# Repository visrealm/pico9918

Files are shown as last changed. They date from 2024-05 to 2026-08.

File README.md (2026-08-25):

# PICO9918

A drop-in replacement for a classic TMS9918A VDP powered by the Raspberry Pi Pico RP2040 (and RP2350) microcontroller.

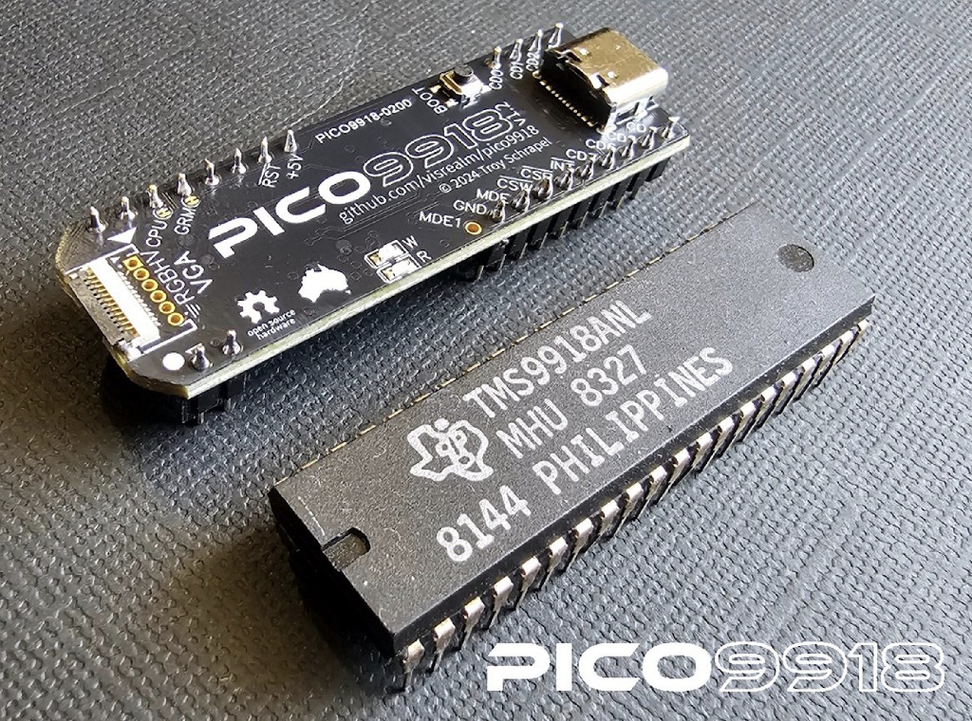
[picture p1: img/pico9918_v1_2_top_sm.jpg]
PICO9918 v1.2 Top
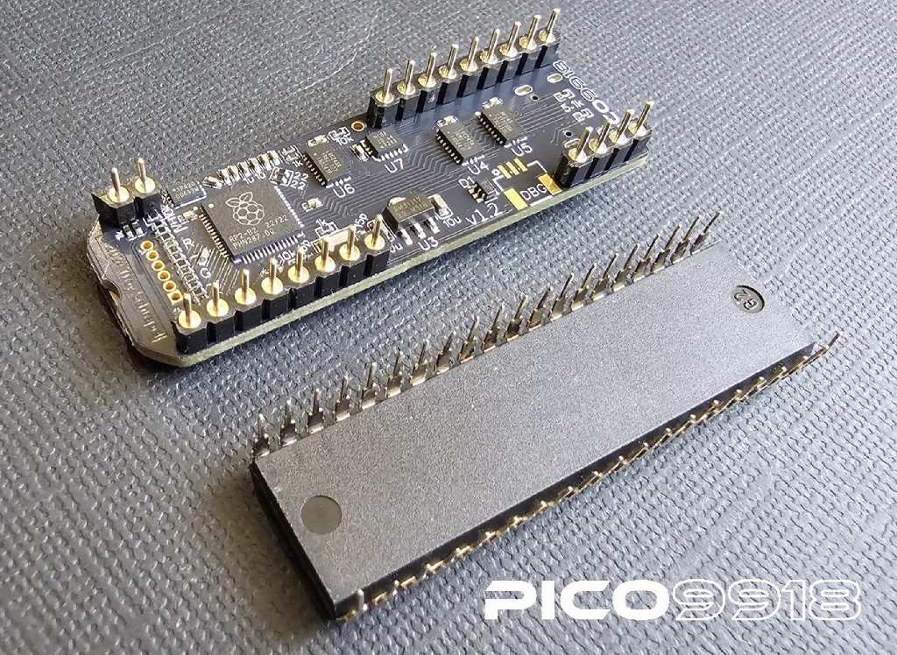
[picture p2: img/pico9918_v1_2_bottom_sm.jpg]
PICO9918 v1.2 Top
<p align="left"> </p>

The PICO9918 PRO can replace all classic VDP models (TMS9918, TMS9918A, TMS9928A, TMS9929A, TMS9118, TMS9128, TMS9129), providing a crisp VGA, HDMI or SCART RGB signal from your retrocomputer.

The PICO9918 has been tested on over 30 classic models of TI-99, Coleco, MSX, NABU, Memotech, Sega and many more. See the [full list below](#supported-devices).

The TMS9918A emulation is handled by my [vrEmuTms9918 library](https://github.com/visrealm/vrEmuTms9918) which is included as a submodule here.

## Contents

* [Supported devices](#supported-devices)
* [Video output](#video-output)
* [F18A compatibility](#f18a-compatibility)
* [Purchasing options](#purchasing-options)
* [Hardware](#hardware)
* [Firmware](#firmware)
* [Configurator](#configurator)
* [Roadmap](#roadmap)
* [Documentation](#documentation)
* [Building](#building)
* [Thanks](#thanks)
* [Discussion](#discussion)
* [Videos](#videos)
* [Licensing](#licensing)

## Supported devices

Every machine below has been tested and confirmed working. Each family has a wiki page with per-model notes, installation tips and configurator support.

| Family | Machines tested | Wiki page |
|---|---|---|
| [Texas Instruments TI-99](https://en.wikipedia.org/wiki/TI-99/4A) | TI-99/4, TI-99/4A, TI-99/4QI, TI-99/22 | [All models](https://github.com/visrealm/pico9918/wiki/Texas-Instruments-TI‐99) |
| [MSX](https://en.wikipedia.org/wiki/MSX) | 14 models from Casio, Gradiente, National, Sanyo, Sharp, Sony, Spectravideo, Toshiba and Yamaha | [All models](https://github.com/visrealm/pico9918/wiki/MSX) |
| [ColecoVision](https://en.wikipedia.org/wiki/ColecoVision) | ColecoVision, Coleco ADAM, AtariBits CV-NUC+, Bit Dina 2 in one | [All models](https://github.com/visrealm/pico9918/wiki/ColecoVision) |
| [Sega SG-1000](https://en.wikipedia.org/wiki/SG-1000#SC-3000) | SG-1000, SG-1000 II, SC-3000 | [All models](https://github.com/visrealm/pico9918/wiki/Sega-SG‐1000) |
| [Tomy Tutor](https://en.wikipedia.org/wiki/Tomy_Tutor) | Tomy Tutor, Pyūta, Pyūta Jr | [All models](https://github.com/visrealm/pico9918/wiki/Tomy-Tutor) |
| [VTech CreatiVision](https://en.wikipedia.org/wiki/VTech_CreatiVision) | CreatiVision, Dick Smith Wizzard | [All models](https://github.com/visrealm/pico9918/wiki/CreatiVision) |
| [NABU Personal Computer](https://en.wikipedia.org/wiki/NABU_Network) | NABU PC | [All models](https://github.com/visrealm/pico9918/wiki/NABU-Personal-Computer) |
| [Memotech MTX](https://en.wikipedia.org/wiki/Memotech_MTX) | MTX500 | [All models](https://github.com/visrealm/pico9918/wiki/Memotech-MTX) |
| [Sord M5](https://en.wikipedia.org/wiki/Sord_M5) | Sord M5 | [All models](https://github.com/visrealm/pico9918/wiki/Sord-M5) |
| [Powertran Cortex](http://powertrancortex.com/) | Cortex | [All models](https://github.com/visrealm/pico9918/wiki/Powertran-Cortex) |
| Homebrew | Troy Schrapel's [HBC-56](https://github.com/visrealm/hbc-56), Stuart Connor's [TM990](http://www.stuartconner.me.uk/tm990/tm990.htm), John Winans' [Z80-Retro](https://github.com/Z80-Retro), Martin's [Z80Ardu](https://www.dev-tronic.de/?p=74) | [All projects](https://github.com/visrealm/pico9918/wiki/Homebrew-Projects) |

Any other machine using a TMS9918, TMS9918A, TMS9928A, TMS9929A, TMS9118, TMS9128 or TMS9129 in a standard 40-pin DIP socket should also work. There are no known unsupported devices. If you have tested the PICO9918 on a machine that isn't listed, please let me know and I'll happily add it. :)

See the [Supported Devices](https://github.com/visrealm/pico9918/wiki/Supported-Devices) wiki page for the full breakdown, including which VDP each machine shipped with.

## Video output

One video pipeline, three ways out. Which one you get depends on the dongle you fit, and all three use the same 12-pin FFC cable, so one cable serves whichever dongle you have on.

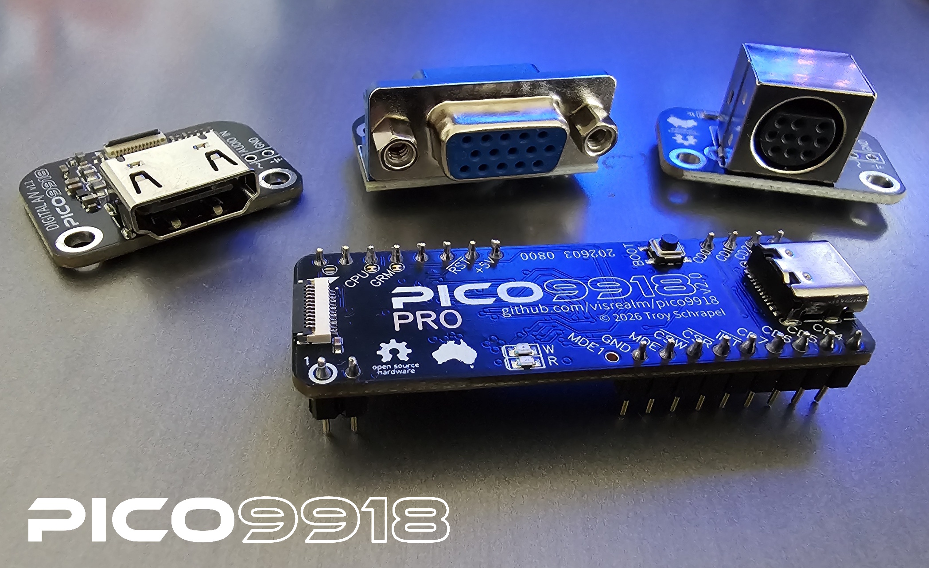
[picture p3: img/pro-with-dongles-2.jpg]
PICO9918 PRO with the Digital A/V, VGA and SCART RGB A/V dongles
<p align="left"></p>

| Output | Dongle | Signal | Audio |
|---|---|---|---|
| **VGA** | [VGA dongle](https://github.com/visrealm/pico9918/wiki/VGA-Dongle) (the default) | 640x480 @ 60 Hz progressive | No |
| **HDMI** | [Digital A/V dongle](https://github.com/visrealm/pico9918/wiki/Digital-AV-(HDMI)-Dongle) | 640x480 @ 60 Hz progressive | Yes, via two wires to the host mainboard |
| **SCART RGB** | [SCART A/V dongle](https://github.com/visrealm/pico9918/wiki/SCART-RGB-AV-Dongle) | PAL 576i @ 50 Hz, or NTSC 480i @ 60 Hz | Yes, via two wires to the host mainboard |

All three dongles fit any FFC-equipped board: **PRO v2.0**, **v1.3** and **v1.2**. On earlier integrated boards (v0.4 to v1.1) VGA comes off a 6-pin JST header on the board itself, and v0.3 has its own VGA breakout.

Nothing needs configuring for VGA or HDMI. A SCART dongle is detected automatically.

> [!NOTE]
> The SCART probe runs once, at boot, before video starts. Swapping dongles on a powered board will not change the output, so power the host off first.

See the [Display Output](https://github.com/visrealm/pico9918/wiki/Display-Output) wiki page for how the driver is chosen, how to change it safely, and the SCART timing details. For fitting the cable, see [Hardware Setup](https://github.com/visrealm/pico9918/wiki/Hardware-Setup#ffc-connector).

### No-cut installation

Every dongle needs a route out of the case. No-cut mods provide one without permanently modifying the machine, using 3D-printed parts and, on the TI-99/4A, a small PCB that replaces the original A/V DIN socket. Kits exist for the [TI-99/4A](https://github.com/visrealm/pico9918/wiki/TI‐99∕4A-No‐Cut-Mod), the CreatiVision and the NABU. STLs, gerbers and fitting photos are in [/nocut](nocut).

## F18A compatibility

The PICO9918 also includes F18A compatibility in firmware v1.0.0+. The video below was captured directly from the PICO9918 VGA output running various F18A demos on a TI-99/4A.

PICO9918 F18A mode preview 1 demo (https://youtu.be/TabTIPL1xQY)

For technical details on the enhanced registers, ECM, GPU, and palette RAM, see the [F18A Programmer's Reference](https://github.com/visrealm/pico9918/wiki/F18A-Programmers-Reference) wiki page.

## Purchasing options

Fully assembled and tested PICO9918 PROs are available here:

| Link | Store | Best For |
|---|---|---|
|  | Lectronz (visrealm) | All regions. Best choice for EU |
|  | Tindie (visrealm) | All regions |
|  | Arcade Shopper | US |

## Hardware

There are three main variants of the hardware.

### PRO v2.x (v2.0)

This is the latest version, powered by the more powerful RP2350. This hardware upgrade will allow for additional VRAM and display modes in the future, including V9938 support.

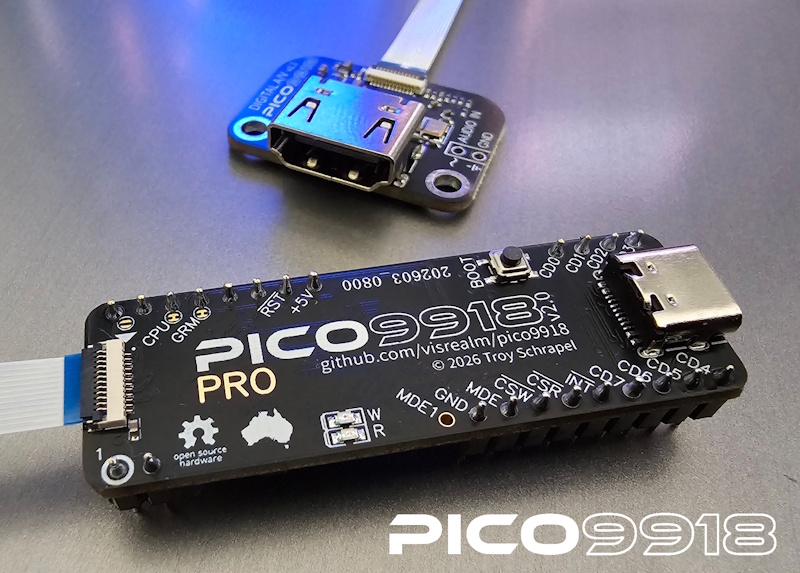
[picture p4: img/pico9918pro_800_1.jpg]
PICO9918 PRO v2.0
<p align="left"></p>

This is the version you can currently buy pre-assembled from Tindie and ArcadeShopper.

### v1.x (v1.3, v1.2, v1.1, v1.0 and v0.4)

PICO9918 v1.3 was the first single board version which doesn't require a piggy-backed Pi Pico.

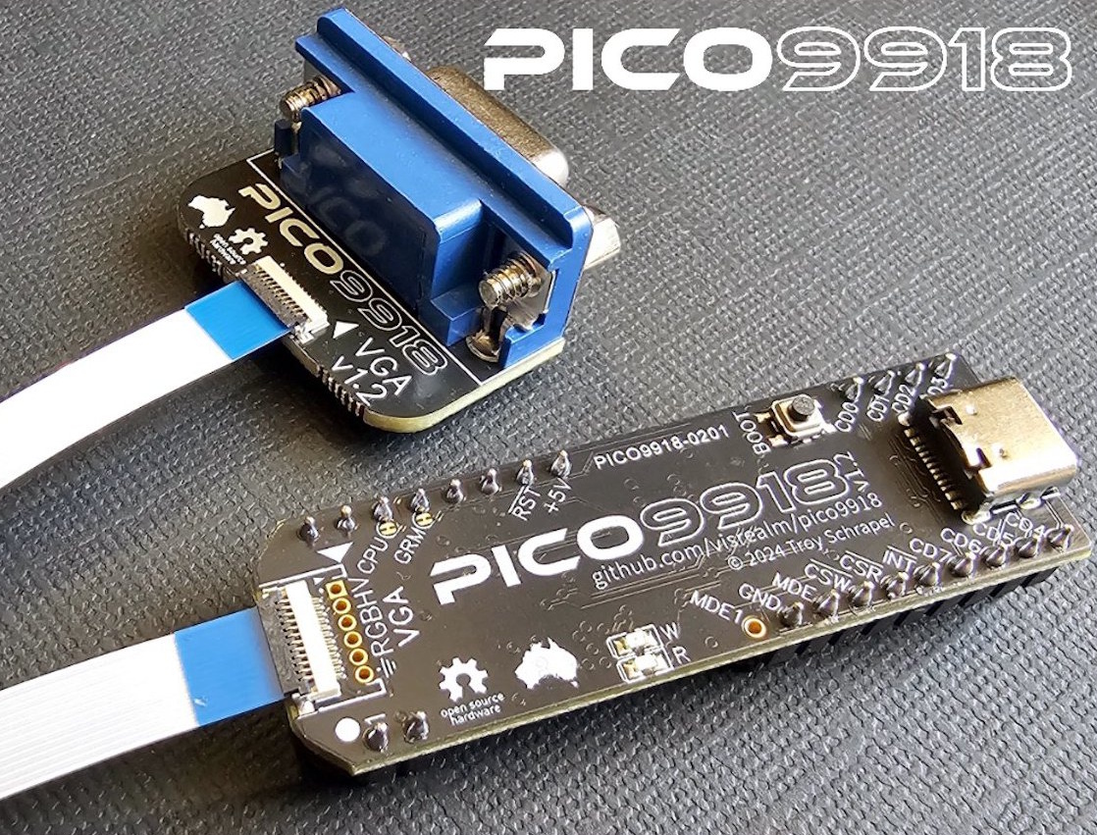
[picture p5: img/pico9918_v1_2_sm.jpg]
PICO9918 v1.2
<p align="left"></p>

### v0.3

v0.3 is relatively cheap and easy to build, schematic and gerbers are available. This version makes use of an external Pi Pico module piggy-backed onto the PICO9918 PCB.

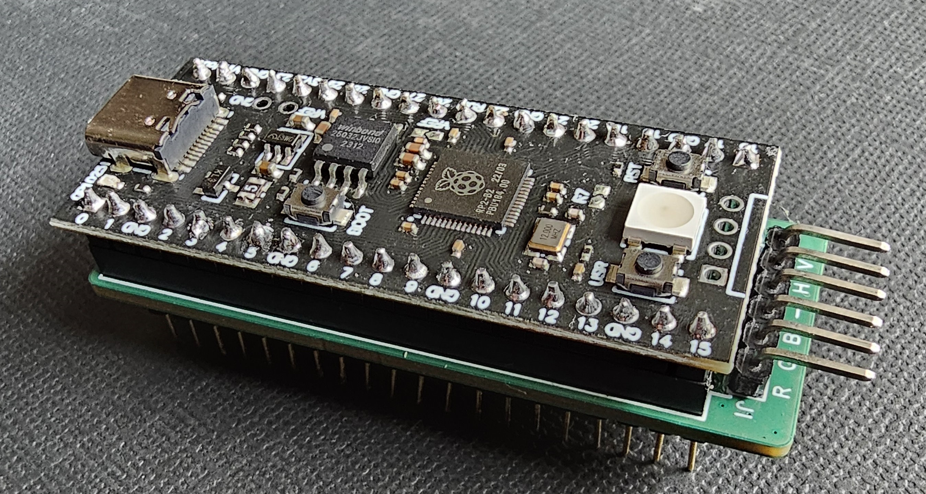
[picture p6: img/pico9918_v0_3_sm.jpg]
PICO9918 v0.3
<p align="left"></p>

I also have the [v0.3 board as a PCBWay Project](https://www.pcbway.com/project/shareproject/PICO9918_Drop_in_replacement_for_the_classic_TMS9918A_family_of_VDPs_fc11359a.html) you can order there.

For detailed specifications and setup instructions, see the [Hardware](https://github.com/visrealm/pico9918/wiki/Hardware) and [Hardware Setup](https://github.com/visrealm/pico9918/wiki/Hardware-Setup) wiki pages.

### Schematics

Schematics and Gerbers are available in [/pcb](pcb)

## Firmware

If you're not interested in building the firmware yourself, you'll find the latest firmware in the [Releases](https://github.com/visrealm/pico9918/releases).

To install, just hold the 'BOOT' button while plugging the Pico into a PC, then drag the pico9918.uf2 file on to the new USB drive which should have the volume label RPI-RP2. The Pico will restart (and disconnect) automatically.

For detailed information on firmware installation, output modes, and updates, see the [Firmware](https://github.com/visrealm/pico9918/wiki/Firmware) wiki page. For what changed in each release, see [CHANGELOG.md](CHANGELOG.md).

## Configurator

The configurator is a software tool used to modify PICO9918 configuration options, including:

* Clock rate
* Scanline CRT effect
* Scanline sprite limit
* Default palette
* [Diagnostic overlays](https://github.com/visrealm/pico9918/wiki/Diagnostic-Overlays)

Additionally, firmware updates can be provided via the Configurator. The full configurator is available for the **TI-99/4A**, **ColecoVision** and **MSX**. With cut-down builds (without firmware updates) available for several other machines.

For full details, see the [Configurator](https://github.com/visrealm/pico9918/wiki/Configurator) wiki page.

See the configurator in action:

PICO9918 Configurator - ColecoVision (https://youtu.be/PBArYupT9qM?t=9)

The configurator was written in a [custom fork of CVBasic](https://github.com/visrealm/CVBasic) with the full source available in [/configtool](configtool).

If you're not interested in building the configurator yourself, you'll find the latest builds in the [Releases](https://github.com/visrealm/pico9918/releases).

### Web-based Configurator

> [!TIP]
> No native configurator for your machine? The [Web-based PICO9918 Configurator](https://visrealm.github.io/pico9918/config/index.html) generates a config .uf2 file for both the PICO9918 and PICO9918 PRO. Drag and drop it onto your device the same way you would a firmware update.

## Roadmap

[ROADMAP.md](ROADMAP.md) sets out what is planned for the firmware and roughly in what order: host bus timing and compatibility fixes in v1.2.1, a rewritten tile pipeline and the extraction of the rendering core into a reusable library in v1.3.0, the remaining F18A behaviour gaps in v1.4.0, and V9938 support in v2.0.0. It also spells out what the version numbers mean, in particular that the configuration layout never changes on a patch release.

It is a direction rather than a commitment, and it deliberately carries no dates - items move between versions as work lands. Anything not listed is unscheduled rather than rejected, so if there is something you would like to see, open an issue and it can be considered. For what has already shipped, see [CHANGELOG.md](CHANGELOG.md).

## Documentation

Just fitted a board? Start with [Getting Started](https://github.com/visrealm/pico9918/wiki/Getting-Started). For everything else, covering hardware setup, firmware, the configurator, supported devices, F18A compatibility and more, visit the **[PICO9918 Wiki](https://github.com/visrealm/pico9918/wiki)**.

## Building

### Quick start
Build both firmware and configurator ROMs:

```bash
# Automatic SDK download (recommended)
mkdir build && cd build
cmake .. -DPICO_SDK_FETCH_FROM_GIT=ON -DPICO_SDK_FETCH_FROM_GIT_TAG=2.1.1
cmake --build .
```

Output in `build/dist/`: firmware `.uf2` file and configurator ROMs for all retro platforms.

Build settings can be overridden with `-D` flags or an optional, git-ignored `pico9918_config.cmake` in the project root - copy [`pico9918_config.cmake.template`](pico9918_config.cmake.template) to `pico9918_config.cmake` and edit it to get started. See [BUILDING.md](BUILDING.md).

### Platform-Specific Setup Required

Each platform requires specific toolchain installation:
- **Windows**: ARM GNU Toolchain 13.2.1-1.1, Python with pillow
- **Linux**: `build-essential cmake python3 python3-pip git gcc-arm-none-eabi`  
- **macOS**: Homebrew + ARM GNU Toolchain 13.2.1-1.1, may need `--break-system-packages`

All platforms use **Raspberry Pi Pico SDK 2.1.1** specifically (newer versions may cause issues).

### Detailed instructions

For detailed platform setup, development environment configuration, build options, individual platform builds, VSCode integration, and troubleshooting, see [BUILDING.md](BUILDING.md)

### Build status

| Branch | Build | Windows | Linux | macOS |
|---|---|---|---|---|
| main | Firmware |  |  |  |
| main | Configurator |  |  |  |
| dev | Firmware |  |  |  |
| dev | Configurator |  |  |  |

## Thanks

Special thanks to [JasonACT (AtariAge)](https://forums.atariage.com/profile/82586-jasonact/) for hand-crafting the F18A mode's on-board TMS9900 "GPU" in ARM assembly and providing other valuable input to the project.

## Discussion

For all the latest news and discussion on the PICO9918, you can follow [this AtariAge thread](https://forums.atariage.com/topic/367656-introducing-the-pico9918-a-tms9918a-drop-in-replacement-powered-by-a-pi-pico/)

## Videos

<details>
<summary><b>Early prototype videos</b> - the first boots, v0.2 through v0.4</summary>

The first three were recorded in the moments following the first boot on my TI-99/4A. They show v0.2 hardware, which needed an external Pi Pico to supply the TI-99's GROMCLK signal - that signal moved onto the board itself in v0.3.

### It freaking works!
PICO9918 Prototype - It freaking works (https://youtu.be/Ri09dCjWxGE)

### Don't mess with Texas!
PICO9918 Prototype - Don't mess with Texas (https://youtu.be/ljNRFKbOGJs)

### 80 column mode
PICO9918 Prototype - 80 column mode test (https://youtu.be/qdCapu0CVJ8)

### v0.4 prototype working!
The first single board version, with the RP2040 integrated.

PICO9918 v0.4 PCB. Integrated RP2040 all-in-one build. (https://youtu.be/KSbJnAwclQw)

</details>

## Licensing

### Hardware
The hardware design files in this repository are licensed under the CERN-OHL-S. See [LICENSE_HARDWARE.md](LICENSE_HARDWARE.md) for details.

### Firmware
The firmware code in this repository is licensed under the MIT License. See [LICENSE_FIRMWARE.md](LICENSE_FIRMWARE.md) for details.

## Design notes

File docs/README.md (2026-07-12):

# PICO9918 Documentation

[&larr; Back to PICO9918](../README.md)

## Contents

* [FFC Connector](#ffc-connector)
* [CPU and GRM Jumpers](#cpu-and-grm-jumper)
* [MDE1 Pin](#mde1-pin)

---

## FFC Connector

The FFC (Flat Flexible Cable) connector on the PICO9918 v1.2+ is used to attach accessories such as the VGA or [Digital A/V dongle](../README.md#digital-av-hdmi-dongle-new).

If you're ordering replacement cables from a thirdparty, look for 12 pin 0.5mm pitch FFC cables.

### Connecting the FFC Cable

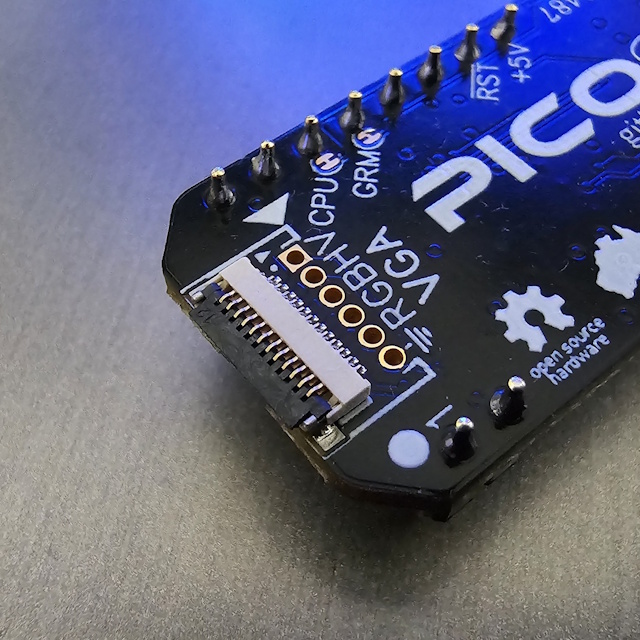
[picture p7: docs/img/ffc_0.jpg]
FFC connector - open latch


**Step 1** - Open the FFC connector latch by lifting the locking tab upward.

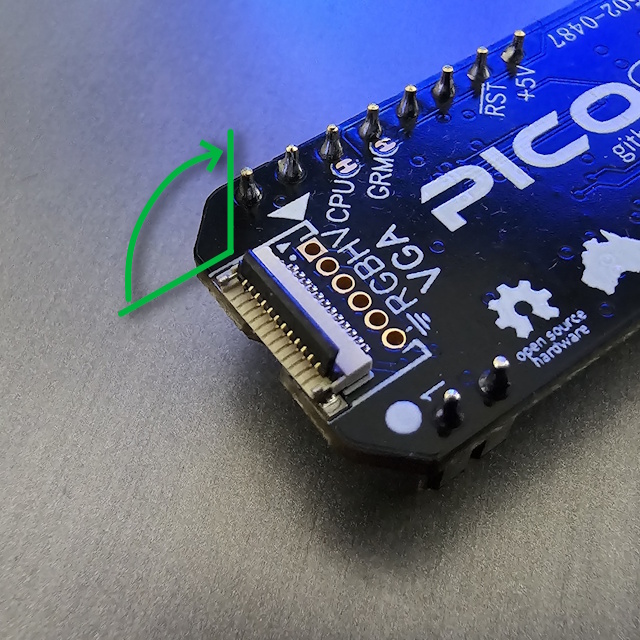
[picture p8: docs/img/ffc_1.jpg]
FFC connector - insert cable


**Step 2** - Insert the FFC cable into the connector with the contacts facing down.

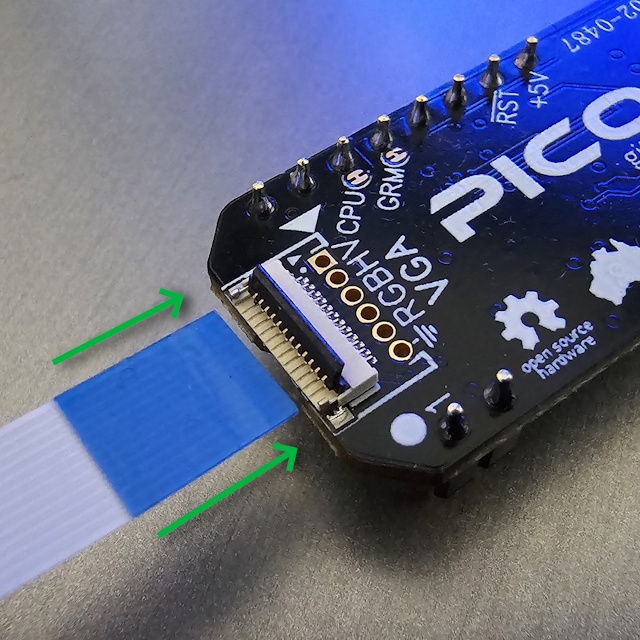
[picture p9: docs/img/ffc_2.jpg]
FFC connector - cable seated


**Step 3** - Push the cable fully into the connector until it seats flush.

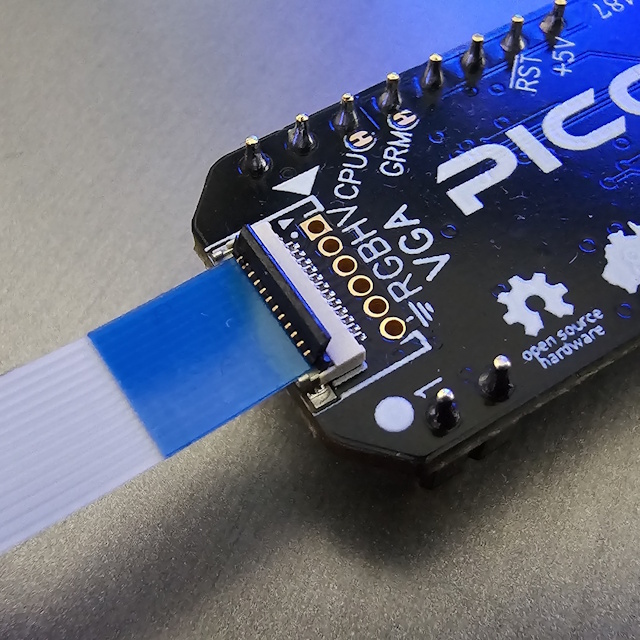
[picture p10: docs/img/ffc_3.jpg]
FFC connector - close latch


**Step 4** - Close the latch by pressing the locking tab back down until it clicks.

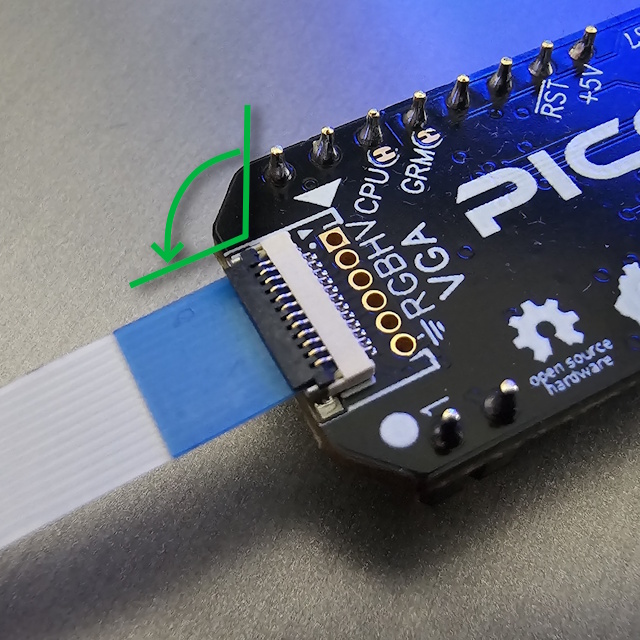
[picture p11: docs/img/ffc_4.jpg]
FFC connector - secured


**Step 5** - Confirm the cable is secure and the latch is fully closed.

---

## CPU and GRM Jumper

The PICO9918 v1.x boards include solder jumpers for configuring the CPU clock and GRM clock outputs. In some cases, it might be necessary to cut  the CPU jumper to ensure compativility with TMS992xA devices. One example being to use the ColecoVision Expansion module 1 with your ColecoVision.

### Cutting a jumper

The CPUCLK and GROMCLK jumpers are located on the board as shown below.

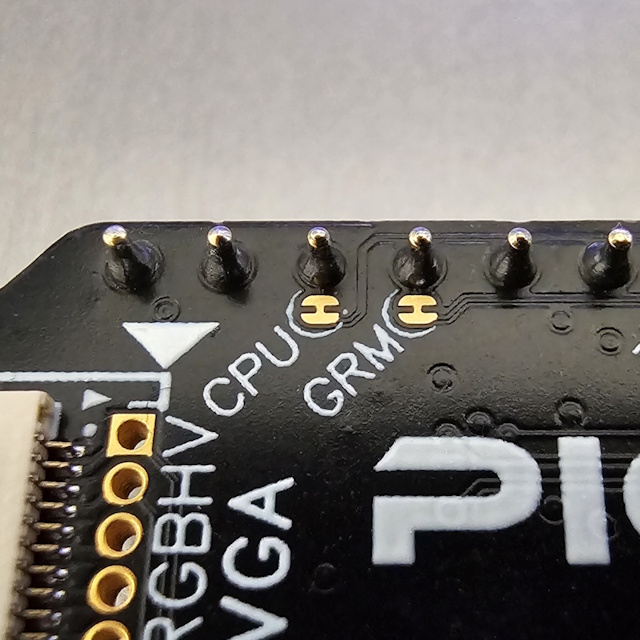
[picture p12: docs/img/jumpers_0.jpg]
PICO9918 jumpers


Using a sharp hobby knife, position the blade across the jumper trace you wish to cut.

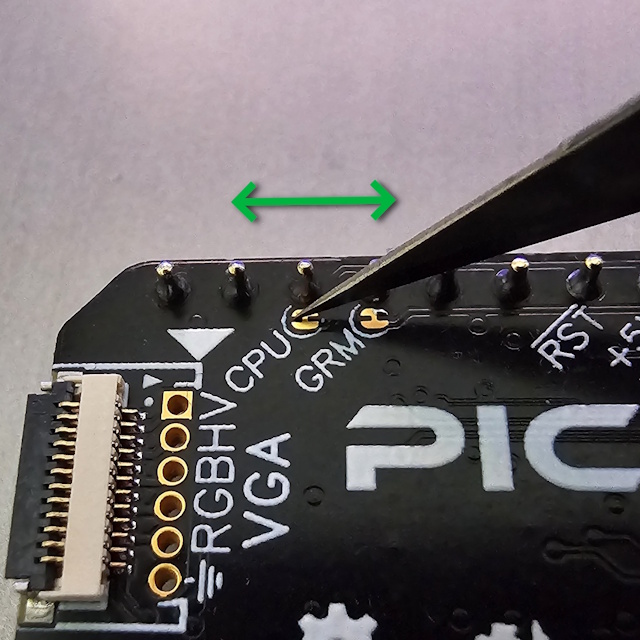
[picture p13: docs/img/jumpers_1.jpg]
Blade positioned against jumper


Apply firm pressure to cut through the trace. Use a multimeter to confirm the jumper is fully open.

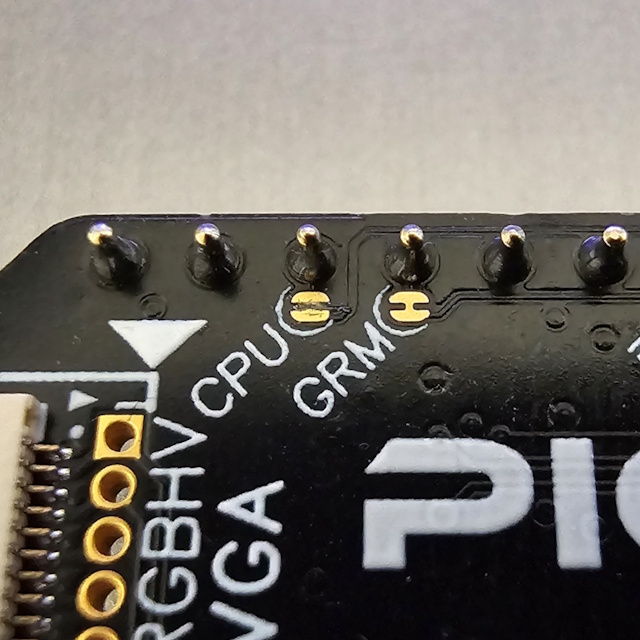
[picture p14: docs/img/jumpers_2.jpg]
Cut jumper


### Replacing a jumper

To re-connect a cut jumper, apply a small solder blob onto the pad.

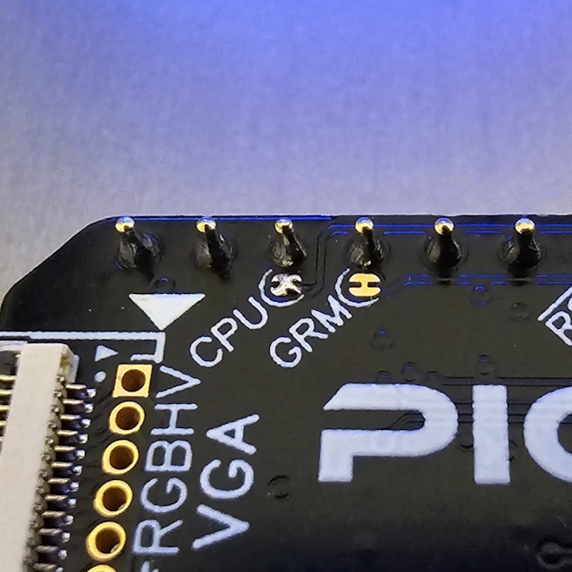
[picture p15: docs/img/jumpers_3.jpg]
Replaced jumper


---

## MDE1 Pin

One side of the PICO9918 v1.x includes 10 holes, but shipped units come with a 9-pin header installed. The unpopulated hole is reserved for the **MDE1** (Mode 1) pin.

MDE1 is not currently used by the firmware but is included on the board for future expansion - for example, to support V9938 and other enhanced VDP variants which make use of this pin.

---

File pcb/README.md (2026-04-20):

# PICO9918 PCBs

Here you will find schematics and gerbers for all working revisions of the PICO9918. There are three main variants of the hardware. 

### DIY Piggybacked board (v0.3)

This version is relatively cheap and easy to build and is powered by a piggybacked Pi Pico USB-C module. Recommended for a DIY project.

<p align="left">PICO9918 v0.3</p>

See [PICO9918 v0.3](v0.3)

### Fully integrated RP2040 single board (v0.4 - v1.3)

From v0.4 the RP2040 has been integrated onto the PICO9918 PCB, making a much smaller small form factor. This revision has many small (0402) components and can be challenging (and more expensive) to build. They can be purchased too.

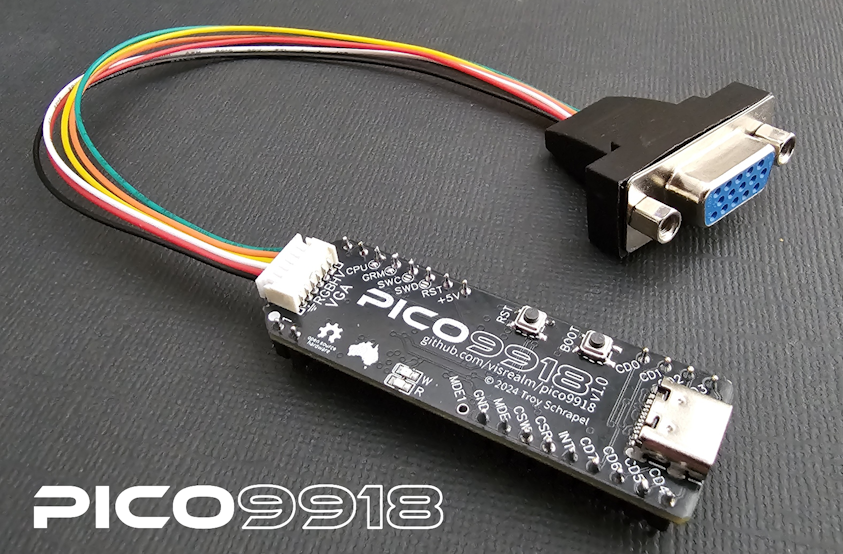
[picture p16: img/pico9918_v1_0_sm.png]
PICO9918 v1.0
<p align="left"></p>

### Fully integrated RP2350 single board (PRO v2.0+)

With the introduction of the RP2350, the PICO9918 v2.0 "PRO" was produced to take advantage of the much improved instruction set.

For a detailed changelog covering all versions, see the [revision history](#revision-history) below.

# Dongles

From v1.2 onwards, the PICO9918 exposes its video output over a 12-pin FFC interface, allowing different output dongles to be connected.

<p align="left"><a href="../img/pro-with-dongles-2.jpg">PICO9918 PRO with dongles</a></p>

## [VGA dongle v1.2](vga)

The standard VGA output dongle. Provides a DE-15 VGA connector.

## [HDMI dongle v1.1](hdmi)

Digital AV dongle providing HDMI output with optional audio.

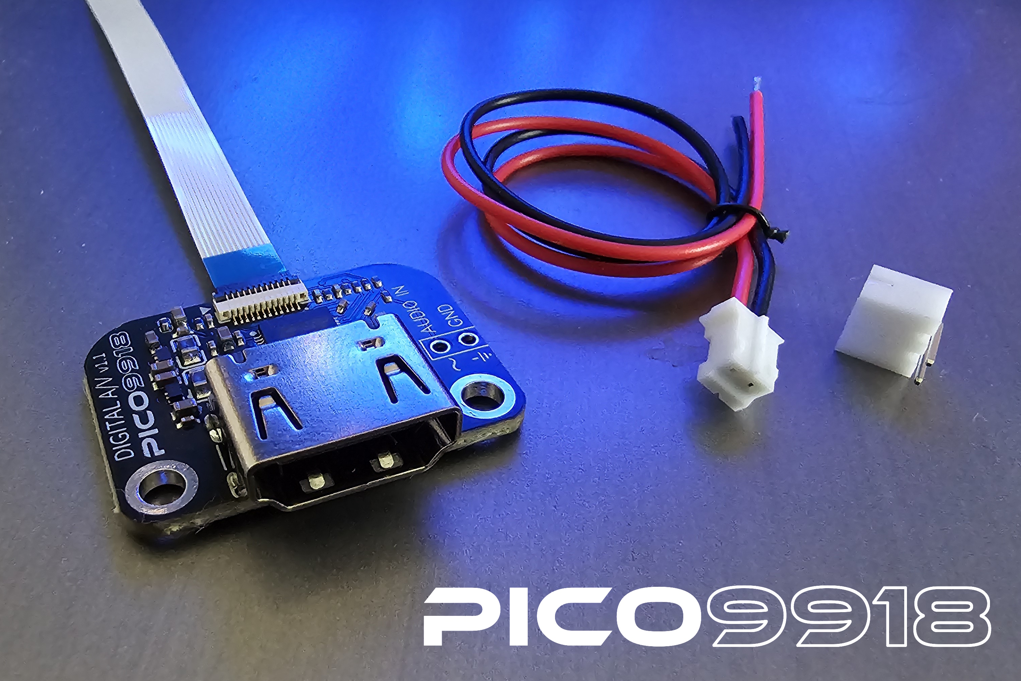
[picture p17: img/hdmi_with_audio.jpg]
PICO9918 HDMI dongle
<p align="left"></p>

## [SCART dongle v1.3](scart)

SCART RGBs output dongle supporting PAL and NTSC timing, with optional audio.

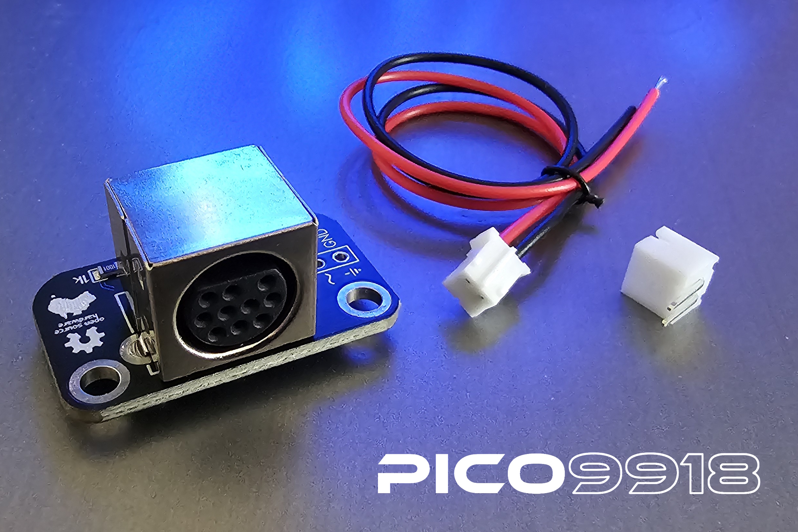
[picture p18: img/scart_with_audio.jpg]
PICO9918 SCART dongle
<p align="left"></p>

# Revision history

## [PRO v2.0 (2026-03-09)](v2.0)

<p align="left"><a href="../img/pico9918pro_800_1.jpg">PICO9918 PRO v2.0</a></p>

### Changelog
- Switched from RP2040 to RP2354A (RP2350 with integrated flash).
- Removed Winbond 16mbit flash.
- Switched from dual transceiver data I/O to single transceiver.
- Additional power filtering to FFC interface to improve HDMI dongle power delivery.
- Added optional BOOTSEL pin on FFC interface.
- Many routing improvements.

## [v1.3 (2025-07-02)](v1.2)

### Changelog
- Added LM66200 dual perfect diode to allow connecting USB while installed.
- Replaced 74HC08 with a 74ACT126 to make data and interrupt lines float on reset.
- Data lines remain active slightly longer after /CSR goes high.

## [v1.2 (2024-11-26)](v1.2)

<p align="left"><a href="../img/pico9918_v1_2_sm.jpg">PICO9918 v1.2</a></p>

### Changelog
- Added 12-pin FFC connector with separate VGA dongle PCB

## [v1.1 (2024-09-12)](v1.1)

### Changelog
- Removed reset button.
- Default CPUCLK and GROMCLK jumper pads to closed.
- Minor positioning adjustments of bottom-side resistors to clear header pins.

## [v1.0 (2024-08-01)](v1.0)

First version available for sale on Tindie and ArcadeShopper

<p align="left"><a href="../img/pico9918_v1_0_sm.png">PICO9918 v1.0</a></p>

### Changelog
- Added reset button.
- Moved CPUCLK and GROMCLK jumper pads to the top of the board.
- Added SWD and SWC jumper pads to allow SWD (debugging)
- Flipped top labels and graphics so it doesn't look upside-down.

## [v0.4 (2024-07-16)](v0.4)

This is the first fully-integrated single-board version and is powered by an RP2040 directly. This version was never released, however I hand-built 9 of them and sent most of the to various retro enthusiasts from AtariAge.

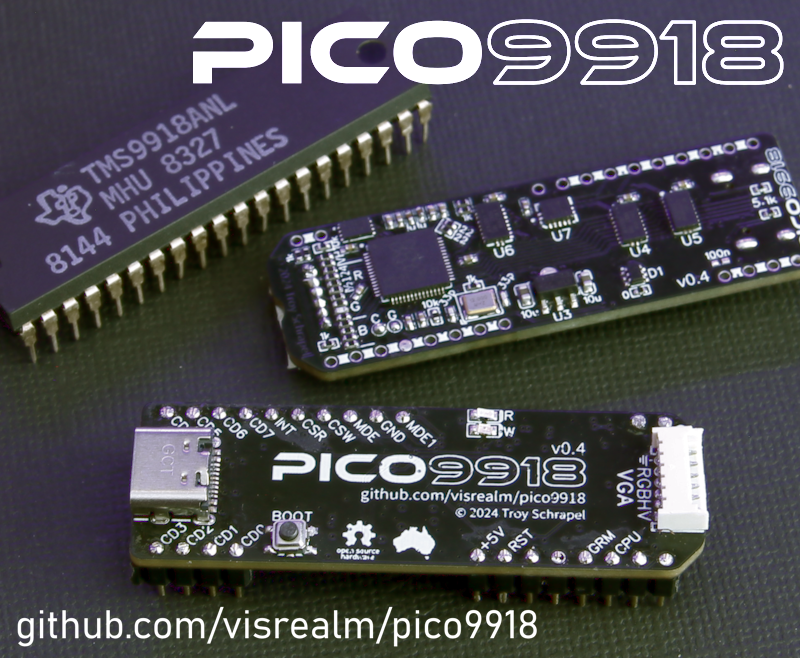
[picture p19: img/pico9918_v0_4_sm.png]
PICO9918 v0.4
<p align="left"></p>

### Changelog
- Removed piggy backed Pi Pico module.
- Added RP2040 and all of its dependencies.
- Switched out resisitor networks for discrete resistors.
- Shrinkified the package to something resembling the first version for sale (v1.0).
- Updated VGA connector to 6p 1.25mm JST.

## [v0.3 (2024-06-07)](v0.3)

This is the first "public" version and is powered by a piggy-backed USB-C Pi Pico module. I have never produced or sold this version beyond the initial few prototypes.

<p align="left">PICO9918 v0.3</p>

### Changelog
- Switched to use USB-C Pi Pico module instead of genuine Pi Pico.
- Added CPUCLK and GROMCLK.

### PCB v0.3 Notes

There are a number of 0 Ohm resistors (jumpers). You may need to omit the RST resistor. On some machines, the extra time is required to bootstrap the Pico. This will be changed to a soft reset on v0.4.

### Raspberry Pi Pico Module

Note: Due to GROMCLK and CPUCLK using GPIO23 and GPIO29, a genuine Raspberry Pi Pico can't be used. v0.3 of the PCB is designed for the DWEII? RP2040 USB-C module which exposes these additional GPIOs. A future pico9918 revision will do without an external RP2040 board and use the RP2040 directly.

Purchase links:
 * https://www.amazon.com/RP2040-Board-Type-C-Raspberry-Micropython/dp/B0CG9BY48X
 * https://www.aliexpress.com/item/1005007066733934.html

I could reduce the VGA bit depth to 9-bit or 10-bit to allow the use of a genuine Raspberry Pi Pico board, but given the longer-term plan is to use the RP2040 directly, I've decided to go this way for the prototype.

## What happened to v0.1 and v0.2?

For the curious amongst you, v0.1 was the only version that wan't usable. The TMS9918A socket interface was 0.1" too narrow. Rookie error! Fortunately, I noticed within hours of ordering the PCBs, so ordered v0.2 long before v0.1 arrived.

v0.2 was very usable and is the version used in the initial "It freaking works!" video. The only reason it isn't published is because it lacked the GROMCLK and CPUCLK signals required for many systems. In the video, you can see the GROMCLK signal is being provided by a second Pi Pico.

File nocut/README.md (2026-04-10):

## PICO9918 no-cut mods

No-cut mods allow you to install a PICO9918 without making any permanent modifications to the case of your retro computer. Each mod provides 3D-printable parts (and in some cases a custom PCB) to cleanly route the PICO9918's video and audio connectors through the rear panel.

### Supported systems

| System | Details |
|---|---|
| [TI-99/4A](ti99/) | Custom PCB and 3D-printed enclosure replacing the A/V DIN socket |
| [CreatiVision](creativision/) | 3D-printed rear panel cover with VGA/RCA cutouts |
| [NABU](nabu/) | 3D-printed rear panel cover with VGA or HDMI cutouts (with optional USB boot access) |

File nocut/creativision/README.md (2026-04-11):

## CreatiVision no-cut mod

The no-cut mod for the CreatiVision consists of 3D-printable parts which replace the rear panel cover, allowing the PICO9918's VGA and RCA connectors to pass through.

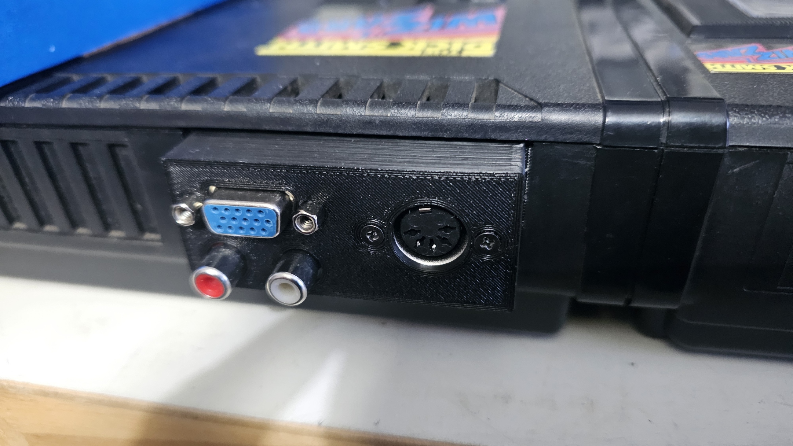
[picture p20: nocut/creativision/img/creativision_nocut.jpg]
creativision no cut


### 3D Printed Parts

There are two STL files:

- **[pico9918-nocut-creativision-vga.stl](stl/pico9918-nocut-creativision-vga.stl)** - Rear panel cover with VGA cutout
- **[pico9918-nocut-creativision-vga-rca-cover.stl](stl/pico9918-nocut-creativision-vga-rca-cover.stl)** - Internal RCA cover

See [stl/](stl/)

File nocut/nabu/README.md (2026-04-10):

## NABU no-cut mod

The no-cut mod for the NABU consists of 3D-printable parts which replace the rear panel cover, allowing the PICO9918's video and USB boot connectors to pass through.

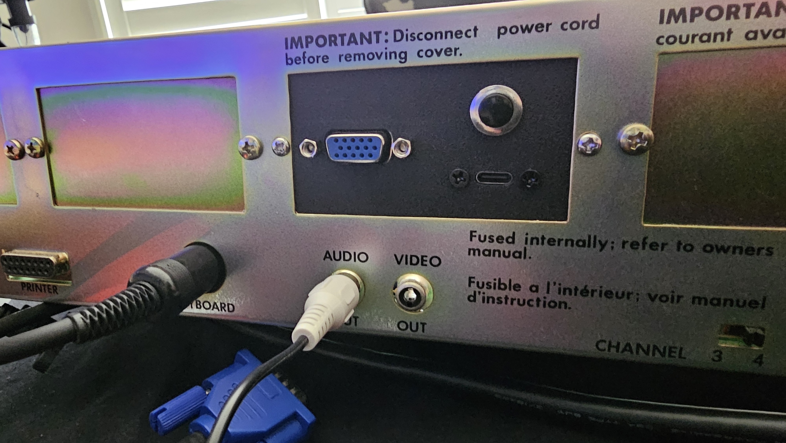
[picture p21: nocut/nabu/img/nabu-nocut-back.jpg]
nabu no cut back


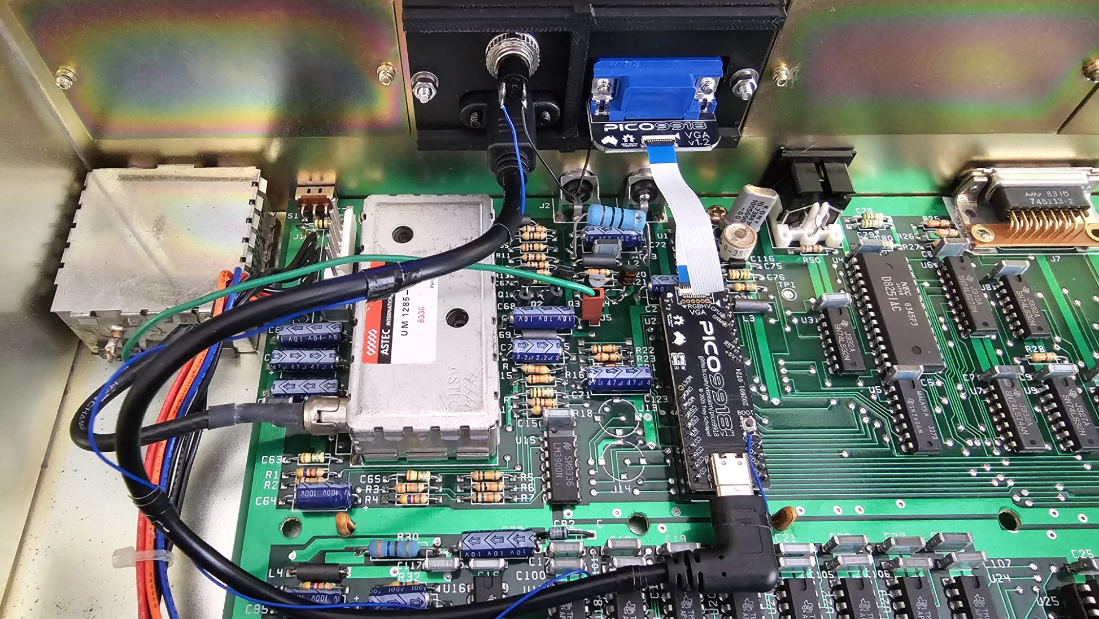
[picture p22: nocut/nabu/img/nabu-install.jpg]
nabu install


### 3D Printed Parts

There are four STL files to cover different output and connector configurations:

- **[pico9918-nocut-nabu-vga.stl](stl/pico9918-nocut-nabu-vga.stl)** - Rear panel cover with VGA cutout
- **[pico9918-nocut-nabu-vga-usb-boot.stl](stl/pico9918-nocut-nabu-vga-usb-boot.stl)** - Rear panel cover with VGA and USB boot cutouts
- **[pico9918-nocut-nabu-hdmi.stl](stl/pico9918-nocut-nabu-hdmi.stl)** - Rear panel cover with HDMI cutout
- **[pico9918-nocut-nabu-hdmi-usb-boot.stl](stl/pico9918-nocut-nabu-hdmi-usb-boot.stl)** - Rear panel cover with HDMI and USB boot cutouts

See [stl/](stl/)

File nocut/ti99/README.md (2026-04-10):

## TI-99/4A no-cut mod

The no-cut mod for the TI-99/4A consists of a custom PCB which replaces the original A/V DIN socket:

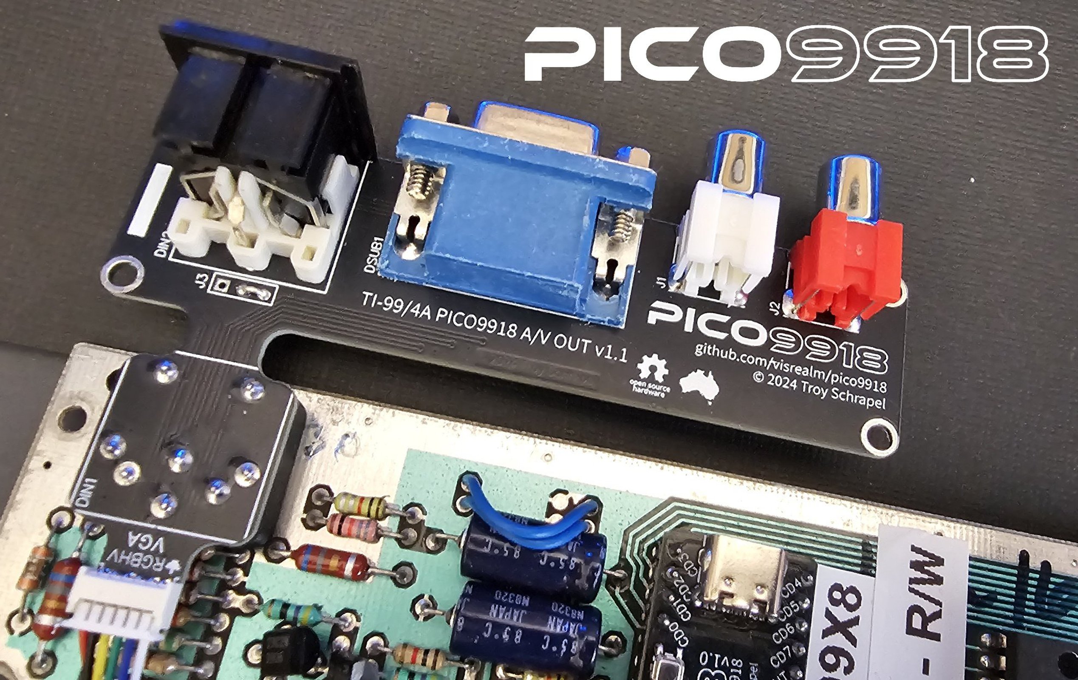
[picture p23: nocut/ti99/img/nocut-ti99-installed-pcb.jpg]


The PCB is the supported by the printed enclosure:

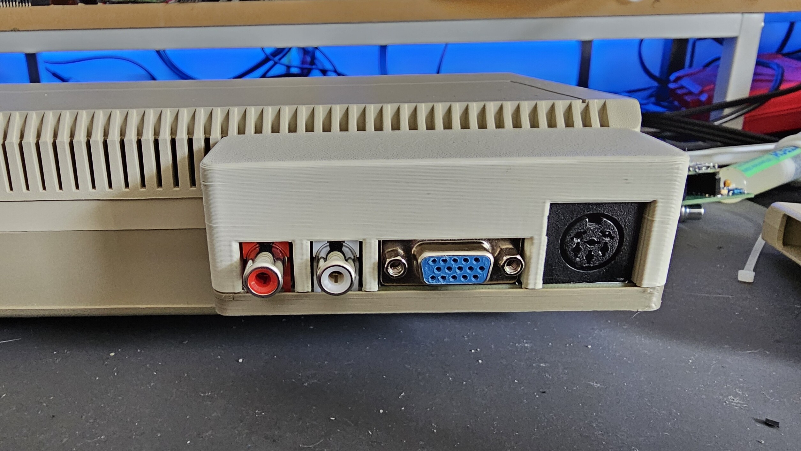
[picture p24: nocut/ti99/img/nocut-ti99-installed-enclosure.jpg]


### PCB

There is now a single PCB (v1.3) for both JST and FFC connector types.

#### Configuration

The 5P/6P jumper is used to connect the correct DIN pin to the ground plane of the no-cut PCB. For 5-pin DINs (most US models), place a jumper between the 5P and middle pin. For 6-pin DINs (most EU/AUS models), place a jumper between the 6P and middle pin.
You can run the board with no jumper at all however the ground for the audio connectors will then be provided via the PICO9918 cable.

See [pcb/](pcb/)

To install the PCB:
1. Print and assemble the PCB spacer.
   - Print the 3D printed spacer: [stl/pico9918-nocut-ti99-pcb-spacer.stl](stl/pico9918-nocut-ti99-pcb-spacer.stl)
   - Print 2x copies of the assembly spacer jig: [stl/pico9918-nocut-ti99-pcb-spacer-jig.stl](stl/pico9918-nocut-ti99-pcb-spacer-jig.stl)
   - Insert 8x standard dupont pins from a male pin header into the spacer's 8x holes.
   - Using the assembly jigs on either side of the spacer, clamp the entire assembly together in a vice. This will space the pins centrally in the spacer.
2. Fit and solder the spacer assembly to the BOTTOM side of the no-cut PCB's DIN1 socket.
3. Desolder and remove the A/V connector from your TI-99/4A main board.
4. Fit and solder the original A/V connector to the TOP side no-cut PCB DIN2 socket.
5. Fit and solder the entire no-cut assembly to your TI-99/4A main board via the spacer.

### Enclosure

The vent holes on the black versus beige TI-99/4As are slightly different. For that reason, find either the beige or black version of the enclosure top and the generic enclosure bottom. They should be printed like this:

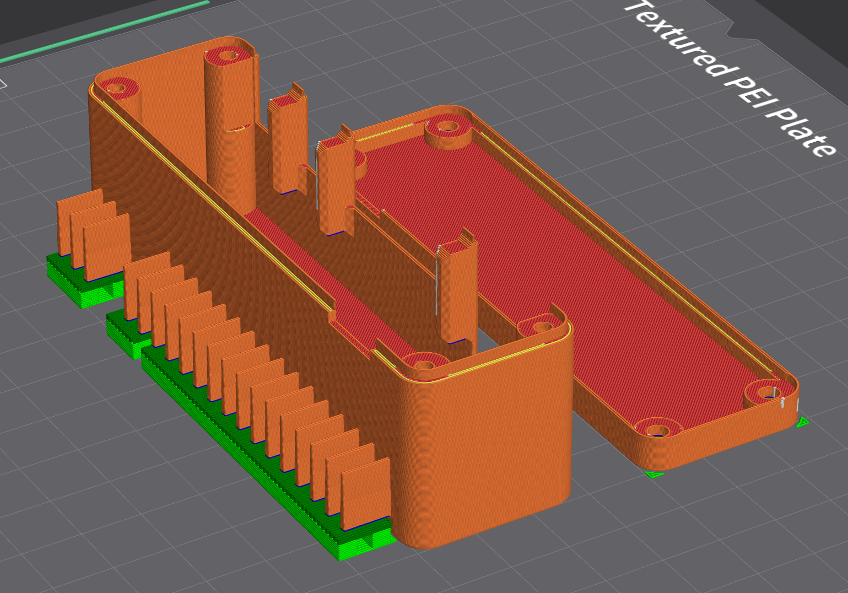
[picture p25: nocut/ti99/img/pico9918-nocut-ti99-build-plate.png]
ti99 no cut print layout


The case is held together with 4x screws. The screw hole diameter is 2.4mm (3/32"). I use 4G x 3/8 self-tapping screws, but there is some flexibility in screw sizes.

See [stl/](stl/)

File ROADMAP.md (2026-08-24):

# Roadmap

What is planned for the PICO9918 firmware, and roughly in what order. Shipped versions are in
[CHANGELOG.md](CHANGELOG.md); the full notes for each live on
[Releases](https://github.com/visrealm/pico9918/releases).

This is a direction, not a commitment. Dates are deliberately absent: items move between versions
as work lands. Anything not listed here is unscheduled, which is not the same as rejected - open an
issue and it can be considered.

**Versioning.** Patch releases carry bug fixes only, minor releases carry backwards-compatible
features, major releases carry breaking changes. For firmware, "breaking" means a config format
change or a hardware behaviour change that would surprise a user. **The config layout cannot change
on a patch release**: a release that claims a new config byte is a minor at minimum.

## v1.2.1 - host bus timing and compatibility

A maintenance release, focused on the host interface. Several reports of intermittent failures on
specific machines trace back to how the write cycle is entered and when `MODE` is sampled.

* Reject glitches on the `/CSW` falling edge before accepting a write cycle.
* Sample `MODE` at the `/CSW` falling edge rather than after it, and act on the sampled value
  rather than re-reading the pin.
* Drive the read bus before the settling check, and shorten the write entry window.
* Pin the host interface to a fixed PIO rate, independent of the system clock, and move the clock
  state machines to `pio0`.
* Reset palette mode on a status read.
* Correct the position-based tile attribute address.
* Build a configurator for a single target rather than always both, halving ROM size where only one
  board is in use.
* Lite (settings-only) configurator ROM for the CreatiVision.

## v1.3.0 - the tile pipeline rewrite, and pico9918-core

The largest F18A release since F18A support landed. Every display mode now runs through one
shared tile pipeline instead of carrying its own special case, so features that previously
existed in only some modes exist in all of them. The shared path is also *faster* than the
per-mode code it replaced, which is the unusual part: the features came for free.

* Tile layer 2 in every mode, the text modes included.
* Horizontal and vertical scrolling in every mode.
* Enhanced Color Mode in every mode.
* An 8bpp 80-column tier, and unlocked 80-column text rendered a byte a pixel.
* Holes closed along the way: the backdrop and 40-column text take the tile palette select, a
  text cell above an ECM0 layer draws as the ECM tile it is, and text no longer takes a
  vertical page swap the hardware never applies.

Performance, despite all of the above:

* Graphics II, Multicolor and both text modes fold into the shared pipeline behind one address
  generator, specialised at compile time rather than branched at run time.
* The composite step is skipped where there is nothing to arbitrate.
* Cold code and data stay resident in flash rather than RAM, via linker sections and an
  explicit reachability rule, freeing RAM for the renderer.
* Driven by measurement throughout: several changes were reverted for costing more than they
  returned.

The instruments that made it measurable, and that the core extraction then depends on:

* An on-hardware scene runner that replays VDP RAM dumps captured from real F18A software, a
  recorded performance timeline so frame time is a series across releases rather than a
  judgement made once, and a benchmark ROM.

Then the core extraction, gated on the measurement above. Its acceptance criterion is that the
picture and the frame time are unchanged.

* Rendering, GPU, configuration semantics and the splash and diagnostics overlays move out of
  the firmware. The firmware keeps only what is genuinely hardware: the PIO host interface,
  VGA, flash, GPIO, temperature and clocks.
* The library moves in-tree and is published as `pico9918-core`, a generated repository, for
  use by emulators. It is no longer a submodule.
* The configurator's config-byte table is generated from the firmware's, ending a layout that
  was independently declared in four places and had already drifted.
* Fix the config byte that had two owners: CRT scanlines and the render-base selector were the
  same byte, so enabling scanlines also switched the render base.
* Every DMA channel is claimed, so a collision panics at boot instead of corrupting the
  display.
* `clang-format` and Doxygen across the firmware and the library, dead code removed, and the
  stale build and debugging documentation corrected.
* Continuous integration building both targets on Linux, macOS and Windows, with the library's
  standalone build as the boundary gate.

## v1.4.0 - F18A compliance

Close the remaining gaps where PICO9918 does not match real F18A behaviour, so that F18A
software runs unmodified. The display-mode gaps were largely closed by the pipeline work in
v1.3.0; what is left is register semantics, status and the GPU.

* S15 returns the value of a register addressed by a read setup, reconstructed rather than
  returned raw. That is the only register read-back path the hardware offers.
* Locked writes above R7 are masked to three bits rather than ignored, and a non-unlock write
  to R57 re-locks.
* R30 is stored as the five bits the hardware has, and R30 = 0 restores the configured default
  rather than a fixed 31.
* R50 bit 2 (simulated scanlines) is acted on, and R7's power-on default matches.
* The timing counters sample correctly and no longer corrupt the start time.
* Tile layer 2 and tile-layer-1 disable stop being gated away on the 4bpp tier.
* Drop the resident GPU program image, which cannot function without the SPI flash the F18A
  had, and whose reachable handlers write into the status register the host polls.
* Correct the GPU's DMA trigger clear, which zeroes a byte it should leave alone.

Not in scope: the GPU's 7-bit user status at `0xB000` is on hold, and several F18A GPU
facilities (VRAM mirroring, the MPU register-page guard, the nanosecond counter pair) are
recorded as unsupported by choice.

## v2.0.0 - the V9938

The major version is the new VDP. With the core library already in place, this release adds a base
underneath the F18A the same way the TMS9918A sits there today.

* V9938 as a selectable base: 128 KB VRAM, the `GRAPHIC3` through `GRAPHIC7` renderers, interlace,
  R#14 through R#23, and the V9938 status bits.
* Four-port host decode, on PCB v0.4 and later only.
* The V9938 command engine.

Hard constraint, carried from v1.3.0: no per-scanline path may get slower. This is a gate on the
release, not an aspiration.

## Unscheduled

Wanted, but not assigned to a version.

* Extract the VGA driver into a standalone repository shared with `pico-56`, which currently
  carries a diverged fork.
* Expose a real-time clock through PICO9918 registers ([#67](https://github.com/visrealm/pico9918/issues/67)).
* Sega Master System Mode 4 ([#61](https://github.com/visrealm/pico9918/issues/61)).
* Symbols, footprints and 3D renders for incorporating the PICO9918 into new designs
  ([#60](https://github.com/visrealm/pico9918/issues/60)).
* No-cut modification parts list ([#30](https://github.com/visrealm/pico9918/issues/30)).

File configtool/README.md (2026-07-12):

# PICO9918 Configurator

The configurator is a software tool used to modify PICO9918 configuration options, including:

* Clock rate
* Scanline CRT effect
* Scanline sprite limit
* Default palette
* Diagnostics overlays

Additionally, firmware updates can be provided via the Configurator. The full configurator is available for the **TI-99/4A**, **ColecoVision** and **MSX**. With cut-down builds (without firmware updates) available for several other machines.

See the configurator in action:

PICO9918 Configurator - ColecoVision (https://youtu.be/PBArYupT9qM?t=9)

The configurator was written in a [custom fork of CVBasic](https://github.com/visrealm/CVBasic).

### Web-based Configurator

If you don't have a device supported by the native configurator, the [Web-based PICO9918 Configurator](https://visrealm.github.io/pico9918/config/index.html) can be used to generate a config .uf2 file. Just drag-and-drop the resulting file onto your PICO9918 using the same method as for firmware updates.

## Building

### Prerequisites

#### Option 1: Use existing tools
- CMake 3.13 or later
- Python 3 (accessible as `python3`)
- CVBasic compiler (`cvbasic.exe`)
- GASM80 assembler (`gasm80.exe`) 
- XDT99 XAS99 assembler (for TI-99 builds)

#### Option 2: Auto-build tools (Linux/cross-platform)
- CMake 3.13 or later
- Python 3 (accessible as `python3`)
- Git (for checking out tool repositories)
- C compiler (GCC or Clang for building tools)

### Usage

#### Integrated Build (Recommended)
The configurator is now integrated into the main PICO9918 build system:

```bash
# Build from project root
mkdir build && cd build
cmake ..
make                    # Build firmware
make configurator_all   # Build all configurator ROMs
```

All final artifacts will be in `build/dist/`:
- **Firmware**: `pico9918-vga-build-v1-0-2.uf2`
- **Configurator ROMs**: `pico9918_v1-0-2_*.rom` / `pico9918_v1-0-2_*.bin`

#### Standalone Build (Legacy)
```bash
cd configtool
mkdir build && cd build
cmake .. [-DBUILD_TOOLS_FROM_SOURCE=ON]
make configurator_all
```

#### Build Individual Platforms
```bash
make ti99              # TI-99/4A
make ti99_f18a         # TI-99/4A F18A Testing  
make coleco            # ColecoVision
make msx_asc16         # MSX ASCII16 mapper
make msx_konami        # MSX Konami mapper
make sg1000            # SG1000/SC3000
make nabu              # NABU
make creativision      # CreatiVision
```

#### Build with Ninja (faster)
```bash
cmake .. -G Ninja [-DBUILD_TOOLS_FROM_SOURCE=ON]
ninja configurator_all
```

## How it Works

1. **Firmware Dependency**: Checks for pre-built firmware in `../build/src/`
2. **UF2 Conversion**: Converts firmware to CVBasic data using `uf2cvb.py`
3. **CVBasic Compilation**: Compiles `.bas` sources for each target platform
4. **Assembly**: Uses GASM80 (most platforms) or XAS99 (TI-99) for final ROM creation
5. **Packaging**: Creates platform-specific ROM files (.bin, .rom, .nabu, etc.)

## Platform Support

| Platform | Mapper/Banking | Output Format | Assembly Tool |
|---|---|---|---|
| TI-99/4A | 8KB banks | .bin cartridge | XAS99 + linkticart |
| ColecoVision | 16KB banks | .rom | GASM80 |
| MSX | ASCII16/Konami | .rom | GASM80 |
| NABU | No banking | .nabu/.npz | GASM80 |
| CreatiVision | No banking | .bin | GASM80 |

## Tool Detection

### Default Mode (existing tools)
The build system automatically searches for tools in:
1. `configtool/tools/cvbasic/` (bundled tools)
2. `../CVBasic/build/Release/` (local CVBasic build)  
3. System PATH
4. `c:/tools/xdt99/` (Windows) or `/usr/local/bin`, `/opt/xdt99` (Linux)

### Auto-build Mode (`-DBUILD_TOOLS_FROM_SOURCE=ON`)
When enabled, CMake will:
1. Clone CVBasic from https://github.com/visrealm/CVBasic.git
2. Clone gasm80 from https://github.com/visrealm/gasm80.git  
3. Clone XDT99 from https://github.com/endlos99/xdt99.git
4. Build CVBasic and gasm80 from source using their CMake systems
5. Install tools to `build/external/` directory
6. Use the locally-built tools for ROM generation

This mode enables fully cross-platform builds without pre-installed tools.

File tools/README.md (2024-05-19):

Any custom tools required for the project go here:

# [img2carray.py](img2carray.py)

An image converter. Converts images into C arrays for direct use in a PICO-56 program.

The format of the image data will be `const uint16_t[]` for 24 or 32 bit images and will be a combined `const uint16_t[]` for the palette and a `const uint8_t[]` at 4 bits per pixel for 16 color paletized images and 8 bits per pixel for 256 color paletized images.

Alpha values are also supported.

The output format is `0bAAAABBBBGGGGRRRR` or `0xABGR`.

## Dependencies

The script requires the [Pillow Imaging Library](https://pypi.org/project/Pillow/).

Installation:

```sh
python3 -m pip install --upgrade Pillow
```

## Usage

```sh
python3 img2carray.py [-h] [-v] [-p PREFIX] [-o OUT] [-r RAM [RAM ...]] [-i IN [IN ...]]

Convert images into C-style arrays for use with the PICO-56.

options:
  -h, --help            show this help message and exit
  -v, --verbose         verbose output
  -p PREFIX, --prefix PREFIX
                        array variable prefix
  -o OUT, --out OUT     output file - defaults to base input file name with .c extension
  -r RAM [RAM ...], --ram RAM [RAM ...]
                        input file(s) to store in Pi Pico RAM - can use wildcards
  -i IN [IN ...], --in IN [IN ...]
                        input file(s) to store in Pi Pico ROM - can use wildcards
```

### input

A filename or glob (wildcards) to convert. By default, the arrays will be stored in the Pi Pico flash/ROM. TO have an image array assigned to be stored in RAM, pass it in using the -r / --ram command-line prefix.

### output

Optional parameter to specify a single output file.

By default, the output files will be named the same as the input file(s) with a .c/.h extension. This option allows you to combine multiple images into a single C source. A header file of the same name is also generated.

## Example usage

```sh
python img2carray.py -i res/*.png -o images.c
```

Will generate images.c and images.h containing all .png images in the res directory.

## CMake integration

[The root CMakeLists.txt](../CMakeLists.txt) contains a `visrealm_generate_image_source()` function which can be used to integrate this tool into your build process.

```sh
visrealm_generate_image_source(<program-name> <output-file> <rom-images> [<ram-images>])
```

Here is an example usage in your project's CMakeLists.txt:

```sh
visrealm_generate_image_source(${PROGRAM} images res/*.png res/myramimage.png)
```

This function will generate the C source file(s) from the input images and also add the .c file to the `target_sources()`. The generated file(s) will be placed in yout project's build directory.

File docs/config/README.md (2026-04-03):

# PICO9918 Configuration Generator

This is a web-based tool for generating custom configuration UF2 files for the PICO9918.

## Live Tool

🌐 **[Open Configuration Tool](index.html)**

Or access it online at: `https://visrealm.github.io/pico9918/config/`

## What This Tool Does

The PICO9918 stores its configuration in the top 4KB of flash memory. When you update the firmware, this configuration area is preserved. However, if the configuration becomes corrupted or incompatible, this tool allows you to generate a small UF2 file (512 bytes) to reset or update just the configuration without reflashing the entire firmware.

## Features

- **Display Settings**: Configure scanlines, sprite limits, and clock presets
- **Palette Editor**: Customize all 16 TMS9918A colors with preset palettes (TMS9918A, V9938, Greyscale, Sepia)
- **Diagnostic Modes**: Enable debugging overlays for development
- **Instant Download**: Generate and download UF2 files directly in your browser
- **Offline Support**: Works without an internet connection once loaded
- **Auto Hardware Detection**: Firmware automatically detects and validates hardware configuration

## How to Use

1. Open `index.html` in your web browser
2. Configure display settings as desired
3. (Optional) Customize the palette or enable diagnostic modes
4. Click "Generate & Download UF2"
5. Save the generated `.uf2` file

## Installing the Configuration

1. Hold the BOOTSEL button on your PICO9918 while powering it on
2. The device will appear as a USB drive named "RPI-RP2"
3. Drag and drop the generated `.uf2` file onto the drive
4. The device will automatically reboot with the new configuration

## Configuration Options Explained

### Display Settings

- **CRT Scanlines**: Adds horizontal scanlines for a CRT monitor effect
- **Scanline Sprite Limit**: Limits sprites per scanline (0 = no limit, mimics original TMS9918A behavior)
- **Clock Preset**: Selects different timing presets (0 = default)

### Palette Editor

Customize the 16 TMS9918A colors with preset palettes or create custom colors:
- **TMS9918A (Default)**: Original colorful palette
- **V9938**: MSX2 palette
- **Greyscale**: Monochrome grey tones
- **Sepia**: Vintage warm brown tones

Note that:
- Color 0 (transparent) is always black
- Colors use 12-bit RGB (4 bits per channel)
- Alpha channel is always 0xF (opaque) for colors 1-15

### Diagnostic Modes

Enable on-screen debugging information:
- **Registers**: Shows VDP register values
- **Performance**: Shows frame timing and performance metrics
- **Palette**: Shows current palette information
- **Address**: Shows memory address information

⚠️ **Warning**: Diagnostic modes are for debugging and may affect performance.

## Deploying to GitHub Pages

To make this tool available online:

1. Ensure the `docs/` folder is in your repository
2. Go to Settings → Pages in your GitHub repository
3. Set Source to "Deploy from a branch"
4. Select branch `main` (or `master`) and folder `/docs`
5. Click Save
6. The tool will be available at `https://<username>.github.io/<repository>/`

For the pico9918 repository: `https://visrealm.github.io/pico9918/`

## Technical Details

- **File Size**: Generated UF2 files are exactly 512 bytes (one UF2 block)
- **Target Address**: `0x101FF000` (top 4KB of 2MB flash)
- **Format**: Standard UF2 format with RP2040/RP2350 family ID
- **Compatibility**: Works in all modern browsers (Chrome, Firefox, Safari, Edge)
- **Dependencies**: None - fully self-contained single HTML file

## Comparison with Python Tool

This web tool generates identical UF2 files to the Python command-line tool (`configtool/tools/config_uf2.py`). Both tools:
- Use the same configuration structure (256 bytes)
- Target the same flash address
- Apply the same validation requirements
- Generate byte-identical output for the same settings

The web tool offers a more user-friendly interface, while the Python tool is better for automation and scripting.

## Troubleshooting

### Configuration is rejected by firmware

The firmware will automatically detect your hardware (Pico model and display driver). If configuration is still rejected, make sure:
- All values are within valid ranges
- Your firmware version supports the configuration format

### Download doesn't work

- Try a different browser
- Check browser security settings
- Ensure JavaScript is enabled
- Try opening the file directly instead of via a web server

### Configuration doesn't apply

- Verify the UF2 file was successfully loaded (device should reboot)
- Check that your firmware version supports configuration updates
- Try resetting to default configuration first

## Source Code

This is a self-contained HTML file with embedded CSS and JavaScript. To view or modify the source, simply open `index.html` in a text editor.

The implementation follows the same logic as the Python script but uses JavaScript for browser compatibility.

## License

This tool is part of the PICO9918 project and is licensed under the MIT License.

Copyright (c) 2024 Troy Schrapel

## Links

- [PICO9918 GitHub Repository](https://github.com/visrealm/pico9918)
- [Firmware Releases](https://github.com/visrealm/pico9918/releases)
- [AtariAge Forum Discussion](https://atariage.com/forums/topic/323020-pico9918-drop-in-replacement-for-tms9918a)
- [Python Configuration Tool](../../configtool/tools/config_uf2.py)

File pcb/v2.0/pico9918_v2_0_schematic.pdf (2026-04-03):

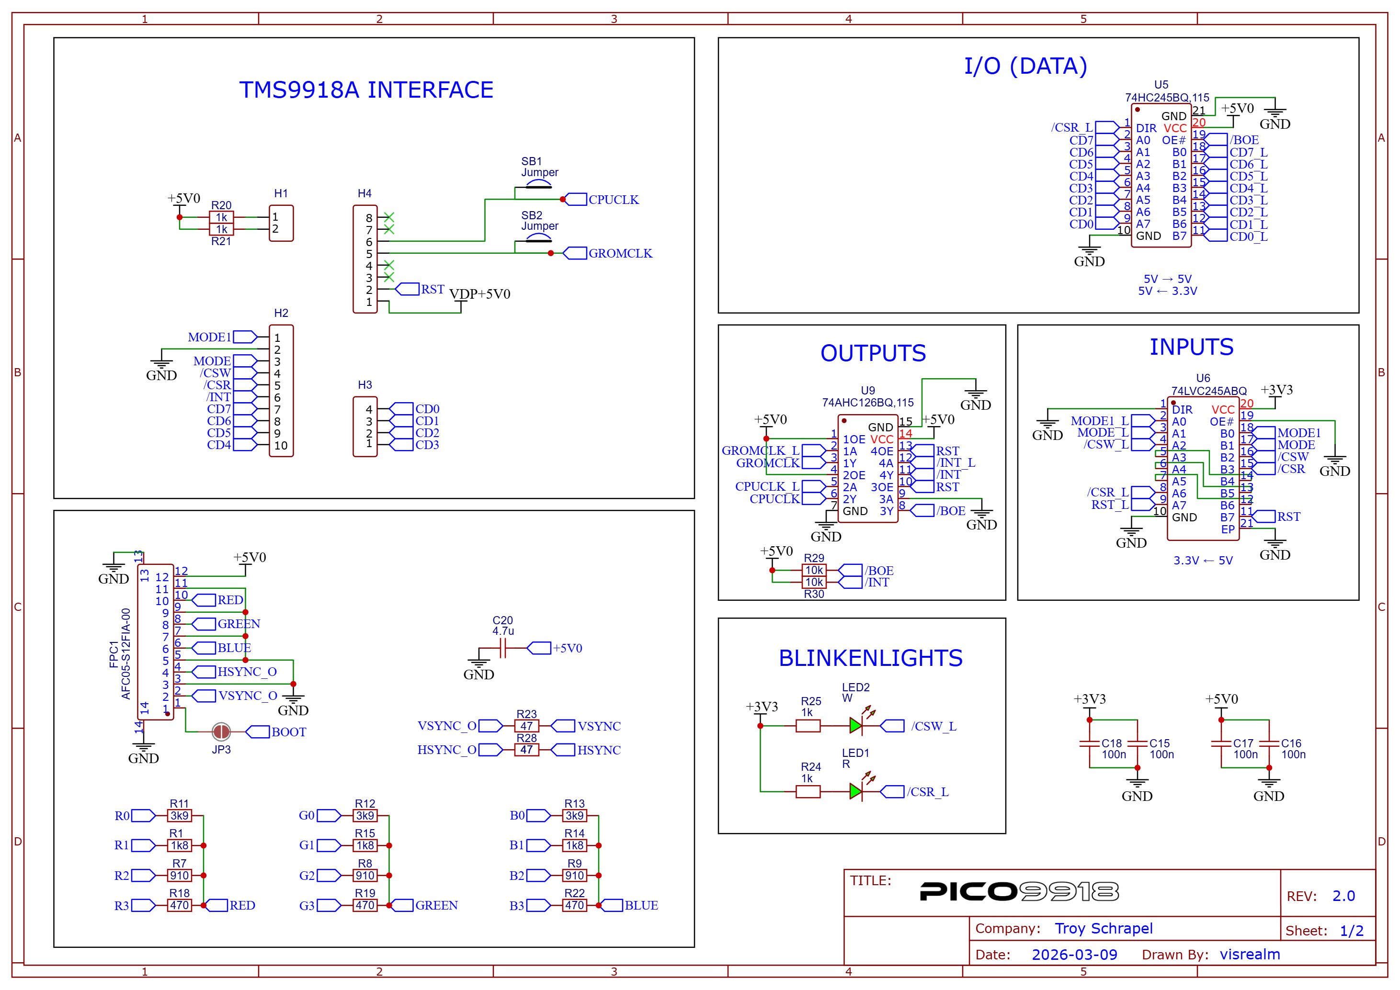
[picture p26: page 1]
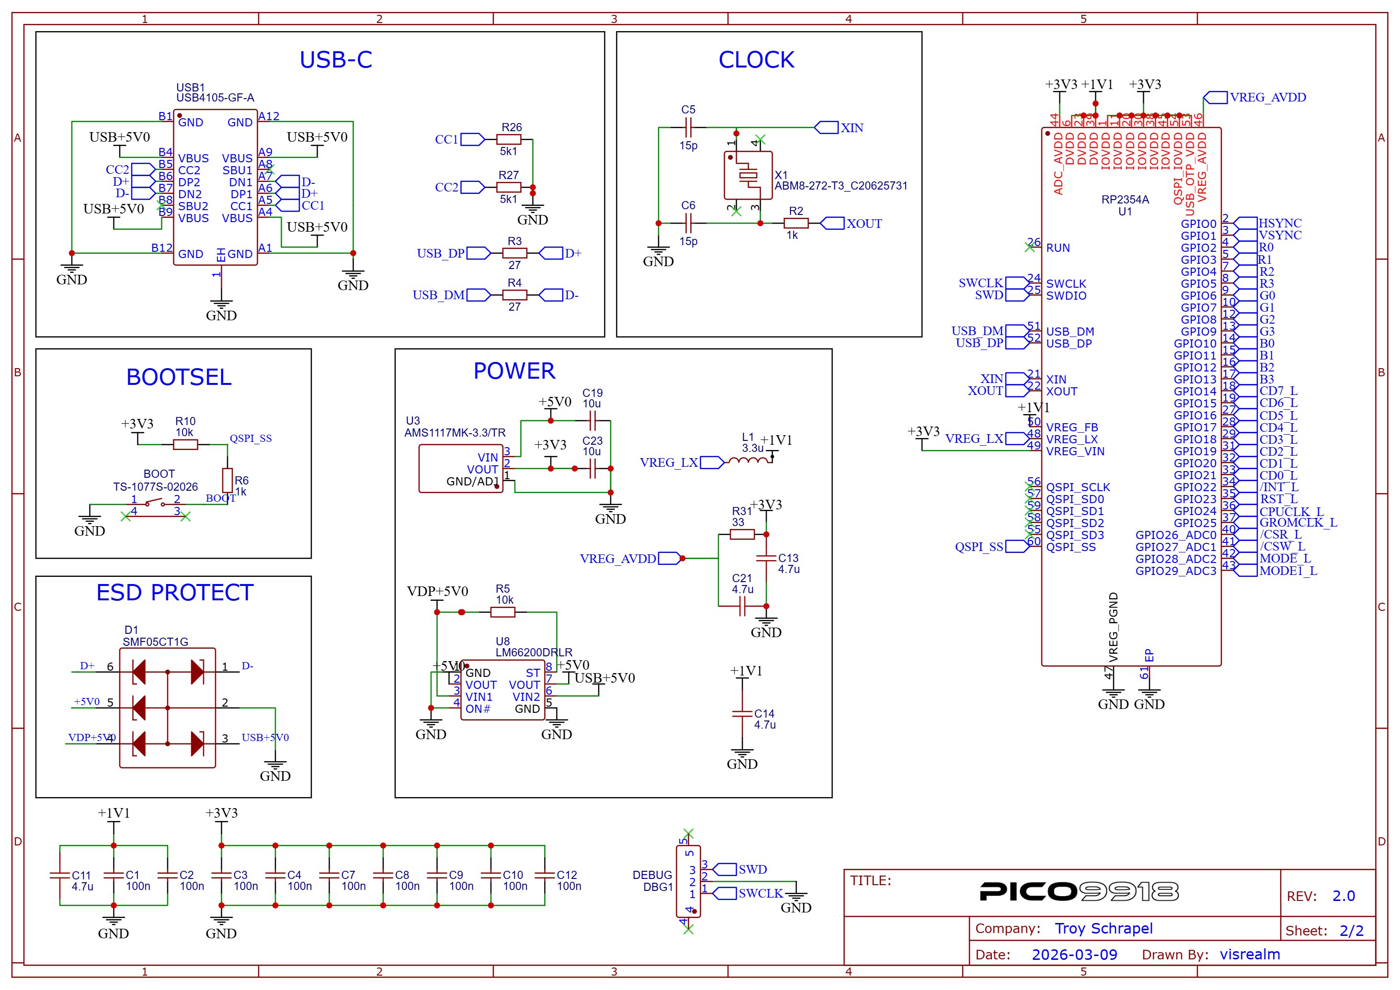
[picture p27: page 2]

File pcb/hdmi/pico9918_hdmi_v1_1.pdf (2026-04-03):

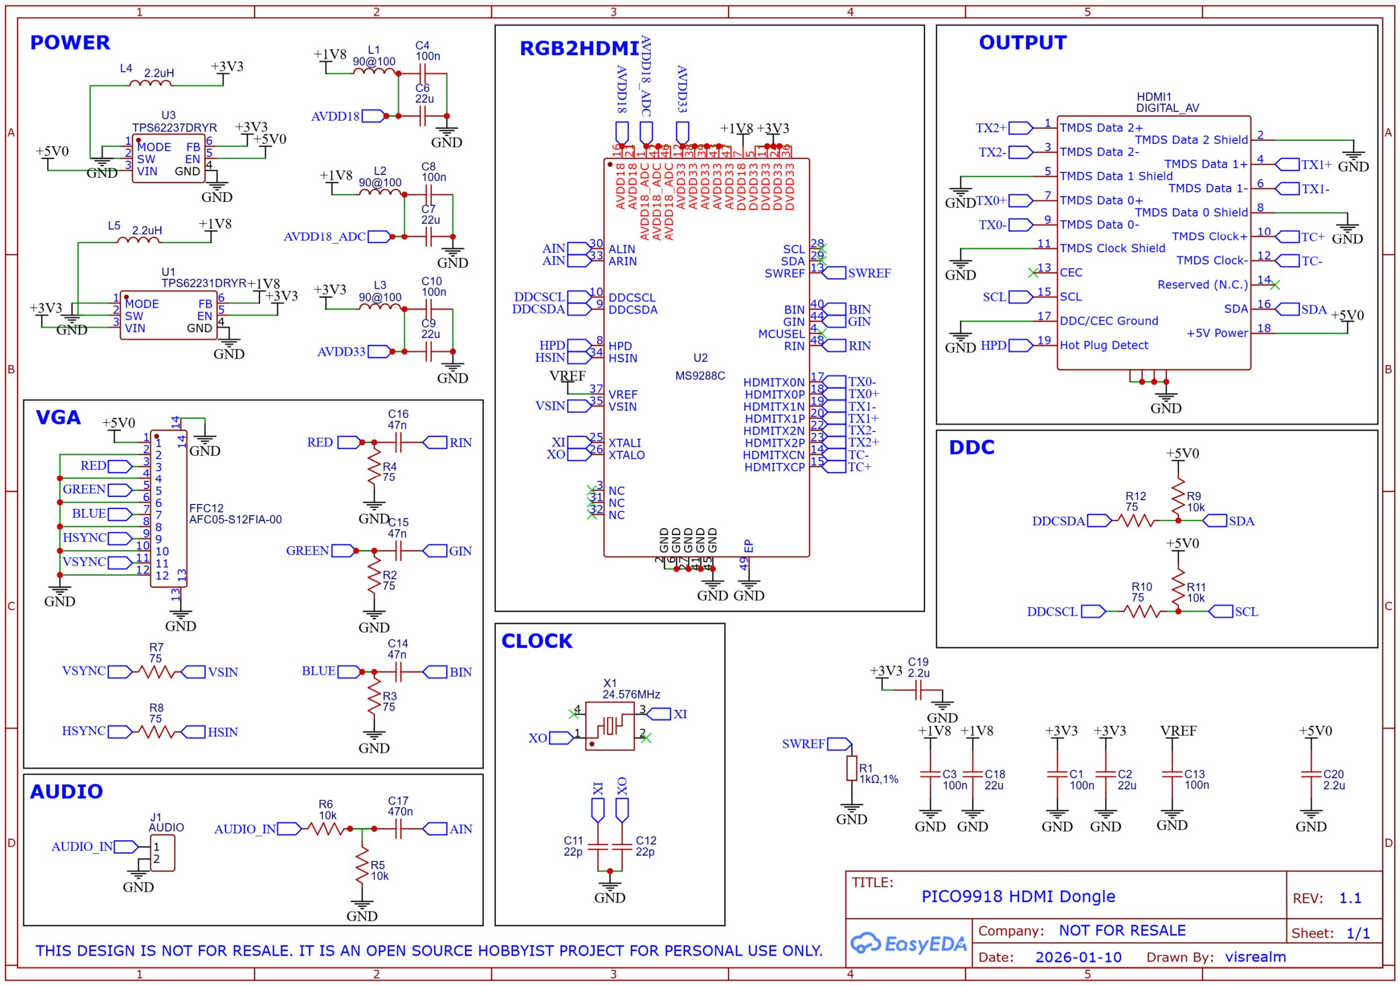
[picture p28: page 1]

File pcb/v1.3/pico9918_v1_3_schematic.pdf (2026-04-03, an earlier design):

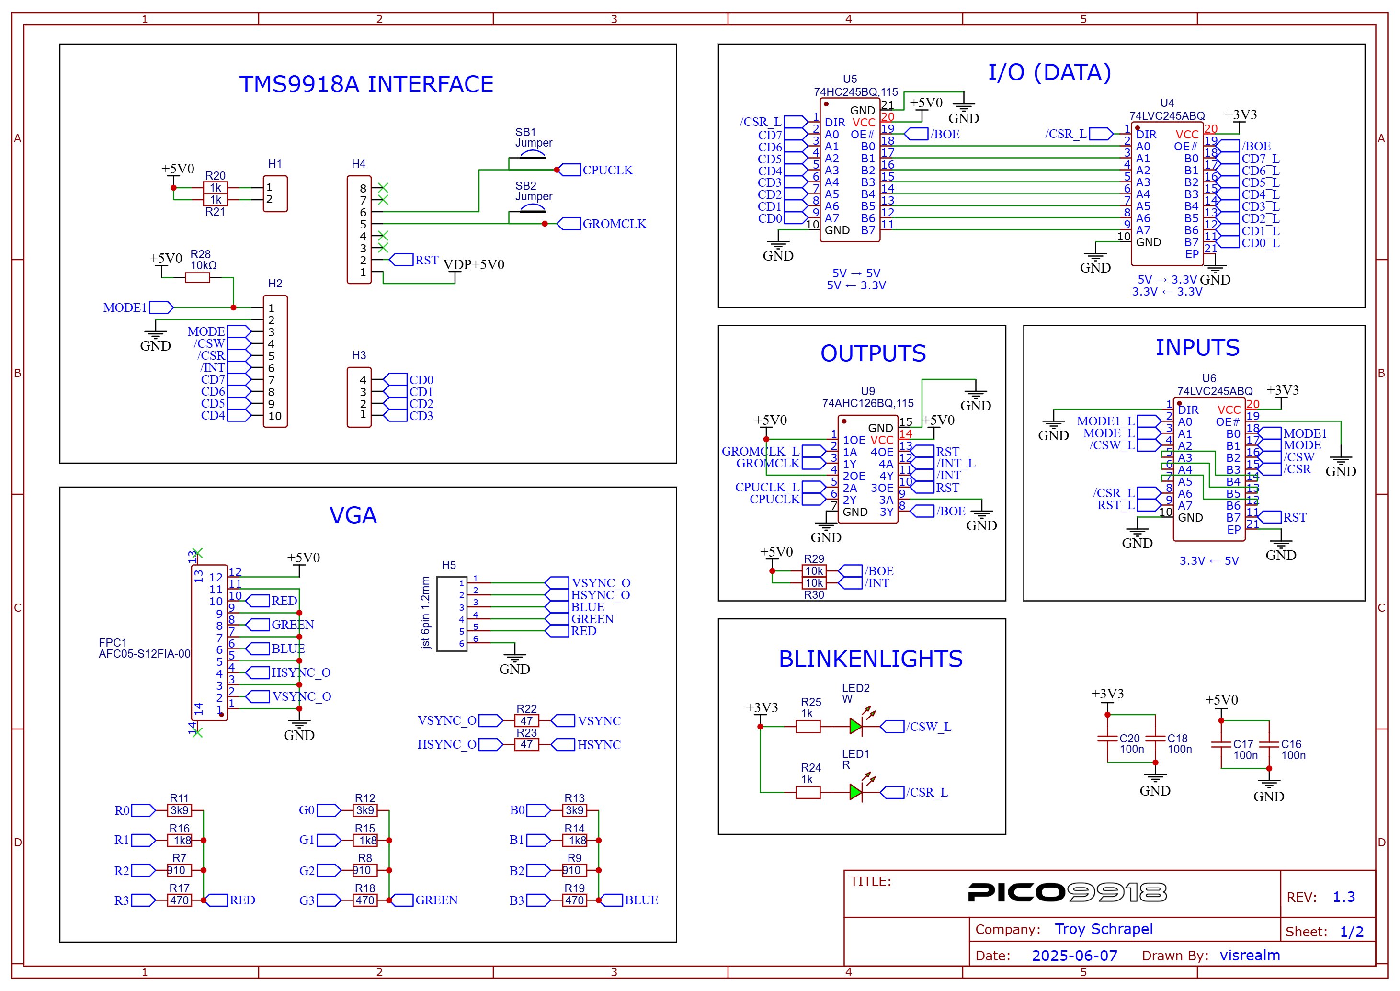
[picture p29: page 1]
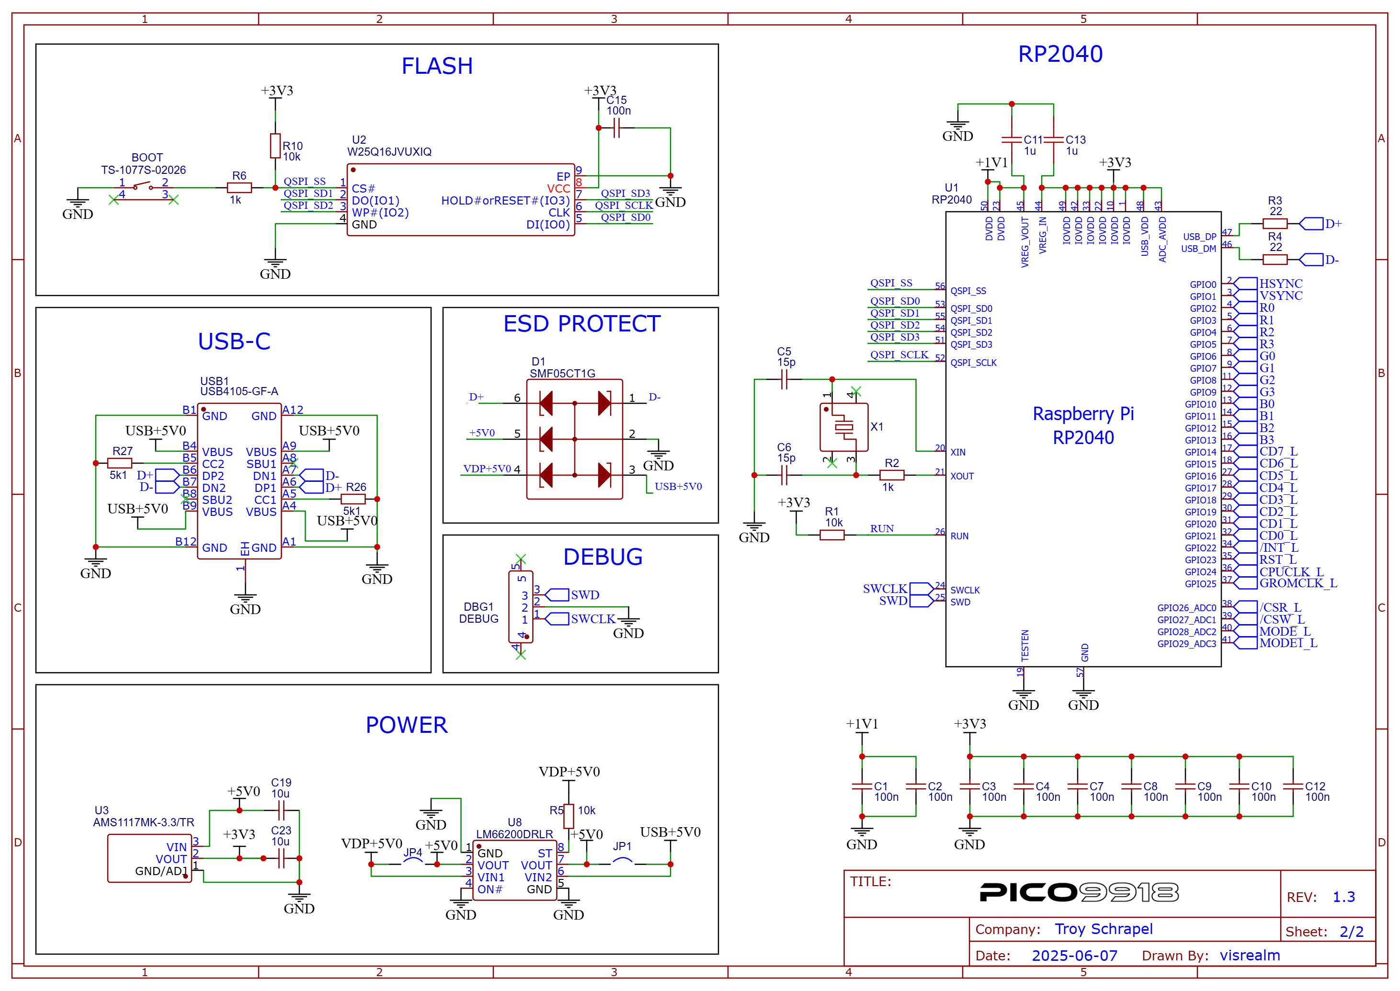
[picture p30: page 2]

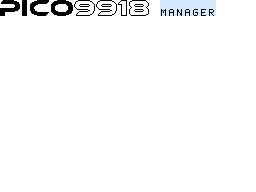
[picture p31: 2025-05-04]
configtool/img/tool.png

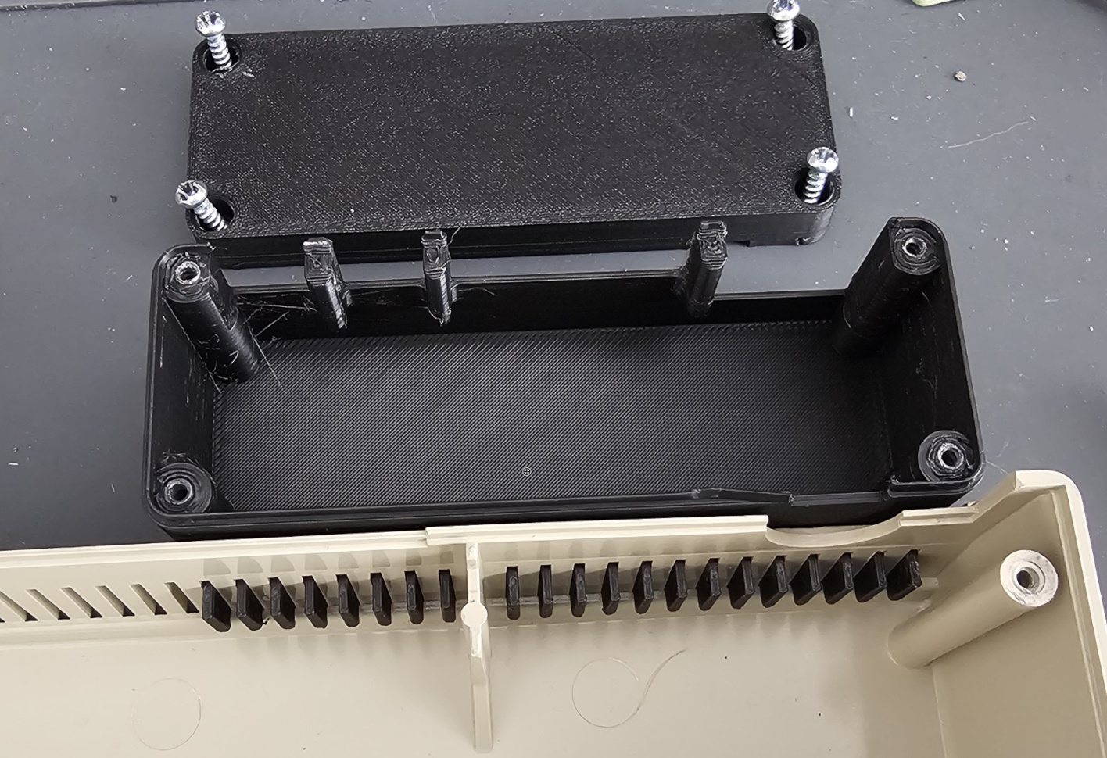
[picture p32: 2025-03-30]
nocut/ti99/img/nocut-ti99-enclosure-2.jpg

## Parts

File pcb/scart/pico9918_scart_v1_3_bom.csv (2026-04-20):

ID | Name | Designator | Footprint | Quantity | Manufacturer Part | Manufacturer | Supplier | Supplier Part | Price
1 | HDR-M-2.54_1x2 | J2 | HDR-M-2.54_1X2 | 1 |  |  | LCSC | C124375 | 0.031
2 | miniDIN10_CA_SchematicLib | U1 | MINIDIN10PCBLIB | 1
3 | 1k | R2 | R0805 | 1
4 | AFC05-S12FIA-00 | FPC2 | FPC-SMD_12P-P0.50_AFC05-S12FIA-00 | 1 | AFC05-S12FIA-00 | JS(钜硕电子) | LCSC | C561387 | 0.163

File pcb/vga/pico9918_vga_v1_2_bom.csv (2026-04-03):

ID | Name | Designator | Footprint | Quantity | Manufacturer Part | Manufacturer | Supplier | Supplier Part | Price
1 | AFC05-S12FIA-00 | FFC12 | FPC-SMD_12P-P0.50_AFC05-S12FIA-00 | 1 | AFC05-S12FIA-00 | JS(钜硕电子) | LCSC | C561387 | 0.161
2 | HYC06-HDR15B-060 | VGA1 | DSUB-TH_HYC06-HDR15B-060 | 1 | HYC06-HDR15B-060 | 华宇创 | LCSC | C711364 | 0.202

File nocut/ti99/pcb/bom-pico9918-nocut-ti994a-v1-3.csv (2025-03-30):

ID | Name | Designator | Footprint | Quantity | Manufacturer Part | Manufacturer | Supplier | Supplier Part | Price
2 | AFC05-S12FIA-00 | FPC1 | FPC-SMD_12P-P0.50_AFC05-S12FIA-00 | 1 | AFC05-S12FIA-00 | JS(钜硕电子) | LCSC | C561387 | 0.142

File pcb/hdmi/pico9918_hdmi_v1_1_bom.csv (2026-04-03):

ID | Name | Designator | Footprint | Quantity | Manufacturer Part | Manufacturer | Supplier | Supplier Part | Price
1 | 2.2uH | L5,L4 | L0805 | 2 | LQM21PN2R2MGSD | muRata | LCSC | C711165 | 0.12
2 | TPS62231DRYR | U1 | SON-6_L1.5-W1.0-P0.50-BL | 1 | TPS62231DRYR | TI(德州仪器) | LCSC | C140299 | 0.594
3 | 2.2u | C19,C20 | C0603 BARE | 2 | CL10A225KO8NNNC | SAMSUNG(三星) | LCSC | C23630 | 0.006
4 | TPS62237DRYR | U3 | SON-6_L1.5-W1.0-P0.50-BL | 1 | TPS62237DRYR | TI(德州仪器) | LCSC | C398923 | 0.788
5 | 100n | C1,C3,C4,C8,C10,C13 | C0402 BARE | 6 | CL05B104KO5NNNC | SAMSUNG(三星) | LCSC | C1525 | 0.001
6 | 22p | C11,C12 | C0402 BARE | 2 | 0402CG220J500NT | FH(风华) | LCSC | C1555 | 0.001
7 | 47n | C14,C15,C16 | C0402 BARE | 3 | 0402B473K500NT | FH(风华) | LCSC | C82219 | 0.002
8 | 470n | C17 | C0402 BARE | 1 | CL05A474KP5NNNC | SAMSUNG(三星) | LCSC | C47339 | 0.006
9 | 10k | R5,R6,R9,R11 | R0402 BARE | 4 | 0402WGF1002TCE | UNI-ROYAL(厚声) | LCSC | C25744 | 0.001
10 | 90@100 | L1,L2,L3 | L0402 BARE | 3 | MPZ1005S900HT000 | TDK | LCSC | C524454 | 0.017
11 | 22u | C2,C6,C7,C9,C18 | C0603 BARE | 5 | CL10A226MQ8NRNC | SAMSUNG(三星) | LCSC | C59461 | 0.009
12 | 1kΩ,1% | R1 | R0402 BARE | 1 | 0402WGF1001TCE | UNI-ROYAL(厚声) | LCSC | C11702 | 0.001
13 | 75 | R2,R3,R4,R7,R8,R10,R12 | R0402 BARE | 7 | 0402WGF750JTCE | UNI-ROYAL(厚声) | LCSC | C25133 | 0.001
14 | AFC05-S12FIA-00 | FFC12 | FPC-SMD_12P-P0.50_AFC05-S12FIA-00 | 1 | AFC05-S12FIA-00 | JS(钜硕电子) | LCSC | C561387 | 0.161
15 | DIGITAL_AV | HDMI1 | HDMI-SMD_19P-P0.50-H-F | 1 | HDMI-001 19PCBTP | BOOMELE(博穆精密) | LCSC | C138388 | 0.221
16 | AUDIO | J1 | HDR-M-2.54_1X2 | 1 |  |  | LCSC | C124375 | 0.031
17 | MS9288C | U2 | QFN-48_L6.0-W6.0-P0.40-TL-EP4.2 | 1 | MS9288C | Macrosilicon(宏晶微) | LCSC | C2914316 | 1.461
18 | 24.576MHz | X1 | CRYSTAL-SMD_4P-L3.2-W2.5-BL | 1 | XTM32024576GT00351001 | 同晶 | LCSC | C41383246 | 0.039

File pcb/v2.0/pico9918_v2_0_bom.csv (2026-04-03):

ID | Name | Designator | Footprint | Quantity | Manufacturer Part | Manufacturer | Supplier | Supplier Part | Price
1 | USB4105-GF-A | USB1 | TYPE-C-SMD_SBC-160S1A-20-S412 | 1 | USB4105-GF-A | null | LCSC | C2765186 | 0.065
2 | TS-1077S-02026 | BOOT | SW-SMD_L3.1-W3.1-P2.20-LS4.0 | 1 | TS-1077S-02026 | XUNPU(讯普) | LCSC | C455261 | 0.056
3 | R | LED1 | LED0603_GREEN | 1 |  |  | LCSC | C965804 | 0.005
4 | W | LED2 | LED0603_GREEN | 1 |  |  | LCSC | C965799 | 0.004
5 | AFC05-S12FIA-00 | FPC1 | FPC-SMD_12P-P0.50_AFC05-S12FIA-00 | 1 | AFC05-S12FIA-00 | JS(钜硕电子) | LCSC | C561387 | 0.161
6 | 4.7u | C20,C11,C13,C14,C21 | C0402 | 5 | CL05A475MQ5NRNC | SAMSUNG | LCSC | C307423 | 0.004
7 | 1k8 | R1,R14,R15 | R0402 | 3 |  |  | LCSC | C163481 | 0.001
8 | 910 | R7,R8,R9 | R0402 | 3 |  |  | LCSC | C2076670 | 0.007
9 | 3k9 | R11,R12,R13 | R0402 | 3 |  |  | LCSC | C100405 | 0.001
10 | 470 | R18,R19,R22 | R0402 | 3 |  |  | LCSC | C25117 | 0.001
11 | 47 | R23,R28 | R0402 | 2 |  |  | LCSC | C137973 | 0.001
12 | 1k | R24,R25,R20,R21 | R0402 | 4 |  |  | LCSC | C11702 | 0.001
13 | 100n | C18 | C0402 | 1 |  |  | LCSC | C1525 | 0.001
14 | 74LVC245ABQ | U6 | DHVQFN20_L4.5-W2.5-P0.50-BL | 1 | 74LVC245ABQ,115 | Nexperia(安世) | LCSC | C294612 | 0.181
15 | 3.3u | L1 | IND-SMD_L2.0-W1.6_AOTA-B201610S3R3-101-T | 1 | AOTA-B201610S3R3-101-T | ABRACON | LCSC | C42411119 | 0.289
16 | 33 | R31 | R0402 | 1 | RC0402FR-0733RL | YAGEO | LCSC | C138002 | 0.001
17 | RP2354A | U1 | QFN-60_L7.0-W7.0-P0.40-TL-EP3.4 | 1 | RP2354A | Raspberry Pi(树莓派) | LCSC | C41378174 | 1.462
18 | 27 | R3,R4 | R0402 | 2 | RC0402FR-0727RL | YAGEO | LCSC | C138021 | 0.001
19 | 5k1 | R26,R27 | R0402 | 2 | 0402WGF1001TCE | UniOhm | LCSC | C25905 | 0.001
20 | 10k | R29,R30 | R0402 | 2 |  |  | LCSC | C25744 | 0.001
21 | 10k | R5,R10 | R0402 | 2 | 0402WGF1002TCE | UniOhm | LCSC | C25744 | 0.001
22 | LM66200DRLR | U8 | SOT-583-8_L2.1-W1.2-P0.50-LS1.6-BL | 1 | LM66200DRLR | TI(德州仪器) | LCSC | C3235556 | 0.471
23 | 74AHC126BQ,115 | U9 | DHVQFN-14_L3.0-W2.5-P0.50-BL-EP | 1 | 74AHC126BQ,115 | Nexperia(安世) | LCSC | C554221 | 0.643
24 | 74HC245BQ,115 | U5 | DHVQFN-20_L4.5-W2.5-P0.50-BL-EP | 1 | 74HC245BQ,115 | Nexperia(安世) | LCSC | C503362 | 0.638
25 | DEBUG | DBG1 | CONN-SMD_3P-P1.00_WAFER-SH1.0-3PWB | 1 | 连接器SH卧贴 1.0mm 间距 3P | null | LCSC | C9900022975
26 | HDR-M-2.54_1x2 | H1 | HDR-M-2.54_1X2 | 1 |  |  | LCSC | C124375 | 0.031
27 | HDR-M-2.54_1x10 | H2 | HDR-M-2.54_1X10 | 1 |  |  | LCSC | C57369 | 0.068
28 | HDR-M-2.54_1x4 | H3 | HDR-M-2.54_1X4 | 1 |  |  | LCSC | C124378 | 0.05
29 | HDR-M-2.54_1x8 | H4 | HDR-M-2.54_1X8 | 1 |  |  | LCSC | C190820 | 0.042
30 | ABM8-272-T3_C20625731 | X1 | CRYSTAL-SMD_4P-L3.2-W2.5-BL | 1 | ABM8-272-T3 | ABRACON | LCSC | C20625731 | 0.29
31 | 15p | C5,C6 | C0402 | 2 | 0402CG330J500NT | FH | LCSC | C1548 | 0.001
32 | 100n | C16,C17 | C0402 | 2 |  | SAMSUNG(三星) | LCSC | C1525 | 0.001
33 | 100n | C1,C2,C3,C4,C7,C8,C9,C10,C12 | C0402 | 9 | CL05B104KO5NNNC | SAMSUNG | LCSC | C1525 | 0.001
34 | 1k | R6,R2 | R0402 | 2 | 0402WGF1001TCE | UniOhm | LCSC | C11702 | 0.001
35 | 10u | C19,C23 | C0603 | 2 | CL31A106KBHNNNE | SAMSUNG | LCSC | C19702 | 0.008
36 | SMF05CT1G | D1 | SOT-363_L2.0-W1.3-P0.65-LS2.1-TL | 1 | SMF05CT1G | ON | LCSC | C15879 | 0.182
37 | AMS1117MK-3.3/TR | U3 | SOT-89_L4.5-W2.5-P1.50-LS4.2-BR | 1 | AMS1117MK-3.3/TR | HGC(华冠) | LCSC | C5120796 | 0.042

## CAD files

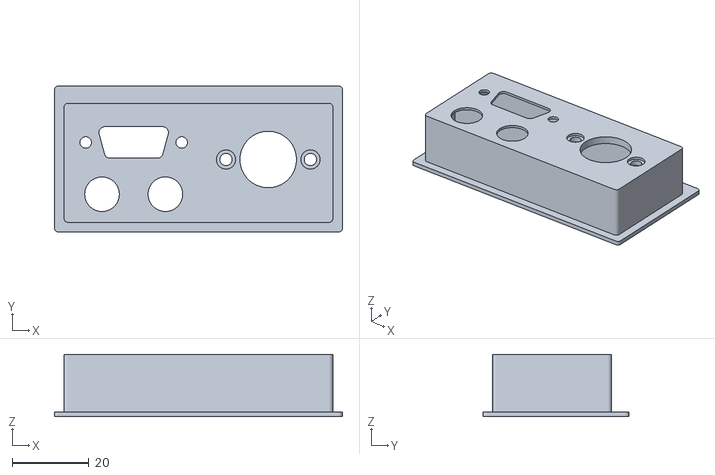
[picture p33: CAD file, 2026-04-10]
nocut/creativision/stl/pico9918-nocut-creativision-vga.stl
75.0 x 38.0 x 16.2

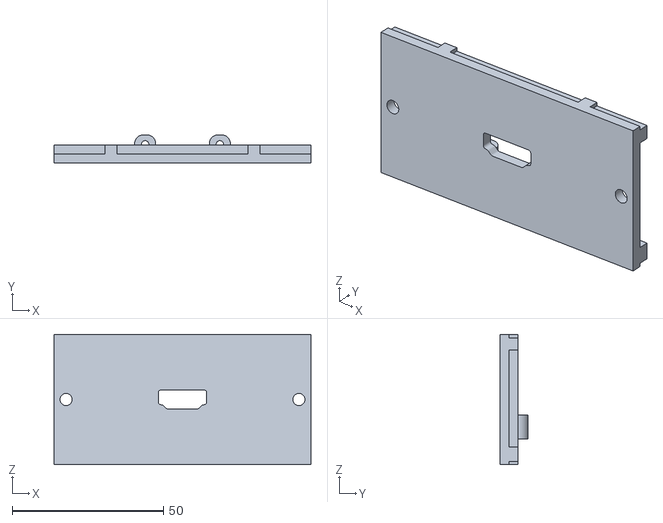
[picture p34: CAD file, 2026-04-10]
nocut/nabu/stl/pico9918-nocut-nabu-hdmi.stl
85.0 x 9.40 x 43.0

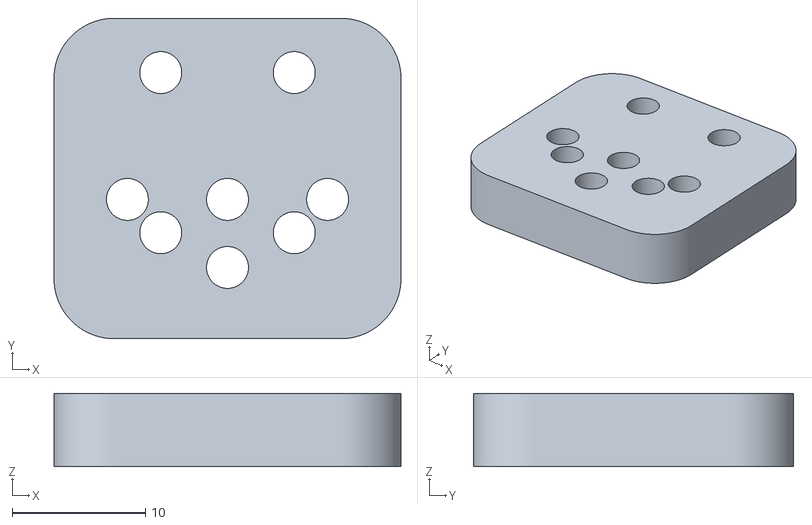
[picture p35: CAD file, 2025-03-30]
nocut/ti99/stl/pico9918-nocut-ti99-pcb-spacer-jig.stl
26.0 x 24.0 x 5.50

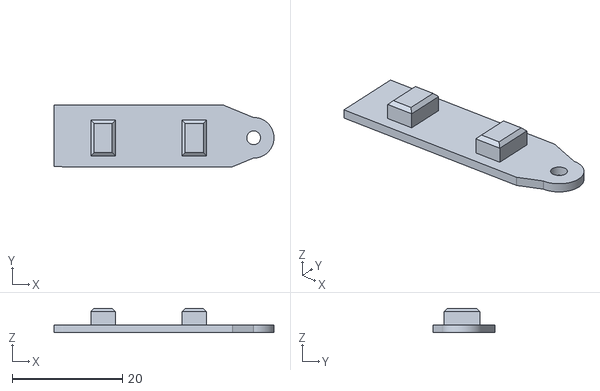
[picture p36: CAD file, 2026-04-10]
nocut/creativision/stl/pico9918-nocut-creativision-vga-rca-cover.stl
40.0 x 11.2 x 4.40

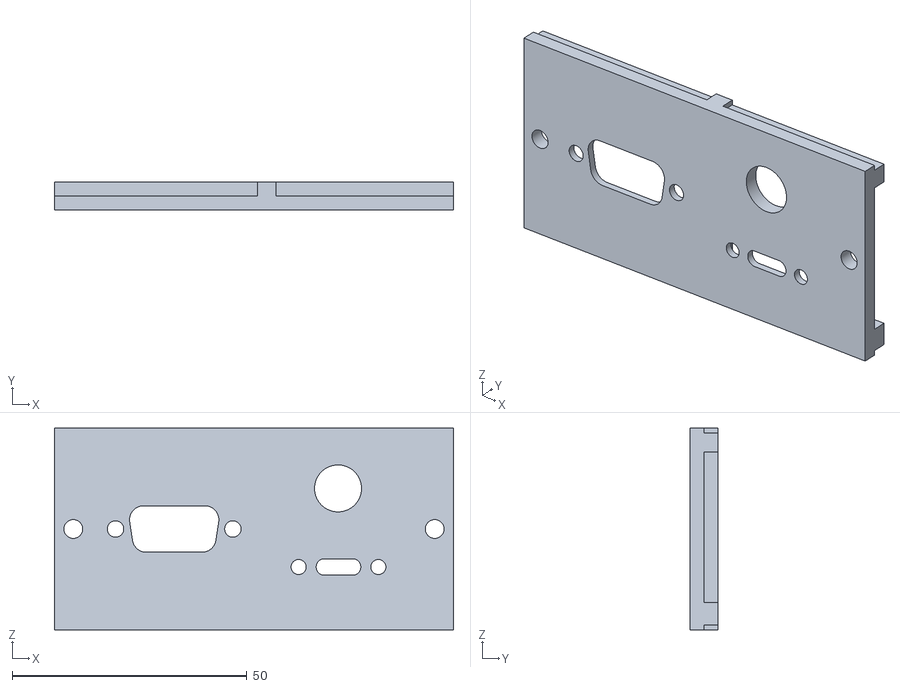
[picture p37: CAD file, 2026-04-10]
nocut/nabu/stl/pico9918-nocut-nabu-vga-usb-boot.stl
85.0 x 6.00 x 43.0

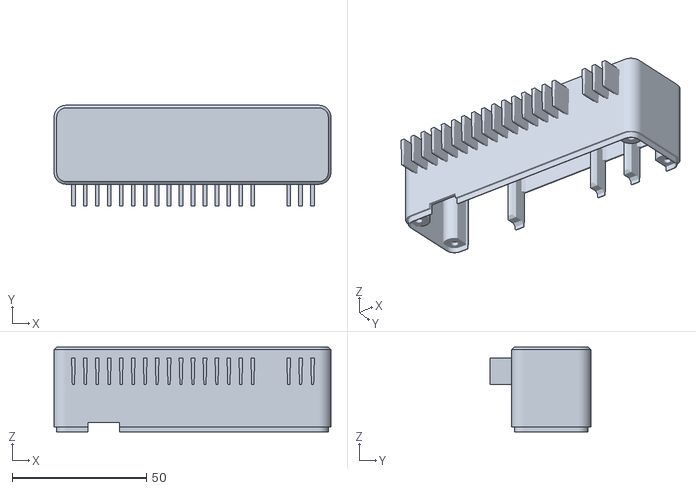
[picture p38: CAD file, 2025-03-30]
nocut/ti99/stl/pico9918-nocut-ti99-black-top.stl
103.1 x 37.4 x 31.6

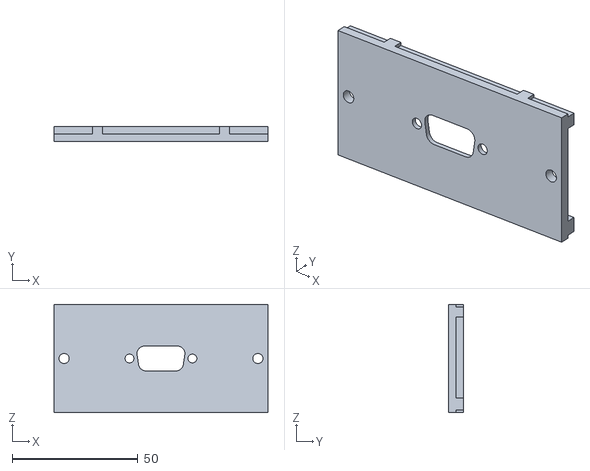
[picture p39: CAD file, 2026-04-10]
nocut/nabu/stl/pico9918-nocut-nabu-vga.stl
85.0 x 6.00 x 43.0

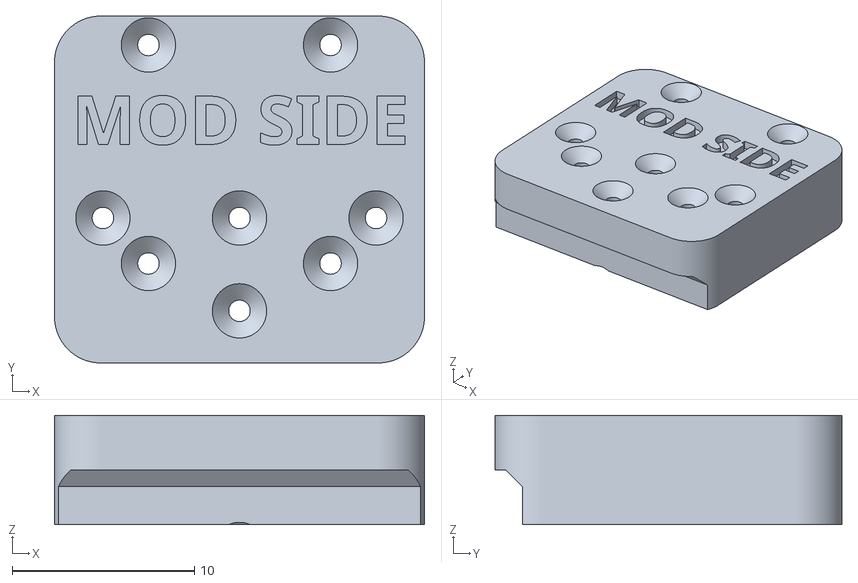
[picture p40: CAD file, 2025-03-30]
nocut/ti99/stl/pico9918-nocut-ti99-pcb-spacer.stl
20.3 x 19.1 x 6.00

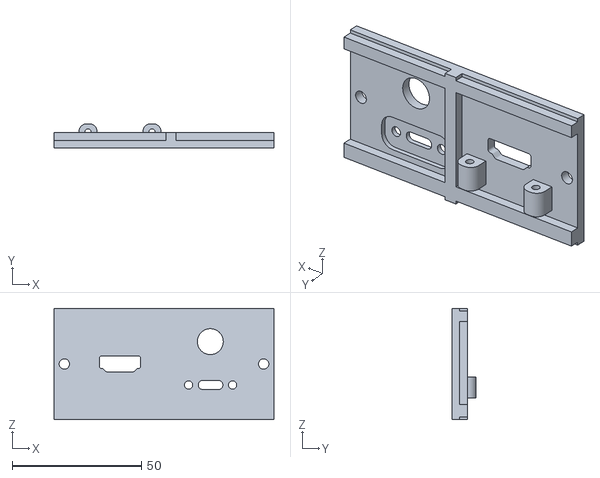
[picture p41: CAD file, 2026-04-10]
nocut/nabu/stl/pico9918-nocut-nabu-hdmi-usb-boot.stl
85.0 x 9.40 x 43.0

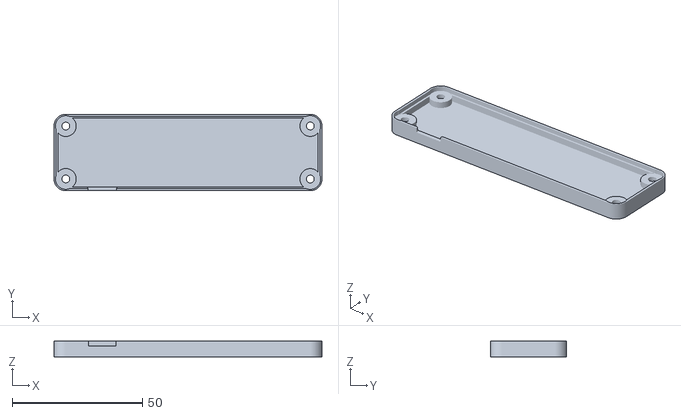
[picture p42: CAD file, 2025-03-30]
nocut/ti99/stl/pico9918-nocut-ti99-bottom.stl
103.1 x 29.4 x 6.00

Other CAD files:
nocut/ti99/stl/pico9918-nocut-ti99-beige-top.stl

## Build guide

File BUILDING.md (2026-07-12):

# Building PICO9918

This document describes how to build the PICO9918 firmware and configurator ROMs.

## Prerequisites

### Required Tools
- **CMake 3.13+**: Build system generator
- **ARM GNU Toolchain**: Cross-compiler for ARM Cortex-M0+ (RP2040)
- **Raspberry Pi Pico SDK**: Firmware compilation (v2.1.1 recommended for compatibility)
- **Python 3**: Build scripts and asset conversion
- **Git**: For submodules and dependencies

### Platform-Specific Setup

#### Windows
```bash
# Install dependencies
# Download and install ARM GNU Toolchain 13.2.1-1.1 from:
# https://github.com/xpack-dev-tools/arm-none-eabi-gcc-xpack/releases/download/v13.2.1-1.1/xpack-arm-none-eabi-gcc-13.2.1-1.1-win32-x64.zip
# Extract to C:\arm-toolchain\ and add to PATH

# Python dependencies
pip install pillow

# Install Pico SDK 2.1.1
git clone -b 2.1.1 --depth 1 https://github.com/raspberrypi/pico-sdk.git pico-sdk
cd pico-sdk
git submodule update --init
# Apply performance patches
git apply --ignore-whitespace --ignore-space-change --3way ../picosdk-2.0.0-visrealm-fastboot.patch
cd ..
```

#### Linux (Ubuntu/Debian)
```bash
# Install system dependencies  
sudo apt-get update
sudo apt-get install -y build-essential cmake python3 python3-pip git gcc-arm-none-eabi

# Python dependencies
pip3 install pillow

# Install Pico SDK 2.1.1
git clone -b 2.1.1 --depth 1 https://github.com/raspberrypi/pico-sdk.git pico-sdk
cd pico-sdk
git submodule update --init
# Apply performance patches
git apply --ignore-whitespace --ignore-space-change --3way ../picosdk-2.0.0-visrealm-fastboot.patch
cd ..
```

#### macOS
```bash
# Install dependencies via Homebrew
brew install cmake ninja python3 git

# Install ARM GNU Toolchain (same version as other platforms for consistency)
curl -L "https://github.com/xpack-dev-tools/arm-none-eabi-gcc-xpack/releases/download/v13.2.1-1.1/xpack-arm-none-eabi-gcc-13.2.1-1.1-darwin-arm64.tar.gz" -o arm-toolchain.tar.gz
sudo tar -xzf arm-toolchain.tar.gz -C /opt
echo 'export PATH="/opt/xpack-arm-none-eabi-gcc-13.2.1-1.1/bin:$PATH"' >> ~/.zshrc
source ~/.zshrc

# Python dependencies (may require --break-system-packages on newer macOS)
pip3 install pillow

# Install Pico SDK 2.1.1
git clone -b 2.1.1 --depth 1 https://github.com/raspberrypi/pico-sdk.git pico-sdk
cd pico-sdk
git submodule update --init
# Apply performance patches
git apply --ignore-whitespace --ignore-space-change --3way ../picosdk-2.0.0-visrealm-fastboot.patch
cd ..
```

### Development Environment Setup

To set up your development environment for the Raspberry Pi Pico, follow the [Raspberry Pi C/C++ SDK Setup](https://www.raspberrypi.com/documentation/microcontrollers/c_sdk.html) instructions.

The latest PICO9918 source can be configured and built using the official [Raspberry Pi Pico VSCode plugin](https://github.com/raspberrypi/pico-vscode).

## Building Firmware

The PICO9918 firmware is the primary component - a TMS9918A VDP emulator for Raspberry Pi Pico.

### Quick Start

**Combined build - firmware for PICO9918 and PICO9918 PRO, plus all configurator ROMs (Recommended)**
```bash
mkdir build && cd build
cmake .. -DPICO9918_BUILD_COMBINED=ON
cmake --build . --target combined
cmake --build . --target build_configurators
```

Outputs in `build/dist/`: combined `.uf2` firmware and all configurator ROMs.

**Firmware only (RP2040)**
```bash
mkdir build && cd build
cmake ..
cmake --build . --target firmware
```

Output: `build/dist/pico9918-vga-build-<version>.uf2`

### Firmware Configuration Options

Configure output mode and features with `-D` flags:

```bash
cmake .. -DPICO9918_DIAG=ON
```

#### Available Options
- **`PICO9918_ENABLE_SCART`** (ON/OFF, default ON): Runtime SCART dongle autodetect. VGA is always supported; when a SCART dongle is detected at boot, output switches to RGBs and the PAL/NTSC timing comes from the user configuration. Set OFF to produce a pure VGA-only firmware with no SCART detection code.
- **`PICO9918_NO_SPLASH`** (OFF/ON): Disable splash screen on startup
- **`PICO9918_DIAG`** (OFF/ON): Enable diagnostic mode by default

#### Configuration Examples
```bash
# Default: VGA + SCART autodetect
cmake ..

# Pure VGA firmware (no SCART support)
cmake .. -DPICO9918_ENABLE_SCART=OFF

# Diagnostic build with no splash
cmake .. -DPICO9918_DIAG=ON -DPICO9918_NO_SPLASH=ON
```

### Local Build Config File

Instead of passing `-D` flags every time, you can keep build settings in an
optional local config file. If `pico9918_config.cmake` exists in the project
root it is included automatically at configure time and can set or override any
build setting; if it is absent the build behaves exactly as normal. The file is
git-ignored, so your local tweaks never get committed.

To get started, copy the committed template
[`pico9918_config.cmake.template`](pico9918_config.cmake.template) to
`pico9918_config.cmake`, then uncomment and edit the settings you want:

```bash
cp pico9918_config.cmake.template pico9918_config.cmake
# edit pico9918_config.cmake (uncomment/change the settings you need)
cmake ..
```

**The template [`pico9918_config.cmake.template`](pico9918_config.cmake.template)
is the source of truth for the full list of overridable settings** - board,
version/artifact naming, the build options above, clock/PLL/flash timing,
GPIO/VGA pin assignments, and custom-hardware behaviour flags. A few examples of
what a config file can contain:

```cmake
# a diagnostic, VGA-only build
set(PICO9918_DIAG ON)
set(PICO9918_ENABLE_SCART OFF)

# target the RP2040 board and a custom artifact suffix
set(PICO_BOARD pico9918)
set(PICO9918_VERSION_SUFFIX "myfork")

# custom hardware: no TMS clock outputs, active-high interrupt, moved pins
set(PICO9918_NO_CLOCKS ON)
set(PICO9918_INT_ACTIVE_HIGH ON)
set(PICO9918_GPIO_INT 20)
set(PICO9918_VGA_RGB_PINS_START 6)
```

Settings still work as normal `-D` flags too; explicit `-D` on the command line
wins over the file.

### Firmware Targets
- **`firmware`**: Build firmware and copy to `build/dist/` (unified CMake system only)
- **`pico9918-vga-build-<version>`**: Direct firmware target name (available in all builds)

### VSCode Firmware Build
Use the Raspberry Pi Pico VSCode extension:
- **Compile Project**: Builds firmware with current configuration
- **Run Project**: Flashes firmware to connected Pico
- **Flash**: Programs firmware via OpenOCD

#### VSCode Configuration
Set build options in `.vscode/settings.json`:

```json
{
  "cmake.configureArgs": [
    "-DPICO9918_ENABLE_SCART=ON",
    "-DPICO9918_NO_SPLASH=OFF",
    "-DPICO9918_DIAG=OFF"
  ]
}
```

### Firmware Architecture
- **Core 0**: TMS9918A emulation, host interface  
- **Core 1**: VGA output generation
- **PIO**: Hardware-timed signal generation
- **DMA**: Memory transfers and sprite processing
- **Flash**: Configuration storage in upper 1MB

### SDK Performance Patch

> **✅ Automatic Patch Application**
> 
> A performance patch is automatically applied for optimal boot times:
> - **Fast Boot**: Optimizes ROSC (Ring Oscillator) for faster startup  
> - **Automatic**: Applied by CMake when using `PICO_SDK_FETCH_FROM_GIT=ON`
> - **Manual Setup**: Still required when manually installing SDK (see platform instructions above)

#### How It Works
- **FetchContent builds**: CMake automatically applies `picosdk-2.0.0-visrealm-fastboot.patch` after downloading the SDK
- **Manual SDK installs**: You must run the `git apply` command shown in platform setup above
- **Safe Operation**: Patch command includes fallback - build continues even if patch fails

## Building Configurator

The configurator creates ROM files for retro computers that can upload firmware to PICO9918.

### Prerequisites - Configurator

> **✅ No Manual Tool Installation Required!** 
> 
> The build system **automatically downloads and builds** all required tools:
> - **CVBasic** (Retro BASIC compiler)
> - **GASM80** (Z80 assembler)  
> - **XDT99** (TI-99/4A development tools)
>
> Simply run the build commands below - all tools will be built from source automatically.

### Quick Start - Configurator

The recommended approach is the **combined build** above, which builds firmware and all configurator ROMs together and embeds the combined RP2040+RP2350 firmware in each ROM.

To build configurator ROMs against an existing firmware (standalone):
```bash
mkdir build && cd build
cmake .. -DPICO9918_BUILD_COMBINED=ON
cmake --build . --target combined
cmake --build . --target build_configurators
```

### Configurator Targets
- **`configurator_all`**: Build all configurator ROMs
- **`ti99`**: TI-99/4A ROM (8KB banks)
- **`coleco`**: ColecoVision ROM (16KB banks)
- **`msx_asc16`**: MSX ASCII16 mapper ROM
- **`msx_konami`**: MSX Konami mapper ROM
- **`nabu`**: NABU computer ROM
- **`creativision`**: CreatiVision ROM

### Individual Platform Builds
```bash
cmake --build . --target ti99              # TI-99/4A
cmake --build . --target coleco            # ColecoVision  
cmake --build . --target msx_asc16         # MSX
cmake --build . --target nabu              # NABU
cmake --build . --target creativision      # CreatiVision
```

### VSCode Configurator Tasks
- **Build All Configurator ROMs**: Build all configurator targets
- **Build TI-99 Configurator**: Build only TI-99/4A ROM  
- **Build ColecoVision Configurator**: Build only ColecoVision ROM
- **Build MSX Configurator**: Build only MSX ROM

All configurator tasks automatically depend on firmware build.

### Tool Auto-Building

> **🚀 Zero-Configuration Tool Management**
>
> **By default**, the build system automatically handles all configurator tools:

The system will automatically:
1. **Clone** tool repositories from GitHub
2. **Build** tools from source using CMake  
3. **Cache** built tools for subsequent builds
4. **Use** locally-built tools for ROM generation

**No manual tool installation needed!** Works on all platforms out-of-the-box.

#### Advanced: Use Pre-installed Tools (Optional)
If you have CVBasic, GASM80, and XDT99 already installed in PATH:
```bash
cmake .. -DBUILD_TOOLS_FROM_SOURCE=OFF
```

### Platform Support Matrix

| Platform | Banking | Output | Assembler | Notes |
|---|---|---|---|---|
| TI-99/4A | 8KB | `.bin` | XAS99 + linkticart | Cartridge format |
| ColecoVision | 16KB | `.rom` | GASM80 | Standard ROM |
| MSX ASCII16 | 16KB | `.rom` | GASM80 | ASCII16 mapper |
| MSX Konami | 16KB | `.rom` | GASM80 | Konami mapper |
| NABU | None | `.nabu` | GASM80 | NABU computer |
| CreatiVision | None | `.bin` | GASM80 | CreatiVision console |

## Combined Build (Recommended)

The combined build produces a single UF2 file that contains firmware for **both** PICO9918 (RP2040) and PICO9918 PRO (RP2350). Configurator ROMs built against this combined UF2 can update either device using the same ROM file.

Enable it with `-DPICO9918_BUILD_COMBINED=ON`:

```bash
mkdir build && cd build
cmake .. -DPICO9918_BUILD_COMBINED=ON
cmake --build . --target combined
cmake --build . --target build_configurators
```

All outputs land in `build/dist/`:
- **Combined firmware**: `pico9918-vga-<version>.uf2` - works on both RP2040 and RP2350
- **Configurator ROMs**: All platform ROMs, each embedding the combined firmware

### Ninja Generator (Faster)
```bash
cmake .. -DPICO9918_BUILD_COMBINED=ON -G Ninja
ninja combined
ninja build_configurators
```

### Parallel Builds
```bash
cmake --build . --target combined --parallel 8
```

## Firmware-Only Build

To build individual firmware images without the combined file:

```bash
mkdir build && cd build
cmake ..
cmake --build . --target firmware
```

Output: `build/dist/pico9918-vga-build-<version>.uf2` (RP2040 only)

For RP2350 (PICO9918 PRO) firmware only, set the board in CMake or use the combined build above.

## Cross-Platform Support

All major platforms are supported with consistent toolchains and build processes. See the **Platform-Specific Setup** section above for detailed installation instructions.

### Platform Summary
- **Windows**: Native build with ARM GNU Toolchain 13.2.1-1.1
- **Linux**: Native build with `gcc-arm-none-eabi` package  
- **macOS**: Native build with ARM GNU Toolchain 13.2.1-1.1 (for consistency)
- **WSL**: Use Linux instructions within Windows Subsystem for Linux

### Important Notes
- **Toolchain Consistency**: All platforms use ARM GNU Toolchain 13.2.1-1.1 to ensure identical builds
- **macOS Python**: May require `--break-system-packages` flag for pip on newer macOS versions
- **SDK Version**: Use Pico SDK 2.1.1 specifically - newer versions may cause linker issues

### Continuous Integration
The project includes GitHub Actions workflows that automatically build on every push:

#### Individual Platform Workflows
- **Firmware Windows**: `firmware-windows.yml` 
- **Firmware Linux**: `firmware-linux.yml`
- **Firmware macOS**: `firmware-macos.yml`
- **Configurator Windows**: `configurator-windows.yml`
- **Configurator Linux**: `configurator-linux.yml`
- **Configurator macOS**: `configurator-macos.yml`

#### Build Outputs
- **Firmware**: `.uf2` files for Raspberry Pi Pico
- **Configurator ROMs**: All retro platform ROM files
- **Artifacts**: Build outputs available for download from successful runs
- **Badges**: Individual build status badges for each OS and build type

## Output Structure

### Combined Build (`-DPICO9918_BUILD_COMBINED=ON`)
```
build/
├── dist/                                      # Final artifacts
│   ├── pico9918-vga-<version>.uf2             # Combined RP2040+RP2350 firmware
│   ├── pico9918_<version>_ti99_8.bin          # TI-99/4A ROM (with combined firmware)
│   ├── pico9918_<version>_cv.rom              # ColecoVision ROM
│   ├── pico9918_<version>_msx_asc16.rom       # MSX ROM
│   └── ...                                    # Other platform ROMs
├── pico9918/dist/                             # RP2040-only firmware
├── pico9918pro/dist/                          # RP2350-only firmware
└── configurators/                             # Configurator build tree
```

### Firmware-Only Build (default)
```
build/
├── dist/                                      # Final artifacts
│   └── pico9918-vga-build-<version>.uf2       # RP2040 firmware
└── src/                                       # Build intermediates
```

## Troubleshooting

### Firmware Issues
**Build fails with missing SDK**
```bash
# Install Raspberry Pi Pico SDK
# Set PICO_SDK_PATH environment variable
```

**SDK version compatibility issues**
```bash
# PICO9918 developed with Pico SDK 2.1.1
# SDK 2.2.0 may cause linker errors and memory overflow
# 
# Recommended: manually install Pico SDK 2.1.1 and set PICO_SDK_PATH
git clone -b 2.1.1 https://github.com/raspberrypi/pico-sdk.git
cd pico-sdk && git submodule update --init
export PICO_SDK_PATH=$PWD
cd ../your-build-directory
cmake ..

# Note: PICO_SDK_FETCH_FROM_GIT_TAG has known issues with tag resolution
```

**SDK patch issues**
```bash
# If patch fails to apply:
git apply --ignore-whitespace --ignore-space-change --3way ../picosdk-2.0.0-visrealm-fastboot.patch

# If patch was already applied or conflicts:
echo "Patch failed or already applied" # This is normal, firmware will still build

# Patch is optional but improves boot performance
# Firmware works without it, just boots slower
```

**Missing splash/font assets**
```bash
# Install pillow for image conversion
pip install pillow
```

### Configurator Issues  
**Missing tools error**
```bash
# Auto-build is enabled by default, but if you disabled it:
cmake .. -DBUILD_TOOLS_FROM_SOURCE=ON
```

**Firmware dependency error**
```bash
# Build firmware first
cmake --build .
```

### General Issues
**Clean build**
```bash
rm -rf build/
mkdir build && cd build
cmake ..
```

**Verbose output**
```bash
cmake --build . --verbose
```

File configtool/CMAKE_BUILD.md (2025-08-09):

# CMake Build System for PICO9918 Configurator

This directory contains a CMake-based build system that replaces the Windows batch file (`build.bat`) with a cross-platform solution.

## Features

- **Cross-platform**: Works on Windows, Linux, and macOS
- **Parallel builds**: Multiple platform targets can build simultaneously  
- **Better dependency tracking**: Only rebuilds what's changed
- **IDE integration**: Works with VSCode CMake extensions
- **Tool detection**: Automatically finds required compilers and tools
- **Auto-build tools**: Can checkout and build CVBasic, gasm80, and XDT99 from source

## Prerequisites

### Option 1: Use existing tools
- CMake 3.13 or later
- Python 3 (accessible as `python3`)
- CVBasic compiler (`cvbasic.exe`)
- GASM80 assembler (`gasm80.exe`) 
- XDT99 XAS99 assembler (for TI-99 builds)

### Option 2: Auto-build tools (Linux/cross-platform)
- CMake 3.13 or later
- Python 3 (accessible as `python3`)
- Git (for checking out tool repositories)
- C compiler (GCC or Clang for building tools)

## Usage

### Integrated Build (Recommended)
The configurator is now integrated into the main PICO9918 build system:

```bash
# Build from project root
mkdir build && cd build
cmake ..
make                    # Build firmware
make configurator_all   # Build all configurator ROMs
```

All final artifacts will be in `build/dist/`:
- **Firmware**: `pico9918-vga-build-v1-0-2.uf2`
- **Configurator ROMs**: `pico9918_v1-0-2_*.rom` / `pico9918_v1-0-2_*.bin`

### Standalone Build (Legacy)
```bash
cd configtool
mkdir build && cd build
cmake .. [-DBUILD_TOOLS_FROM_SOURCE=ON]
make configurator_all
```

### Build Individual Platforms
```bash
make ti99              # TI-99/4A
make ti99_f18a         # TI-99/4A F18A Testing  
make coleco            # ColecoVision
make msx_asc16         # MSX ASCII16 mapper
make msx_konami        # MSX Konami mapper
make nabu              # NABU
make creativision      # CreatiVision
make nabu_mame_package # NABU MAME (.npz)
```

### Build with Ninja (faster)
```bash
cmake .. -G Ninja [-DBUILD_TOOLS_FROM_SOURCE=ON]
ninja configurator_all
```

## How it Works

1. **Firmware Dependency**: Checks for pre-built firmware in `../build/src/`
2. **UF2 Conversion**: Converts firmware to CVBasic data using `uf2cvb.py`
3. **CVBasic Compilation**: Compiles `.bas` sources for each target platform
4. **Assembly**: Uses GASM80 (most platforms) or XAS99 (TI-99) for final ROM creation
5. **Packaging**: Creates platform-specific ROM files (.bin, .rom, .nabu, etc.)

## Platform Support

| Platform | Mapper/Banking | Output Format | Assembly Tool |
|---|---|---|---|
| TI-99/4A | 8KB banks | .bin cartridge | XAS99 + linkticart |
| ColecoVision | 16KB banks | .rom | GASM80 |
| MSX | ASCII16/Konami | .rom | GASM80 |
| NABU | No banking | .nabu/.npz | GASM80 |
| CreatiVision | No banking | .bin | GASM80 |

## Tool Detection

### Default Mode (existing tools)
The build system automatically searches for tools in:
1. `configtool/tools/cvbasic/` (bundled tools)
2. `../CVBasic/build/Release/` (local CVBasic build)  
3. System PATH
4. `c:/tools/xdt99/` (Windows) or `/usr/local/bin`, `/opt/xdt99` (Linux)

### Auto-build Mode (`-DBUILD_TOOLS_FROM_SOURCE=ON`)
When enabled, CMake will:
1. Clone CVBasic from https://github.com/visrealm/CVBasic.git
2. Clone gasm80 from https://github.com/visrealm/gasm80.git  
3. Clone XDT99 from https://github.com/endlos99/xdt99.git
4. Build CVBasic and gasm80 from source using their CMake systems
5. Install tools to `build/external/` directory
6. Use the locally-built tools for ROM generation

This mode enables fully cross-platform builds without pre-installed tools.

## Comparison with Batch Build

| Aspect | Batch File | CMake |
|---|---|---|
| Platform Support | Windows only | Cross-platform |
| Parallel Builds | Sequential | Parallel |
| Dependency Tracking | Manual | Automatic |
| IDE Integration | None | Full |
| Error Handling | Basic | Comprehensive |
| Maintenance | Complex batch logic | Declarative CMake |

## Backwards Compatibility

The original `build.bat` remains unchanged and functional. This CMake system is an alternative build method, not a replacement.

## Future Enhancements

- [ ] Automatic firmware building if not found
- [ ] CTest integration for ROM validation
- [ ] CPack for distribution packaging
- [ ] Cross-compilation support for ARM/embedded hosts

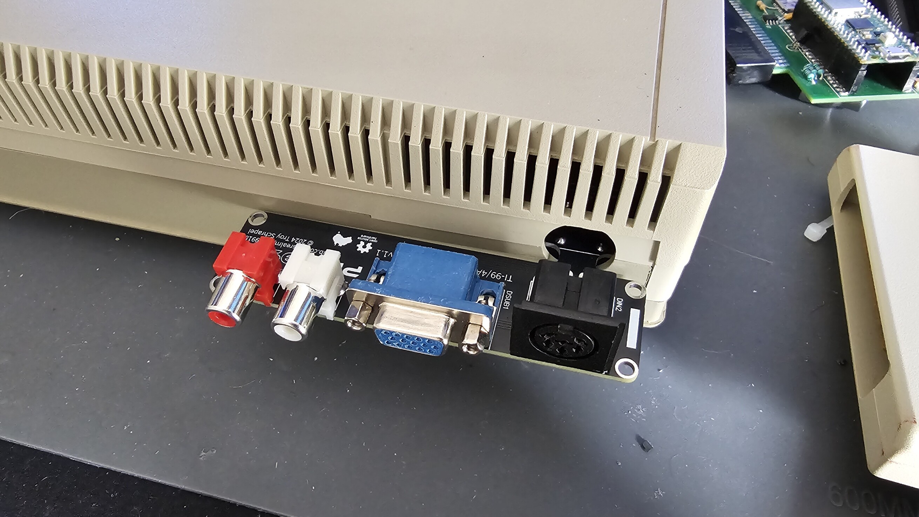
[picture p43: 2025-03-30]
nocut/ti99/img/nocut-ti99-installed-bare.jpg

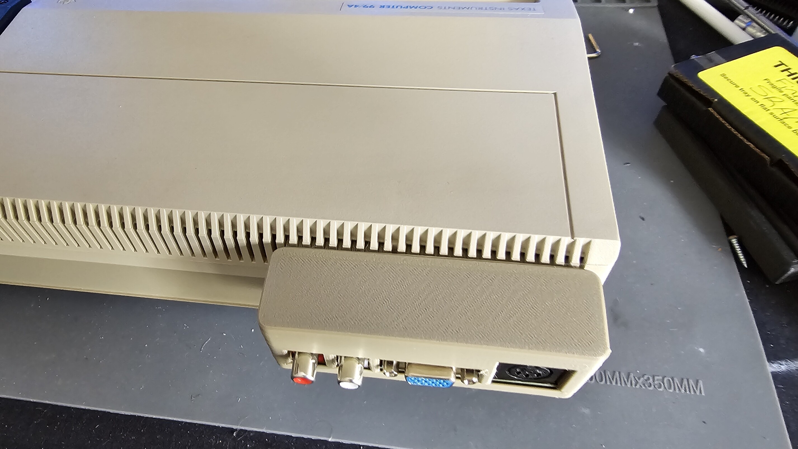
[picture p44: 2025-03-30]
nocut/ti99/img/nocut-ti99-installed-enclosure-2.jpeg

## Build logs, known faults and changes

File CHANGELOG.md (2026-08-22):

# Changelog

Every released version of the PICO9918 firmware and configurator. Dates are the release dates on
[Releases](https://github.com/visrealm/pico9918/releases), where the full notes and installation
instructions for each version live. For per-version detail, including which configuration setting
arrived in which version, see
[Firmware Version History](https://github.com/visrealm/pico9918/wiki/Firmware-Version-History).

Current firmware works on every official board: v0.3, v0.4 through v1.3, and PRO v2.0. A single
`.uf2` has carried both the RP2040 and RP2350 images since v1.1.0.

## Unreleased

Work past v1.2.0 lives on branches and is not downloadable. A lite (settings-only) configurator ROM
for the CreatiVision is planned for v1.2.1.

## v1.2.0 - 2026-07-12

First release with SCART RGB support out of the box.

### Added

* SCART RGB output, auto-detected at boot, giving PAL RGBs 576i @ 50 Hz through a 10-pin Sega Saturn
  A/V connector. Correct interlaced timing.
* Configurator output modes: Auto (default), VGA/HDMI and SCART, with the SCART display mode
  switchable between PAL 576i @ 50 Hz and NTSC 480i @ 60 Hz.
* Local build configuration file, so build settings no longer need `-D` flags on every invocation.
  See [Local Build Config File](BUILDING.md#local-build-config-file).

### Changed

* Clock and output changes are now confirmed on the next boot and rolled back automatically if the
  configurator is not reopened, so a setting that kills the picture undoes itself.
* Minor GPU performance improvements.
* The configurator forces a firmware upgrade when it does not detect a supported version.

## v1.1.1 - 2026-04-18

### Added

* Device mode configuration, which matches the GROMCLK and CPUCLK outputs to a specific TMS9918
  family member: TMS9918A (default), TMS992xA, TMS9118 and TMS912x. Web configurator only.
* EGA palette preset.
* NABU and CreatiVision no-cut mod documentation and STLs.

### Fixed

* Visual glitches on some devices in 48- and 60-row modes.
* UF2 block count in the web configurator.
* TI-99 bank count rounding, which affected custom SCART firmware in earlier versions.

## v1.1.0 - 2026-04-03

First release supporting the RP2350-based PICO9918 PRO.

### Added

* PICO9918 PRO (RP2350) hardware support, with detection and device information in the configurator.
* Combined `.uf2` carrying firmware for both the PICO9918 and the PRO, so one ROM updates either.
* Lite configurator builds for the TI-99, MSX and ColecoVision, without firmware update support.
* Schematics and gerbers for the v1.3 and v2.0 boards, and for the VGA v1.2 and HDMI v1.1 dongles.
* Digital A/V dongle wiring guide, FFC cable notes, and MDE1 and solder jumper documentation.

### Changed

* Interrupt timing, improving compatibility with some systems.
* The diagnostics screen timeout is now 15 seconds.

### Fixed

* Sprite collision triggering incorrectly when sprites moved off the right edge of the screen.
* Graphical glitch in multi-page mode with the colour table at address `0xX800`.

## v1.0.3 - 2026-02-15

### Added

* 48- and 60-row modes, enabled by R0 bit 3.
* Opaque sprites, via SAT entry bit 4 when global 16px sprites are enabled.
* Optional palette reset with the register reset command: write `0xC0` to VR `0x32`.
* Firmware and hardware versions on the performance diagnostic overlay.
* Predefined TMS9918A, V9938 and GREY palettes in the configurator.
* PICO9918 support in [JS99'er](https://js99er.visrealm.au).

### Changed

* Automatic diagnostic overlays now disappear once the host enables the display.
* TEXT80 rendering performance improvements.
* CPU to VDP interface reworked with software debounce and corrected delays.

### Fixed

* Position-based attributes on the T1 layer with multiple pages.
* Sprite Y-flip off by one row.
* ECM sprites using base palette 0.
* v0.3 hardware detection.

## v1.0.2 - 2025-10-06

### Added

* SG-1000 and SC-3000 configurator builds.
* macOS build support, and GitHub Actions building every firmware and configurator target.

### Changed

* The Pi Pico SDK boot performance patch is applied automatically.
* Configurator builds moved to CMake, with automatic build tool configuration.

### Fixed

* VRAM read and write 16 KB rollover, which fixes ColecoVision Konami Ping Pong.
* CPU interface read performance, which fixes ColecoVision Buck Rogers Super Game screen corruption.

## v1.0.1 - 2025-05-04

First beta of the unified firmware and software tools, and the release that made the PICO9918
configurable from the machine it is fitted to.

### Added

* Firmware updates over software, from a configurator ROM running on the host.
* Configuration changes over software: scanlines, maximum sprites, core clock speed, diagnostic
  overlays and default palette.
* F18A compatibility mode, included by default.
* Configurator releases for the TI-99/4A, ColecoVision and MSX.
* Hardware autodetection, adapting to v0.3, v0.4 and v1.0+ boards automatically.

## v0.4.4 - 2025-03-30

### Fixed

* Write PIO timing on the CreatiVision, and potentially other machines.

## v0.4.3 - 2024-10-19

### Added

* SCART RGBs builds: NTSC 480i @ 60 Hz and PAL 576i @ 50 Hz.

### Fixed

* v0.3 board configuration not carried through to the build.

### Reverted

* The faster TMS read PIO, after problems on MSX machines.

## v0.4.2 - 2024-10-09

### Added

* More than four sprites per scanline, enabled by default.
* Binary info.

### Changed

* Updated to Pico SDK 2.0.0.
* Removed the explicit TMS to CPU interface PIO delays.

### Fixed

* 80-column mode fixes.

## v0.4.1-f18a-preview1 - 2024-10-09

Pre-release. First public F18A support. Not every combination of display mode and feature was
implemented at this point.

### Added

* Enhanced colour mode (ECM) tiles in Graphics I mode, and ECM sprites in all display modes.
* Second tile layer in 80-column text and Graphics I modes.
* Bitmap layer.
* Position-based attributes for 80-column text and Graphics I modes.
* TMS9900 GPU core.

## v0.4.1 - 2024-08-21

### Fixed

* Status register responsiveness.
* VGA scale multiplier.

## v0.4.0 - 2024-08-04

First release for the integrated v0.4 board, with binaries for both the v0.3 and v0.4 boards.

## v0.3.1 - 2024-07-12

### Changed

* Moved the VDP to CPU interface from GPIO interrupts to PIO. The whole design still rests on this.
* Reduced the binary to about 26 KB, with many performance improvements.

## v0.3 - 2024-06-25

First release. Compatible with the [v0.3 board](pcb/v0.3), which piggy-backs an external Pi Pico.

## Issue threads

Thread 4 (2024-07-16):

Is there a BOM?

cbmeeks, 2024-07-16:
Just to make sure I don't order the wrong parts (especially for the resistor networks), do you have a BOM or at least some part numbers from Mouser or Digikey?

Also, what sizes are those caps/resistors?

Thanks!

cbmeeks, 2024-07-16:
Sorry, I didn't notice the BOM in the v3 folder.

Closed 2024-07-16.

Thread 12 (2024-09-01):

Comments in main.c are misleading vis a vis CD0-CD7

thorpej, 2024-09-01:
The comments in main.c about the CD0-CD7 pin mappings are misleading.  TI's convention calls the LSB "CD7" and the MSB "CD0".  The nomenclature is correct on the v0.3 schematic, but the comments in main.c are incorrect.  A corrected comment block would be:

```
  * Pin  | GPIO | Name      | TMS9918A Pin
  * -----+------+-----------+-------------
  *  19  |  14  |  CD7      |  17         LEAST SIGNIFICANT BIT
  *  20  |  15  |  CD6      |  18
  *  21  |  16  |  CD5      |  19
  *  22  |  17  |  CD4      |  20
  *  24  |  18  |  CD3      |  21
  *  25  |  19  |  CD2      |  22
  *  26  |  20  |  CD1      |  23
  *  27  |  21  |  CD0      |  24         MOST SIGNIFICANT BIT
.
.
.
```

I also suggest renaming the constant ```GPIO_CD0``` to ```GPIO_CD7```.

visrealm, 2024-09-01:
Thanks. You're right, this was left over from v0.2 which actually had this pinout. They were reversed like this resulting in any gpio operations on the CD0-7 pins needing to be reversed via a lookup table. It was a messy time. 😁

visrealm, 2024-09-01:
Closed as fixed in dev

Closed 2024-09-01.

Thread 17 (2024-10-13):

Compiling from command line errors

chris-jh, 2024-10-13:
Two errors show up when trying to build from command ( i am on a mac doing this, but think it would be same for all OS's)

First was to do with panic.c and second was to do with irq.c from the pico-idk.

panic.c was 'error: expected ')' before ':' token"

ira.c was "fatal error: pico/runtime_init.h: No such file or directory"

i fixed both errors by changing the /src/pio-utils/CMakeLists.txt file

I added

`target_compile_options(${PROJECT_NAME} PUBLIC -include pico/platform/compiler.h)`

at the end of the file

and changed this line to include the pico_stdlib

`target_link_libraries(${LIBRARY} PUBLIC hardware_pio pico_stdlib)`

For me this made it build, (after installing pillow for python also)

I built a v0.3 pcb, what do i change to build for this PCB ?

visrealm, 2024-10-14:
Thanks for the report. I don't have a Mac to test, but if your changes work on my other test platforms, I'll add them in.

Building for 0.3 is just a matter of setting:

`set(PICO9918_PCB_MINOR_VER 3)`

in src/CMakeLists.txt

chris-jh, 2024-10-14:
Thought it was this, just that the uf2 file still had 0.4 in the name and wasn't 100% sure.

One more thing i noticed with the 0.3pcb, not sure about your 0.4. I can see the cpuclock on pin 23 on the pico itself. but what comes out to the main board, it is not a clock signal.

I assume the HC08 is doing something to the signal. i also have 0 ohm resistors installed.

Working on a clone SVI-328 and had the RGB output working (TMS9929ANL), but then i broke my 3.54Mhz on the main board, so thought could use the VDP CPU Clock and that is when i noticed the signal was not correct.

I can add this an other issue if you like

Will this output a composite signal at some point ?

visrealm, 2024-10-15:
I've checked a couple of my v0.3 boards on the scope and verify, I'm getting a 3.579MHz signal out of the CPUCLK pin of the TMS9918A socket on both of them. There must be something awry between the PICO pin 23 and the TMS9918A pin as you said.  The HC08 just boosts the 3.3V signal to 5V having the 3.3V signal going to both inputs of one channel and the output going to the CPUCLK 0Ohm resistor/jumper.

I have no plans to support composite output. I think it's technically possible, but it's not something I'm interested in.

visrealm, 2024-11-05:
I've added your changes. Closing as fixed.

Thanks.

Closed 2024-11-05.

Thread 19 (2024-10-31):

PCB rev 3 - 0 ohm resistors placement.

repetto74, 2024-10-31:
Hello :-),

I assume that 0 ohm resistors should be soldered in position marked CPU, GROM and RST? I do not see any position marked R16, R1 and R2 as indicated in the BOM.

Great project!! :-D

repetto74, 2024-10-31:
Ok sorry found it on the schematic :-).

visrealm, 2024-11-01:
Hi, glad you persisted :)
As noted in the README, you might also want to not place the RST jumper (remove it). If it works for you with it in place, then leave it, otherwise, remove it.
Cheers
Troy

Closed 2024-10-31.

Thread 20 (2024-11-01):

Pico RP2040 black clone cannot boot when installed on main PCB.

repetto74, 2024-11-01:
Hello again :-)

Any idea why I cannot get this Pico black clone to show up on my PC? I am under MacOSX but with either the purple clone or the original Pico I can get them to show-up as disk drives on my desktop once connected in boot mode.

For this black Pico nothing is showing up when I hook it up to my PC with the boot button pressed :-(

**EDIT**: I have another black Pico and it works. I though finally that the Pico I soldered was defective so I desoldered it and replaced it with the working one. Well now the assumed non-working Pico is showing up normally when not soldered to the main Pico9918 PCB. Is there something preventing the Pico to be programmed when installed on the PCB? Is it the RST line with the zero  ohm jumper?

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

repetto74, 2024-11-01:
The pico is busted :-(. I have another black Pico and this one works. Too bad I have soldered the one not working!

visrealm, 2024-11-01:
That's a great point and probably is the cause of these issues. I suggest removing the RST jumper. You don't really need it.

repetto74, 2024-11-01:
Thanks I will try to remove the 0 ohm resistor on the RST position and test again.

repetto74, 2024-11-02:
I confirm that removing the RST jumper will fix this issue and the pico will boot also if installed on the PCB :-).

repetto74, 2024-11-03:
So all looks good on my MSX HX-10. The wrong purple tint is probably due to missing 75 ohms resistors in my SCART cable. I have to add those resistors on the output connector in the MSX. Looks good anyway! :-D
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

visrealm, 2024-11-04:
From AA:

4 hours ago, [visrealm](https://forums.atariage.com/?app=core&module=members&controller=profile&id=77331) said:
This looks like the green output of RGB isn't connected.

Ok, I'll need to check the wirings then.😅 Maybe a soldering not properly done. I'll check with the schematic.

EDIT: I found that resistor array RN6 has two legs not properly soldered. There is no continuity between GREEN signal and G1.

Closing

Closed 2024-11-04.

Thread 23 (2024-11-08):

Is expanded functionality planned?

Unilein, 2024-11-08:
Is there a plan to expand the functionality in principle? For example, an expanded or alternative color palette? Or other resolutions, more sprites or multi-colored sprites?

I use a classic TMS9918A in my homebrew project and am considering switching. Either to a self-developed unit or to your project, if there are any further extensions to be expected.

Regards
Unilein

visrealm, 2024-11-08:
Hi Unilein.

There is already F18A support. The F18A has custom palettes, 80 column mode, multi-color sprites, multi-color tiles, hardware scrolling, a bitmap layer plus two tile layers. Here's a quich demo video showing the PICO9918's F18A compatibility mode in action: [PICO9918 F18A mode preview demo (screen capture)](https://youtu.be/TabTIPL1xQY).

F18A mode isn't yet in the main branch, but I have binaries for it: https://github.com/visrealm/pico9918/releases/tag/v0.4.1-f18a-preview1

I'm also working on V9938 compatibility.

Cheers
Troy

Unilein, 2024-11-09:
Great!

I will order PCB's today :-)

Cheers
Unilein

Closed 2024-11-09.

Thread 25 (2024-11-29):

KICad source for v1.1?

hexbus, 2024-11-29:
Hey @visrealm -

Thank you for your continued work and for sharing the Pico9918 project under the CERN Open Hardware License. I’m interested in reproducing and potentially modifying the project, but I noticed that the KiCad source files are not included in the repository.

As the license requires providing the “Complete Source” in the preferred form for making modifications, I kindly ask that you add the native KiCad project files (or EasyEDA, or whatever PCB program you used) to the v1.1 repository. Having access to these files would enable me to fully reproduce and modify the design for my and my local computer group's use, including having the PCB manufactured with SMT components preassembled by JLCPCB. Since I cannot hand place SMT components, this step is essential for me to work with the project.

I truly appreciate your efforts in sharing open hardware and look forward to your response. Please let me know if I can assist or if there are other ways to contribute to the project.

Thanks!
Jon/@hexbus

visrealm, 2024-11-29:
Hi Jon. I suggest going with v1.2 as it provides the most output options down the track. I've published the project here: https://oshwlab.com/visrealm/pico9918-v1-2

Closed 2024-11-29.

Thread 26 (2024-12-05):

"Issue with CSW_L_PIN in Pico9918 VRAM Write Operation Affecting Color Cycle and Text Display

DonaldMoran, 2024-12-05:
I have v0.4.3, on a pico from DWEII, the USB-C one, which I intend to use on a homegrown 65c02. To learn to use it, I have first wired it up to a second Pico W, with the intention of cycling through the colors and writing "Hello, World!" to the screen.

The following code cycles the colors as expected; however, I had to comment out the lines in void write_vram that set the CSW_L_PIN low, i.e., //gpio_put(CSW_L_PIN, 0);

If I uncomment those lines, the first screen color change occurs, but from there, no additional screen color changes and no text appears. The program does run to completion. Leaving the lines commented as in the example below, the program runs and the screen colors cycle.

I feel I might be doing something wrong here, but reaching out as my research hasn't helped thus far. I am new to the Pico9918 and the TMS9918A in general.

If you could take a quick look, I would appreciate it. Also, knowing this uses the emulation library, I have assumed there is a default character pattern.

PS - Nice seeing you over at the 6502 forum and appreciate you.

```
#include "pico/stdlib.h"
#include <stdio.h>

#define CSW_L_PIN 27
#define MODE_PIN 28
#define DATA_PINS {14, 15, 16, 17, 18, 19, 20, 21}  // CD7 (bit 7) to CD0 (bit 0)

const char* color_names[] = {"TRANSPARENT", "BLACK", "MEDIUM GREEN", "LIGHT GREEN", "DARK BLUE", "LIGHT BLUE", "DARK RED", "CYAN", "MEDIUM RED", "LIGHT RED", "DARK YELLOW", "LIGHT YELLOW", "DARK GREEN", "MAGENTA", "GRAY", "WHITE"};
const uint8_t ti_colors[] = {0x00, 0x01, 0x02, 0x03, 0x04, 0x05, 0x06, 0x07, 0x08, 0x09, 0x0A, 0x0B, 0x0C, 0x0D, 0x0E, 0x0F};

void setup_gpio();
void set_data_pins(uint8_t byte);
void send_byte(uint8_t byte);
void set_mode();
void write_vram(uint16_t address, uint8_t data);
void write_name_table(uint16_t address, uint8_t data);
void display_text();
void cycle_colors();

int main() {
    stdio_init_all();
    printf("Starting setup...\n");

    // Initial wait
    printf("Initial wait...\n");
    sleep_ms(5000);

    // Double initialization to stabilize state
    printf("First initialization...\n");
    setup_gpio();
    set_mode();

    printf("Second initialization...\n");
    setup_gpio();
    set_mode();

    // Cycle through TI-99/4A TMS9918A colors with "AB" text
    cycle_colors();

    printf("Program complete.\n");

    return 0;
}

void setup_gpio() {
    static const uint8_t data_pins[] = DATA_PINS;

    for (int i = 0; i < 8; i++) {
        gpio_init(data_pins[i]);
        gpio_set_dir(data_pins[i], GPIO_OUT);
        gpio_put(data_pins[i], 0);  // Set all data pins low initially
    }
    gpio_init(CSW_L_PIN);
    gpio_set_dir(CSW_L_PIN, GPIO_OUT);
    gpio_put(CSW_L_PIN, 1);  // Set CSW_L_PIN high initially

    gpio_init(MODE_PIN);
    gpio_set_dir(MODE_PIN, GPIO_OUT);
    gpio_put(MODE_PIN, 1);  // Set MODE_PIN high initially (command mode)

    stdio_init_all();
    printf("GPIO setup complete.\n");
}

void set_data_pins(uint8_t byte) {
    static const uint8_t data_pins[] = DATA_PINS;
    for (int i = 0; i < 8; i++) {
        gpio_put(data_pins[i], (byte >> i) & 1);  // Set data pins
    }
    sleep_us(50);  // Small delay to stabilize
    printf("Data pins set to 0x%02X\n", byte);
}

void send_byte(uint8_t byte) {
    set_data_pins(byte);
    gpio_put(CSW_L_PIN, 0);  // Start the write operation
    sleep_us(200);  // Delay to ensure the byte is latched
    gpio_put(CSW_L_PIN, 1);  // End the write operation
    sleep_us(100);  // Small delay to stabilize
    printf("Data byte 0x%02X sent.\n", byte);
}

void set_mode() {
    printf("Setting mode to Text mode (000 1011)...\n");
    send_byte(0x80 | 0x00);  // Register 0 (Mode)
    send_byte(0x0B);  // Text mode (000 1011)
    printf("Mode set to Text mode.\n");
}

void write_vram(uint16_t address, uint8_t data) {
    printf("Preparing to write VRAM - Address: 0x%04X, Data: 0x%02X\n", address, data);

    gpio_put(MODE_PIN, 0);  // Switch to VRAM mode
    sleep_us(50);  // Small delay to stabilize

    // High byte of address
    set_data_pins(0x40 | (address >> 8));
    //gpio_put(CSW_L_PIN, 0);  // Start the write operation
    sleep_us(50);  // Small delay to stabilize
    gpio_put(CSW_L_PIN, 1);  // End the write operation
    sleep_us(50);  // Small delay to stabilize

    // Low byte of address
    set_data_pins(address & 0xFF);
    //gpio_put(CSW_L_PIN, 0);  // Start the write operation
    sleep_us(50);  // Small delay to stabilize
    gpio_put(CSW_L_PIN, 1);  // End the write operation
    sleep_us(50);  // Small delay to stabilize

    // Data byte
    set_data_pins(data);
    //gpio_put(CSW_L_PIN, 0);  // Start the write operation
    sleep_us(50);  // Small delay to stabilize
    gpio_put(CSW_L_PIN, 1);  // End the write operation
    sleep_us(50);  // Small delay to stabilize

    gpio_put(MODE_PIN, 1);  // Switch back to command mode
    sleep_us(50);  // Small delay to stabilize

    printf("Finished writing to VRAM - Address: 0x%04X, Data: 0x%02X\n", address, data);
}

void write_name_table(uint16_t address, uint8_t data) {
    write_vram(address, data);
}

void display_text() {
    const char* text = "AB";
    uint16_t vram_address = 0x3800;  // Starting VRAM address for name table
    while (*text) {
        printf("Displaying character: %c at VRAM address: 0x%04X\n", *text, vram_address);
        write_name_table(vram_address++, *text++);
        sleep_us(200);  // Small delay to stabilize
    }
}

void cycle_colors() {
    printf("Cycling through TI-99/4A TMS9918A colors...\n");
    for (int i = 0; i < 16; i++) {
        send_byte(0x80 | 0x07);  // Write to VDP register 7 (Background color)
        send_byte(ti_colors[i]); // Set the background color
        printf("Displaying color %s (0x%02X).\n", color_names[i], ti_colors[i]);
        sleep_ms(2000);  // Delay to display each color

        // Display text on each color screen
        display_text();
    }
    printf("Color cycling complete.\n");
}
```

visrealm, 2024-12-06:
Hi, you definitely need those lines of code. Without them, you're not getting the required pulses on the CSW pin.

1. Is your PICO9918 CSR pin held high? It should be.
2. There are no default patterns in its VRAM. It emulates a real TMS9918A which obviously also doesn't have any default data in VRAM.

So, you'll need to check the CSR line. And also, you'll need to load font pattern data.

DonaldMoran, 2024-12-06:
I appreciate your response. Yes, I have tied CSR high to 3.3V. I will look into loading the font pattern data as suggested, however this strange issue continues with vram_write. When I uncomment any of the lines that bring CSW_L_PIN low within the write_vram routine, the screen changes stop. Interestingly, the set of CSW_L_PIN low is within the send_byte() while cycling the screen colors without any issues. Initially, I used send_byte() for VRAM writes, but I separated it out while troubleshooting this.

visrealm, 2024-12-06:
Just looking at your write_vram() function. The address needs to be written with MODE high.

DonaldMoran, 2024-12-06:
Thank you, that will help for sure, however I do still get the same result. Also visrealm,  I realize this will surely be an issue from my lack of knowledge and not a repo issue, I just thought this may be the best way to reach out. I will keep working at this until I get it! I know of the examples and data sheets. If you know any other good resources for a beginner like me, I would appreciate being pointed in that direction. I am familiar with the pico as well as pio, it is the tms9918a I am new to. I love this project by the way, awesome work! This is something to be proud of for sure! Thanks for your time.

DonaldMoran, 2024-12-06:
Hello visrealm,

I've updated my code to load a pattern into the pattern table, making sure the mode pin is set high for writing addresses and low for data. I've reverted to using the send_byte() routine and ensured that the proper pin for CSR is tied high.

The code below runs and cycles through the screen colors. However, it currently only does so if the following lines are commented out, or set to prevent any data from being sent to the pico9918:

In the int main(), I have commented out the loading of the font pattern.
```    // Load the font pattern for 'A' into VRAM
    //load_font_patterns();
```

In the display_text() function, I have set the single character that I am attempting to write to the screen as null.

```
     //const char* text = "A";
    const char* text = "";
```

The code provided will facilitate changes in screen color.

```#include "pico/stdlib.h"
#include <stdio.h>

#define CSW_L_PIN 27
#define MODE_PIN 28
#define DATA_PINS {14, 15, 16, 17, 18, 19, 20, 21}  // CD7 (bit 7) to CD0 (bit 0)

const char* color_names[] = {"TRANSPARENT", "BLACK", "MEDIUM GREEN", "LIGHT GREEN", "DARK BLUE", "LIGHT BLUE", "DARK RED", "CYAN", "MEDIUM RED", "LIGHT RED", "DARK YELLOW", "LIGHT YELLOW", "DARK GREEN", "MAGENTA", "GRAY", "WHITE"};
const uint8_t ti_colors[] = {0x00, 0x01, 0x02, 0x03, 0x04, 0x05, 0x06, 0x07, 0x08, 0x09, 0x0A, 0x0B, 0x0C, 0x0D, 0x0E, 0x0F};

//#define TMS_DEFAULT_VRAM_NAME_ADDRESS          0x3800
//#define TMS_DEFAULT_VRAM_COLOR_ADDRESS         0x0000
//#define TMS_DEFAULT_VRAM_PATT_ADDRESS          0x2000
//#define TMS_DEFAULT_VRAM_SPRITE_ATTR_ADDRESS   0x3B00
//#define TMS_DEFAULT_VRAM_SPRITE_PATT_ADDRESS   0x1800

// Font pattern for the character 'A'
const uint8_t font_patterns[] = {
    0x18, 0x24, 0x42, 0x42, 0x7E, 0x42, 0x42, 0x42
};

void setup_gpio();
void set_data_pins(uint8_t byte);
void send_byte(uint8_t byte);
void set_mode();
void write_vram(uint16_t address, uint8_t data);
void write_name_table(uint16_t address, uint8_t data);
void load_font_patterns();
void display_text();
void cycle_colors();

int main() {
    stdio_init_all();
    printf("Starting setup...\n");

    // Initial wait
    printf("Initial wait...\n");
    sleep_ms(5000);

    // Double initialization to stabilize state
    printf("First initialization...\n");
    setup_gpio();
    set_mode();
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
DonaldMoran, 2024-12-08:
Hi visrealm,

I think I'm having trouble because I've been trying to do this without the PCB, just using a couple of pico boards. I suspect the logic of the other chips, like the 74hc08, is necessary for this to work correctly. Though I do have a TI-99/4A and intend to get the PCB, I was trying to make this work on a breadboard with a homebrew 6502, thinking the PCB wasn't needed as I didn't need GROMCLK or CPUCLK.

At least through trying to make this work, I have learned more about how to work with the pico9918/tms9918!

I should probably close this issue, as I suspect there isn't any issue with the repository. I just thought this was the best way to reach out to you. I'll leave it open for now in hopes of a reply.

Thanks for your awesome project!

DonaldMoran, 2024-12-14:
This is obviously not a repo issue, but most likely because I've been trying to do this without the PCB, just using a couple of pico boards. I did attempt to order the PCB, but was stalled with the question: "PCBWay needs clarification on whether your Pico9918 v0.3 board is designed as a 4-layer or 2-layer PCB."

Thanks.

DonaldMoran, 2024-12-14:
This is obviously not a repo issue, but most likely because I've been trying to do this without the PCB, just using a couple of pico boards. I did attempt to order the PCB, but was stalled with the question: "PCBWay needs clarification on whether your Pico9918 v0.3 board is designed as a 4-layer or 2-layer PCB."

Thanks.

visrealm, 2024-12-16:
Hi, all boards are 4 layers.

I do plan to try your code once I get the time to set it up.

DonaldMoran, 2024-12-17:
Excellent, thank you visrealm! I'll look at JLCPCB. If you do get the chance to take a look at this, please post back, I'll be interested.

Merry Christmas to you and yours!

Closed 2024-12-14.

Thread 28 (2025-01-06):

Add hardware configuration flexibility to pico9918 build system

thorpej, 2025-01-06:
pico9918 is fantastic, and I've been using a modified version of it in a couple of different projects.  Namely, CoPicoVision, a ColecoVision clone that uses a Pi Pico module for the display, and a small BASIC computer running my own BASIC interpreter natively on a Pi Pico, which uses the 9918 emulation and VGA engine from pico9918 for it's native text/graphics display/terminal emulator (in this case, the "bus interface" is not using PIO, but rather a native interface using shared memory buffers and the multicore FIFO to communicate from the BASIC side to the display side).

In order to facilitate the hardware differences from the base pico9918 module, I've added some hooks to the pico9918 build system to make it easier to make the necessary configuration tweaks without having to modify pico9918 directly.  The config parameters are placed into a CMake file:

```
dhcp-194:thorpej$ cat CoPicoVision_pico9918_config.cmake
set(PICO9918_RESTRICTED_HW_RPI_PICO 1)
set(PICO9918_INT_ACTIVE_HIGH 1)
dhcp-194:thorpej$
```

...and this config file is used like so:

```
dhcp-194:thorpej$ cat build.sh
#!/bin/sh -

#
# Build the CoPicoVision version of the pico9918 firmware.
#

FIRMWARE_DIR=$PWD
PICO9918_CONFIG="${FIRMWARE_DIR}/CoPicoVision_pico9918_config.cmake"
PICO9918_DIR="${FIRMWARE_DIR}/../../submodules/pico9918"

rm -rf ${FIRMWARE_DIR}/build || exit 1
mkdir ${FIRMWARE_DIR}/build
cd ${FIRMWARE_DIR}/build || exit 1
cmake -DPICO9918_CONFIG="${PICO9918_CONFIG}" ${PICO9918_DIR} || exit 1
cmake --build . || exit 1
mv ${FIRMWARE_DIR}/build/src/pico9918.uf2 \
    ${FIRMWARE_DIR}/CoPicoVision_pico9918.uf2 || exit 1
cd ${FIRMWARE_DIR} || exit 1
rm -rf ${FIRMWARE_DIR}/build || exit 1

exit 0
dhcp-194:thorpej$
```

thorpej, 2025-01-06:
A pull request that implements these changes is forthcoming.

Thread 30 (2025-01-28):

nocutr parts list

smccloud, 2025-01-28:
I'm looking at buying a nocut PCB from Arcadeshopper since shipping is much less than it is from you in Australia (sorry).  However, I'm wondering if you have a parts list for the JST version (including the cable).

MMarcoux66, 2025-01-28:
If you are in the US and can solder, I bought 5 of the boards and parts but only need 2 or 3 so I have extras. I have the JST version.

MMarcoux66, 2025-01-28:
Are you talking about the JST cable that goes from the PICO9918? One should come with the chip.

I have the PCB board, both audio jacks, the JST connector, jumper and the VGA port. I have 3D printed the cover and the spacers. I just have not had time to do the soldering. I have enough to build 5. If you want to build your own, I can hook you up with the parts as I don't need 5 :).

Since I wanted to use one in a ColecoVision, Tony pointed me to an extension that you can get from Aliexpress. Is that the jumper cable you are looking for?

smccloud, 2025-01-28:
I am talking about the female-to-female JST cable; my PICO9918 came with a female JST-to-female VGA cable.  As for the 3D printed housing, I should have my "slightly modified" Ender 3 back up and =working again soon so I can print my own.

MMarcoux66, 2025-01-28:
Gotcha. I totally missed that when I made my shopping list. I need to look for some for myself. What you are looking for is JST 1.25mm cables. I will have to look more later, but these would work if spliced.

https://www.aliexpress.us/item/3256802350081389.html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

smccloud, 2025-01-28:
Looks like these should work, I hate ordering from Aliexpress.
https://amzn.to/4gici0V

visrealm, 2025-01-28:
I'll do up a BOM for each board type in the next day or so. Just be aware, those JST cables from Amazon will need wither the connector soldered to the bottom of the PCB or the pins manually reversed on one side.

smccloud, 2025-01-28:
> I'll do up a BOM for each board type in the next day or so. Just be aware, those JST cables from Amazon will need wither the connector soldered to the bottom of the PCB or the pins manually reversed on one side.

I can reverse the pins; it is no huge deal for me.  I'm odd in that soldering through hole stuff is relaxing for me.  Uncloging my Ender 3 hotend right now, not so much......

MMarcoux66, 2025-01-28:
Does $10 plus shipping sound fair? I believe that I have $50 total in parts.

Yeah, those Enders can be a lot of fun. I bought a Bambu a year ago and love it compared to the Ender it replaced...

MMarcoux66, 2025-01-28:
Cool. Feel free to email me at mmarcoux66 on Hotmail or same ID through Atariage PM messenger. Whichever you prefer.

Yeah, that is some crazy stuff with the FW but I do love my Bambus and too late for me to change since I already made the investment.

visrealm, 2025-01-28:
It also just occurred to me, if you're ordering from ArcadeShopper, he has the latest version (v1.3) which can be with JST or FFC. It uses a slimmer VGA connector than the order style JST-only boards. If @MMarcoux66 has the previos JST-only board, the VGA connector won't fit.

This is the VGA connector for the combined no-cut board: https://www.lcsc.com/product-detail/D-Sub-VGA-Connectors_HOAUC-HYC06-HDR15B-060_C711364.html

MMarcoux66, 2025-01-28:
Yes, when I originally ordered parts, I ordered that slimmer version instead of the bigger one for the boards which I have.

visrealm, 2025-01-29:
> I'm looking at buying a nocut PCB from Arcadeshopper since shipping is much less than it is from you in Australia (sorry). However, I'm wondering if you have a parts list for the JST version (including the cable).

I've just noticed his PCB price is the same as my full kit price. $20USD. Shipping will be extra for sure, but probably wouldn't turn out to be any cheaper overall I don't think.

smccloud, 2025-01-30:
> It also just occurred to me, if you're ordering from ArcadeShopper, he has the latest version (v1.3) which can be either JST or FFC. It uses a slimmer VGA connector than the older style JST-only boards. If [@MMarcoux66](https://github.com/MMarcoux66) has the previous JST-only board, the VGA connector won't fit.
>
> This is the VGA connector for the combined no-cut board: https://www.lcsc.com/product-detail/D-Sub-VGA-Connectors_HOAUC-HYC06-HDR15B-060_C711364.html

My PICO9918 has the VGA connector directly connected to the JST wires, so it doesn't matter to me either way.

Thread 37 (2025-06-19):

trying to compile the source

grafzahl12345, 2025-06-19:
hello,
 i'm trying to compile the source but reinstalling all source codes, Visual Studio and Pico SDK doesn't get me anywhere.
Which cmake pack and cmake tools do you use in Visual Studio ?

First error is in subdir of vrEmuTms9918. I install the branch pico9918 of the github.

_CMake Error at submodules/vrEmuTms9918/CMakeLists.txt:13 (target_link_libraries):
[cmake]   Cannot specify link libraries for target "PRIVATE" which is not built by
[cmake]   this project.
[cmake]_

my goal was to exchange pin of D0 - D7 in reverse order dune to mishaps by pcb layout. Is there a smart way to change the pin layout, i only found declaration of CD7 pin 14.

thx sebastian

Closed 2025-06-21.

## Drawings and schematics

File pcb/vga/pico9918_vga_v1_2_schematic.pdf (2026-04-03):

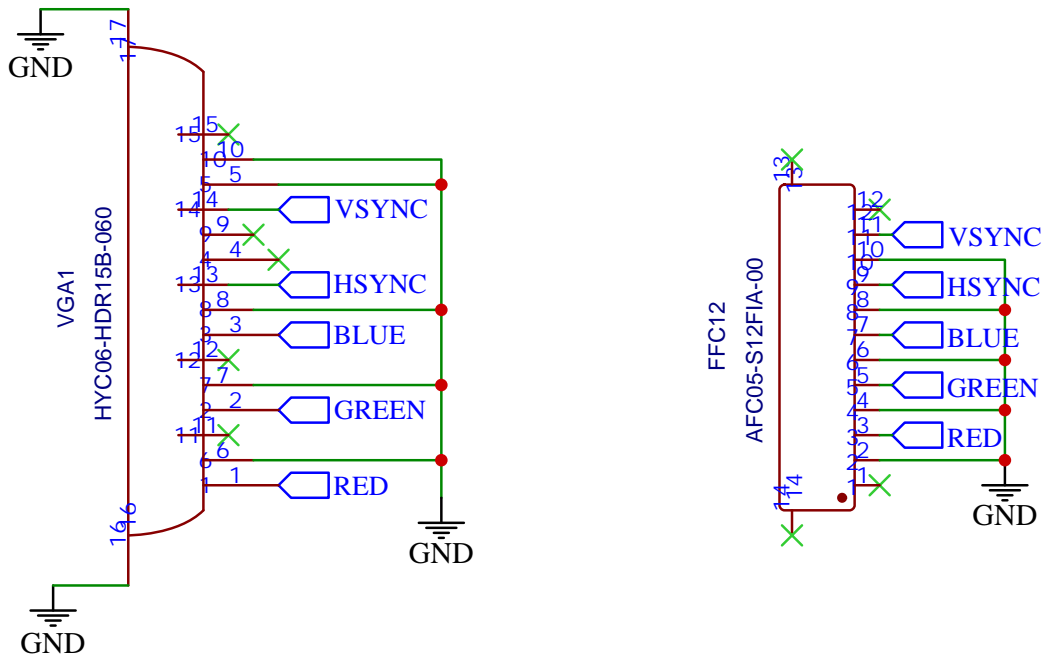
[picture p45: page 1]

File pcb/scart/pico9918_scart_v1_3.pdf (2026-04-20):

## DETECT

## SCART (SEGA 10PIN)

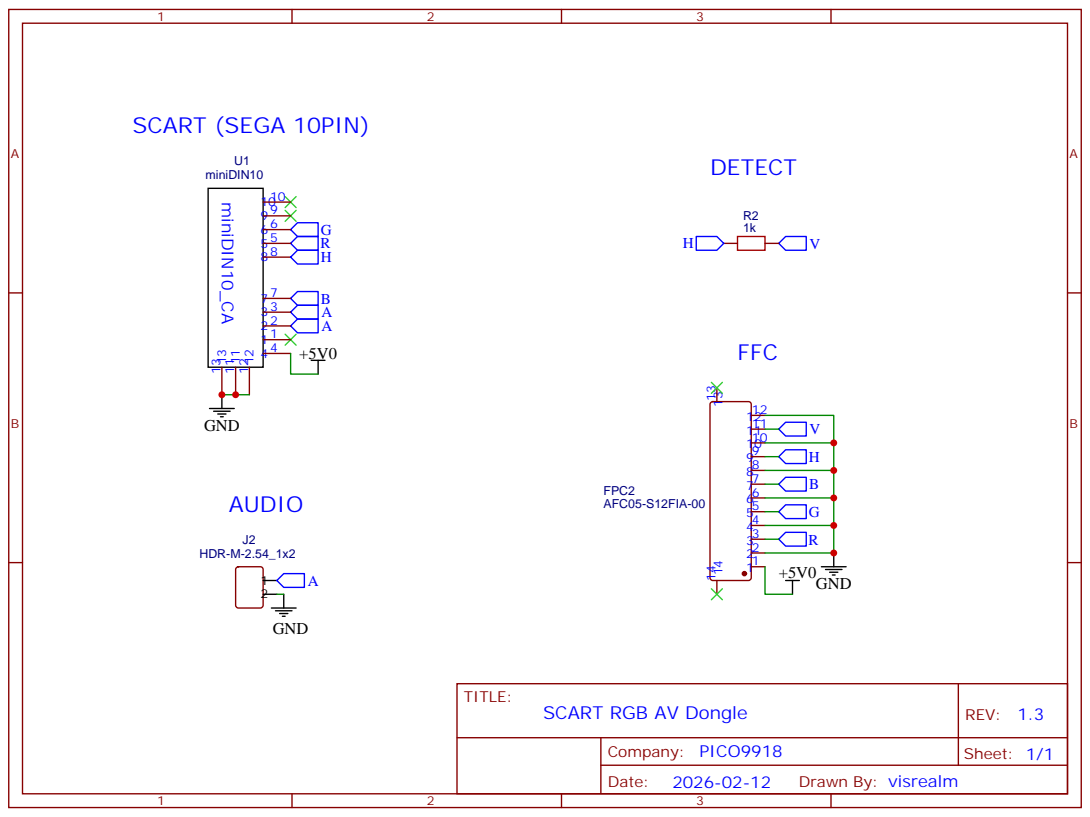
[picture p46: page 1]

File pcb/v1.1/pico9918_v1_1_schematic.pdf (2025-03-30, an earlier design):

# FLASH

RP2040

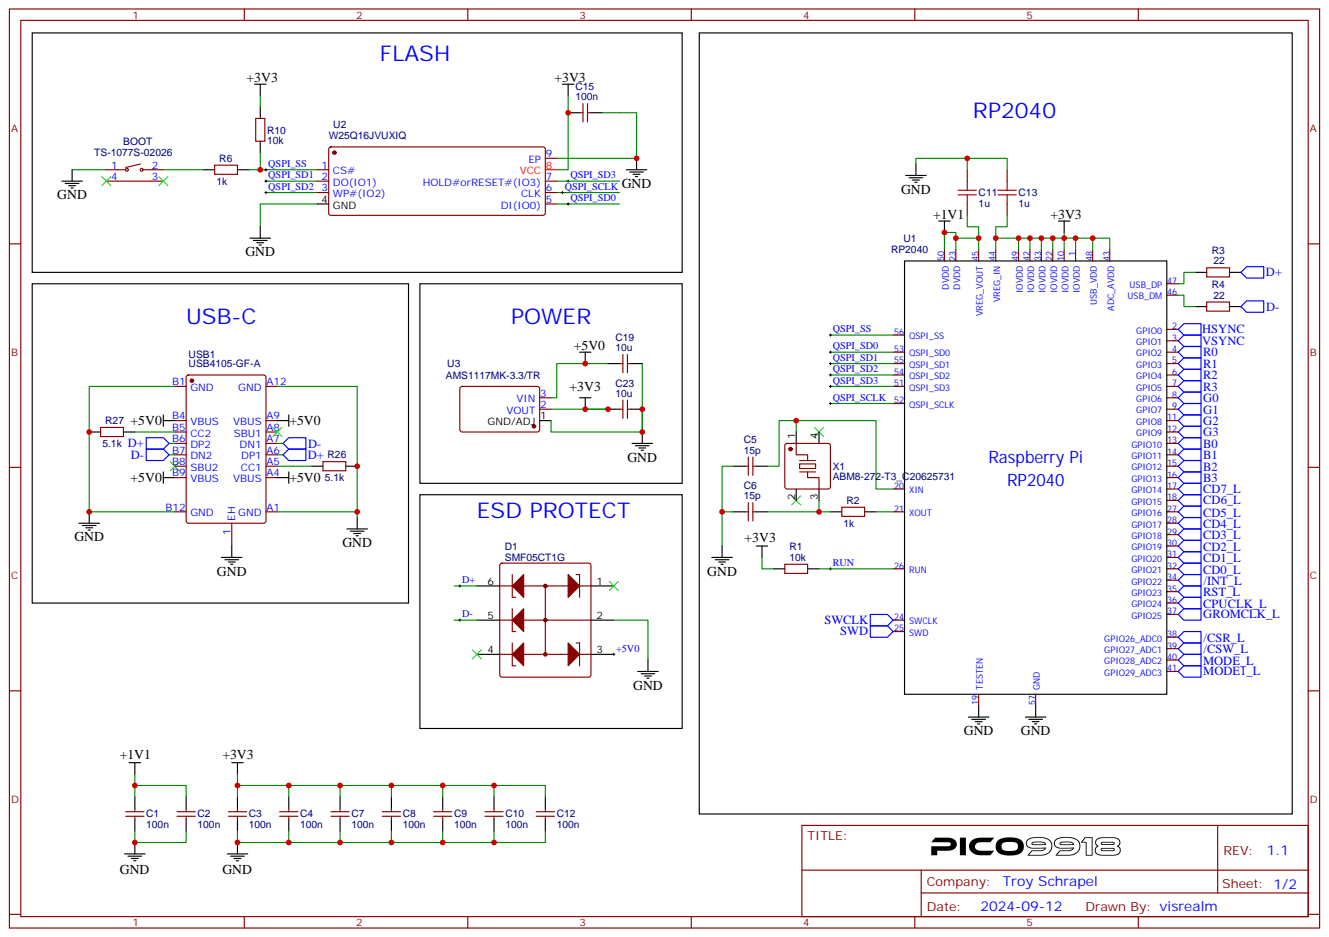
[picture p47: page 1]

# I/O (DATA) TMS9918A INTERFACE

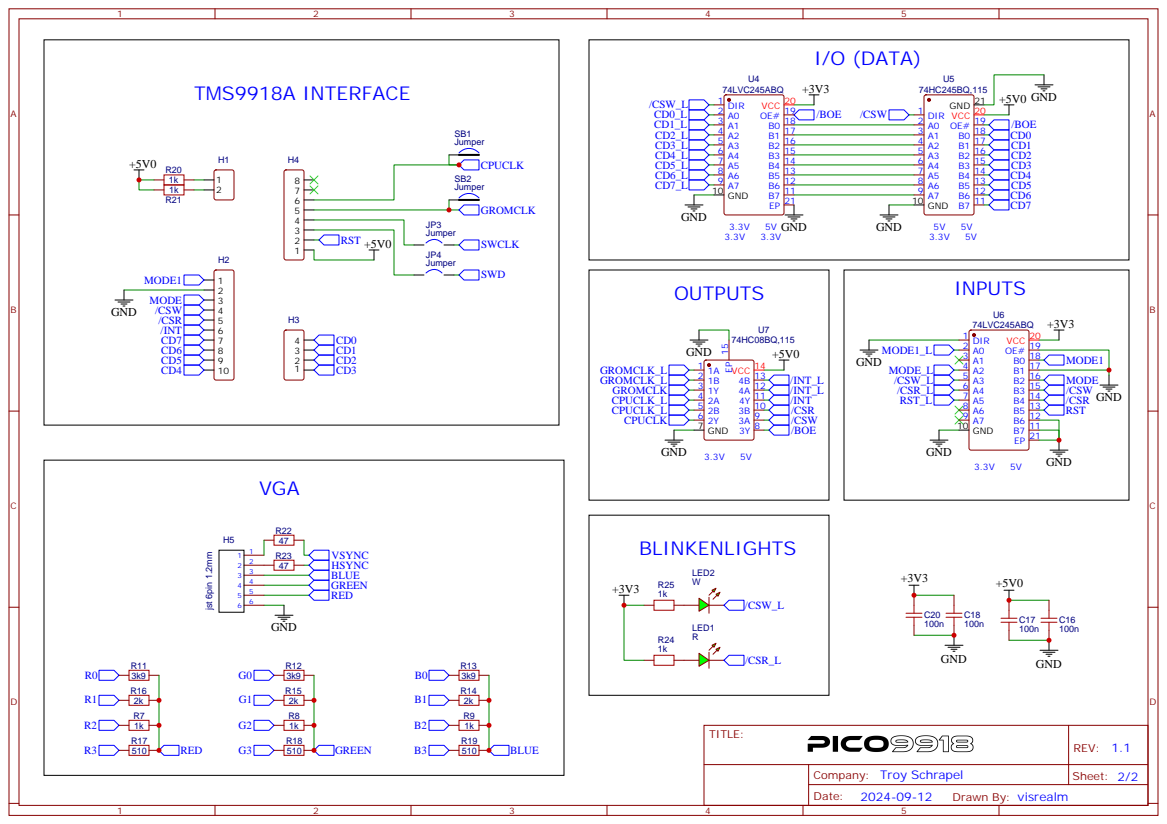
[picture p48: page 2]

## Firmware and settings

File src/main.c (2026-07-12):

/*
 * Project: pico9918
 *
 * Copyright (c) 2024 Troy Schrapel
 *
 * This code is licensed under the MIT license
 *
 * https://github.com/visrealm/pico9918
 *
 */

#include <stdio.h>
#include "vga.h"
#include "vga-modes.h"

#ifndef PICO9918_NO_CLOCKS
#include "clocks.pio.h"
#endif

#define PALCONV 0

#if PALCONV
#include "palconv.pio.h"
#endif


#include "impl/vrEmuTms9918Priv.h"
#include "vrEmuTms9918Util.h"

#include "display.h"
#include "diag.h"
#include "gpio.h"
#include "gpu.h"
#include "config.h"
#include "splash.h"
#include "temperature.h"

#include "pico/stdlib.h"
#include "pico/multicore.h"

#include "hardware/dma.h"
#include "hardware/clocks.h"
#include "hardware/vreg.h"



#define TMS_CRYSTAL_FREQ_HZ  10738635.0f
#define TMS_GROMCLK_FREQ_HZ  (TMS_CRYSTAL_FREQ_HZ / 24.0f)  // ~447 kHz
#define TMS_CPUCLK_FREQ_HZ   (TMS_CRYSTAL_FREQ_HZ / 3.0f)   // ~3.58 MHz
#define TMS_CLK_OFF           0.0f                            // pull low

#define TMS_PIO pio1
#define CLOCK_PIO pio1

#define TMS_WRITE_IRQ PIO1_IRQ_0
#define TMS_READ_IRQ PIO1_IRQ_1

/* file globals */

static uint8_t nextValue = 0;     /* TMS9918A read-ahead value */
static bool currentInt = false;   /* current interrupt state */
static uint8_t currentStatus = 0x1f; /* current status register value */

static char collisionDebugStr[32] = "";  /* debug: last collision info */

static __attribute__((section(".scratch_y.buffer"))) uint32_t bg; 

static __attribute__((section(".scratch_x.buffer"))) uint8_t __aligned(4) tmsScanlineBuffer[TMS9918_PIXELS_X + 8];

const uint tmsWriteSm = 0;
const uint tmsReadSm = 1;
#ifndef PICO9918_NO_CLOCKS
const uint tmsGromClkSm = 2;
const uint tmsCpuClkSm = 3;
#endif

#if PALCONV
#define PAL_PIO         pio0  // which pio are we using for vga?
const uint palconvSm = 2;
static const uint32_t dmapalOut = 5; // palette dma
static const uint32_t dmapalIn  = 6; // palette dma
#endif

#define SHOW_DIAGNOSTICS_FRAMES 900

static int frameCount = 0;
#if PICO9918_GPU_FRAME_COUNTER
uint32_t gpuFrameCount = 0;
#endif
static bool validWrites = false;  // has the VDP display been enabled at all?
static bool doneInt = false;      // interrupt raised this frame?

static int vPixels = 192;         // active TMS display lines (updated each frame)
static uint32_t vBorder = 0;      // top border offset in VGA lines (updated each frame)

static bool droppedFrames[16] = {0};
int droppedFramesCount = 0;

#define R0_DOUBLE_ROWS 0x08

static const uint32_t dma32 = 2;  // memset 32bit

/*
 * drive the /INT pin to match currentInt. Default is active-low; define
 * PICO9918_INT_ACTIVE_HIGH (via pico9918_config.cmake) to drive active-high.
 * Compile-time only - no runtime branch in the hot path.
 */
static inline void setIntPin()
{
#ifdef PICO9918_INT_ACTIVE_HIGH
  gpio_put(GPIO_INT, currentInt);
#else
  gpio_put(GPIO_INT, !currentInt);
#endif
}

/*
 * update the value send to the read PIO
 */
static void updateTmsReadAhead()
{
  uint32_t readAhead = 0xff;              // pin direction
  readAhead |= nextValue << 8;
  if (tms9918->isUnlocked)
  {
    int vr = TMS_REGISTER(tms9918, 0x0F) & 0x0F;
    readAhead |= (TMS_STATUS(tms9918, vr)) << 16;
    readAhead |= vr << 24;
  }
  else
  {
    readAhead |= (TMS_STATUS(tms9918, 0)) << 16;
  }
  pio_sm_put(TMS_PIO, tmsReadSm, readAhead);
}

/*
 * handle read interrupts from the TMS9918<->CPU interface
 */
void __not_in_flash_func(tmsReadIrqHandler)()
{
  uint32_t readVal = TMS_PIO->rxf[tmsReadSm];

  if ((readVal & 0x01) == 0) // read data
  {
    nextValue = vrEmuTms9918ReadAheadDataImpl();
  }
  else // read status
  {
    readVal >>= (1 + 16);        // Extract status that was actually read
    int readReg = (readVal >> 8); // What status register was read?
    tms9918->regWriteStage = 0;
    
    // Standard mode or F18A status register 0
    if (!tms9918->isUnlocked || readReg == 0)
    {
      readVal &= (STATUS_INT | STATUS_5S | STATUS_COL);
      currentStatus &= ~readVal; // Clear only the flags that were set
      if (readVal & STATUS_5S)   // Was 5th Sprite flag set?
        currentStatus |= 0x1f;   // Set sprite number to 31
      vrEmuTms9918SetStatusImpl(currentStatus);
      if (readVal & STATUS_INT)  // Was Interrupt flag set?
      {
        currentInt = false;
        setIntPin();
      }
    }
    else if (readReg == 1)
    {
      // F18A status register 1
      if (readVal & 0x01)
        TMS_STATUS(tms9918, 0x01) &= ~0x01;
    }
  }

  updateTmsReadAhead();
}

/*
 * handle write interrupts from the TMS9918<->CPU interface
 */
void __not_in_flash_func(tmsWriteIrqHandler)()
{
  uint32_t writeVal = TMS_PIO->rxf[tmsWriteSm];
  uint8_t dataVal = writeVal & 0xff;
  writeVal >>= ((GPIO_MODE - GPIO_CD7) + 16);

  if (writeVal & 0x01) // write reg/addr
  {
    vrEmuTms9918WriteAddrImpl(dataVal);
    
    bool newInt = vrEmuTms9918InterruptStatusImpl();
    if (newInt != currentInt)
    {
      currentInt = newInt;
      setIntPin();
    }
  }
  else // write data
  {
    vrEmuTms9918WriteDataImpl(dataVal);
  }

  nextValue = vrEmuTms9918ReadDataNoIncImpl();
  updateTmsReadAhead();
}


/*
 * enable gpio interrupts inline
 */
static inline void enableTmsPioInterrupts()
{
  __dmb();
  irq_set_enabled(TMS_WRITE_IRQ, true);
  irq_set_enabled(TMS_READ_IRQ, true);
}

/*
 * disable gpio interrupts inline
 */
static inline void disableTmsPioInterrupts()
{
  irq_set_enabled(TMS_WRITE_IRQ, false);
  irq_set_enabled(TMS_READ_IRQ, false);
  __dmb();
}

/*
 * handle reset pin going active (low)
 */
void __not_in_flash_func(gpioIrqHandler)()
{
  gpio_acknowledge_irq(GPIO_RESET, GPIO_IRQ_EDGE_FALL);

  disableTmsPioInterrupts();

  vrEmuTms9918Reset();  // resets palette to factory

  readConfig(tms9918->config);  // re-load config palette

  irq_clear(TMS_WRITE_IRQ);
  irq_clear(TMS_READ_IRQ);
  pio_sm_clear_fifos(TMS_PIO, tmsReadSm);
  pio_sm_clear_fifos(TMS_PIO, tmsWriteSm);

  nextValue = 0;
  currentStatus = 0x1f;
  vrEmuTms9918SetStatusImpl(currentStatus);
  currentInt = false;
  doneInt = true;
  updateTmsReadAhead();  
  
  frameCount = 0;
#if PICO9918_GPU_FRAME_COUNTER
  gpuFrameCount = 0;
#endif
  resetSplash();
  setIntPin();
  enableTmsPioInterrupts();
}

typedef struct
{
  int pll;
  int pllDiv1;
  int pllDiv2;
  int voltage;
  int clockHz;
} ClockSettings;

#define CLOCK_PRESET(PLL,PD1,PD2,VOL) {PLL, PD1, PD2, VOL, PLL / PD1 / PD2}

#if PICO9918_ENABLE_SCART
// SCART: clocks must be multiples of 54 MHz for exact integer pioClocksPerPixel
// (pioFreq must be a multiple of 13.5 MHz, minimum 54 MHz)
// 270/5=54MHz(4), 324/6=54MHz(4) clocks per pixel
static const ClockSettings scartClockPresets[] = {
  CLOCK_PRESET(1080000000, 4, 1, VREG_VOLTAGE_1_15),    // 270 MHz
  CLOCK_PRESET(1296000000, 4, 1, VREG_VOLTAGE_1_20),    // 324 MHz
  CLOCK_PRESET(1296000000, 4, 1, VREG_VOLTAGE_1_20)     // 324 MHz (no safe higher option)
};
#endif

// VGA: clocks for 25.175 MHz pixel clock
static const ClockSettings vgaClockPresets[] = {
  CLOCK_PRESET(1512000000, 6, 1, VREG_VOLTAGE_1_15),    // 252 MHz
  CLOCK_PRESET(1512000000, 5, 1, VREG_VOLTAGE_1_20),    // 302.4 MHz
  CLOCK_PRESET(1056000000, 3, 1, VREG_VOLTAGE_1_30)     // 352 MHz
};

static const ClockSettings *clockPresets = vgaClockPresets;

static int clockPresetIndex = 0;

typedef struct
{
  float pin37freq;  // GROMCLK pin frequency, 0 = pull low
  float pin38freq;  // CPUCLK pin frequency, 0 = pull low
} VdpClockConfig;

static const VdpClockConfig vdpClockConfigs[] = {
  { TMS_GROMCLK_FREQ_HZ, TMS_CPUCLK_FREQ_HZ },  // VDP_TMS9918A: GROMCLK + CPUCLK
  { TMS_GROMCLK_FREQ_HZ, TMS_CLK_OFF         },  // VDP_TMS992xA: GROMCLK only
  { TMS_CLK_OFF,          TMS_CPUCLK_FREQ_HZ },  // VDP_TMS9118:  CPUCLK only
  { TMS_CPUCLK_FREQ_HZ,  TMS_CLK_OFF         },  // VDP_TMS912x:  CPUCLK freq on pin 37
};

static void eofInterrupt()
{
  doneInt = true;
  TMS_STATUS(tms9918, 0x01) |=  0x02;
  if (TMS_REGISTER(tms9918, 0x32) & 0x20)
  {
    gpuTrigger();
  }

  if (tms9918->configDirty)
  {
    tms9918->configDirty = false;
    applyConfig();  // apply config option to device now
    diagnosticsConfigUpdated();
  }
}

static void updateInterrupts(uint8_t tempStatus)
{
  disableTmsPioInterrupts();
  if ((currentStatus & STATUS_INT) == 0)
  {
    if (currentStatus & STATUS_5S)
    {
      // 5S already latched - preserve existing ID, OR in any new flags (INT, 5S, COL)
      currentStatus |= (tempStatus & 0xe0);
    }
    else
    {
      currentStatus = (currentStatus & 0xe0) | tempStatus;
    }
  }
  else
  {
    // F is set - only allow COL through (per F18A/TMS9918A: COL is not gated by F)
    // 5S is blocked while F is set (per datasheet)
    currentStatus |= (tempStatus & STATUS_COL);
  }

  vrEmuTms9918SetStatusImpl(currentStatus);
  updateTmsReadAhead();

  // Ensure interrupt pin state is correct
  // (in case R1 was modified to enable/disable interrupts)
  bool shouldInt = vrEmuTms9918InterruptStatusImpl();
  if (shouldInt != currentInt)
  {
    currentInt = shouldInt;
    setIntPin();
  }
  enableTmsPioInterrupts();
}


/* F18A palette entries are big-endian 0x0RGB which looks like
   0xGB0R to our RP2040. our vga code is expecting 0x0BGR
   so we've got B and R correct by pure chance. just need to shift G
   over. this function does that.   */

inline uint32_t bigRgb2LittleBgr(uint32_t val)
{
  val &= 0xff0f;
  return val | ((val >> 12) << 4);
}


#ifndef PICO9918_NO_CLOCKS
void updateClock(uint pioSm, float freqHz)
{
  float clockDiv = ((float)clockPresets[clockPresetIndex].clockHz) / (freqHz * 2.0f);
  pio_sm_set_clkdiv(CLOCK_PIO, pioSm, clockDiv);
  pio_sm_set_enabled(CLOCK_PIO, pioSm, true);
  diagSetClockHz(clockPresets[clockPresetIndex].clockHz);
}

/*
 * initialise a clock output using PIO, or pull pin low if freq is 0
 */
static void initClockOrPullLow(uint gpio, uint pioSm, float freqHz);

/*
 * initialise a clock output using PIO
 */
void initClock(uint gpio, uint pioSm, float freqHz)
{
  static uint clocksPioOffset = -1;

  if (clocksPioOffset == -1)
  {
    clocksPioOffset = pio_add_program(CLOCK_PIO, &clock_program);
  }

  pio_gpio_init(CLOCK_PIO, gpio);
  pio_sm_set_consecutive_pindirs(CLOCK_PIO, pioSm, gpio, 1, true);
  pio_sm_config c = clock_program_get_default_config(clocksPioOffset);
  sm_config_set_set_pins(&c, gpio, 1);

  pio_sm_init(CLOCK_PIO, pioSm, clocksPioOffset, &c);

  updateClock(pioSm, freqHz);
}

static void initClockOrPullLow(uint gpio, uint pioSm, float freqHz)
{
  if (freqHz > 0.0f)
  {
    initClock(gpio, pioSm, freqHz);
  }
  else
  {
    gpio_init(gpio);
    gpio_set_dir(gpio, GPIO_OUT);
    gpio_put(gpio, 0);
  }
}
#endif // PICO9918_NO_CLOCKS

static void tmsPorch()
{
  tms9918->vram.map.blanking = 1; // V
  tms9918->vram.map.scanline = 255; // F18A value for vsync
  TMS_STATUS(tms9918, 0x03) = 255;
}

static void tmsEndOfScanline(uint32_t displayLine)
{
  if (!doneInt)
  {
    bool droppedFrame = currentStatus & STATUS_INT;
    droppedFramesCount += droppedFrame - droppedFrames[frameCount & 0xf];
    droppedFrames[frameCount & 0xf] = droppedFrame;

    eofInterrupt();
    updateInterrupts(STATUS_INT);
  }
}

static void tmsEndOfFrame(uint32_t frameNumber)
{
  ++frameCount;
#if PICO9918_GPU_FRAME_COUNTER
  gpuFrameCount += (TMS_STATUS(tms9918, 2) & 0x80) != 0;
#endif
  
{
    static float tempC = 0.0f;
    tempC += coreTemperatureC();
    if ((frameCount & 0x3f) == 0) // every 64th frame
    {
      tempC /= 64.0f;
      diagSetTemperature(tempC);
      uint8_t t4 = (uint8_t)(tempC * 4.0f + 0.5f);
      TMS_STATUS(tms9918, 13) = t4;
      tempC = 0.0f;
    }
  }

  if (!validWrites)
  {
    // has the display been enabled?
    if (validWrites = (TMS_REGISTER(tms9918, 1) & 0x40))
    {
      allowSplashHide();
      if (frameCount > SHOW_DIAGNOSTICS_FRAMES)
      {
        // reset diganostics and other settings back to defaults
        readConfig(tms9918->config);
      }
    }
  }

  if (tms9918->config[CONF_DIAG])
    updateDiagnostics(frameCount);


  // here, we catch the case where the last row(s) were
  // missed and we never raised an interrupt. do it now  
  if (!doneInt)
  {
    eofInterrupt();
    updateInterrupts(STATUS_INT);
  }

#if PICO9918_ENABLE_SCART
  const int yScale = vgaCurrentParams()->params.interlaced ? 1 : 2;
#else
  const int yScale = DISPLAY_YSCALE;
#endif

  if (yScale > 1) {
    bool doubleRows = TMS_REGISTER(tms9918, 0) & R0_DOUBLE_ROWS;
    vgaCurrentParams()->params.vPixelScale = yScale - (bool)doubleRows;
    vgaCurrentParams()->params.vVirtualPixels = (vgaCurrentParams()->params.vSyncParams.displayPixels / yScale) << (bool)doubleRows;
  }

  int baseRows = (TMS_REGISTER(tms9918, 0x31) & 0x40) ? 30 : 24;
  vPixels = baseRows << 3;
  if (yScale > 1 && (TMS_REGISTER(tms9918, 0) & R0_DOUBLE_ROWS))
    vPixels <<= 1;
  vBorder = (vgaCurrentParams()->params.vVirtualPixels - vPixels) / 2;
  vgaSetTriggerScanline(vBorder + vPixels);
}


void renderDiag(int y, uint16_t *pixels)
{
  if (tms9918->config[CONF_DIAG])
  {
    dma_channel_wait_for_finish_blocking(dma32);
    renderDiagnostics(y, pixels);
  }
}

/*
 * cache color lookup from color index to BGR16
 */
uint32_t __aligned(4) pram [256];


static __attribute__((noinline))  void generateRgbCache()
{
  /* convert from  palette to bgr12 */
  uint32_t data;
  tms9918->palDirty = 0;

#if PALCONV
  dma_channel_set_read_addr(dmapalOut, tms9918->vram.map.pram, true);
  dma_channel_set_write_addr(dmapalIn, pram, true);
#else
  const bool pixelsDoubled = vrEmuTms9918DisplayMode(tms9918) != TMS_MODE_TEXT80;
  if (pixelsDoubled)
  {
    for (int i = 0; i < 64; i += 8)
    {
      data = tms9918->vram.map.pram [i + 0] & 0xFF0F; data = data | ((data >> 12) << 4); pram [i + 0] = data * 0x10001;
      data = tms9918->vram.map.pram [i + 1] & 0xFF0F; data = data | ((data >> 12) << 4); pram [i + 1] = data * 0x10001;
      data = tms9918->vram.map.pram [i + 2] & 0xFF0F; data = data | ((data >> 12) << 4); pram [i + 2] = data * 0x10001;
      data = tms9918->vram.map.pram [i + 3] & 0xFF0F; data = data | ((data >> 12) << 4); pram [i + 3] = data * 0x10001;
      data = tms9918->vram.map.pram [i + 4] & 0xFF0F; data = data | ((data >> 12) << 4); pram [i + 4] = data * 0x10001;
      data = tms9918->vram.map.pram [i + 5] & 0xFF0F; data = data | ((data >> 12) << 4); pram [i + 5] = data * 0x10001;
      data = tms9918->vram.map.pram [i + 6] & 0xFF0F; data = data | ((data >> 12) << 4); pram [i + 6] = data * 0x10001;
      data = tms9918->vram.map.pram [i + 7] & 0xFF0F; data = data | ((data >> 12) << 4); pram [i + 7] = data * 0x10001;
    }
  }
  else // 80-col mode doesn't have doubled pixels
  {
    uint16_t tmpPal[16];
    for (int i = 0; i < 16; ++i)
    {
      data = tms9918->vram.map.pram [i] & 0xFF0F;
      tmpPal[i] = data | ((data >> 12) << 4);
      pram[i] = tmpPal[i] * 0x10001;
    }
    for (int j = 16; j < 256; ++j)
    {
      pram[j] = (tmpPal[j & 0xf] << 16) | (tmpPal[j >> 4] & 0xffff);
    }
  }
#endif
}
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
int main(void)
{
  /* currently, VGA hard-coded to 640x480@60Hz. We want a high clock frequency
   * that comes close to being divisible by 25.175MHz. 252.0 is close... enough :)
   * I do have code which sets the best clock baased on the chosen VGA mode,
   * but this'll do for now. */


  // set up gpio pins. keep /INT asserted for now: active-low => low (0),
  // active-high => high (mask set).
#ifdef PICO9918_INT_ACTIVE_HIGH
  gpio_put_all(GPIO_INT_MASK);
#else
  gpio_put_all(0);
#endif
  gpio_set_dir_all_bits(GPIO_INT_MASK); // /INT is an output
  gpio_set_function_masked(GPIO_CD_MASK | GPIO_CSR_MASK | GPIO_CSW_MASK | GPIO_MODE_MASK | GPIO_MODE1_MASK | GPIO_INT_MASK | GPIO_RESET_MASK, GPIO_FUNC_SIO);

  // detect on core 0 before core 1 is launched (proc1 also reads it)
  (void)currentHwVersion();

  // shouldUseScartClock() peeks flash for a user-forced SCART preference
  detectScartDongle();

#if PICO9918_ENABLE_SCART
  if (shouldUseScartClock())
    clockPresets = scartClockPresets;
#endif

  /* the initial "safe" clock speed */
  ClockSettings clockSettings = clockPresets[clockPresetIndex];
  vreg_set_voltage(clockSettings.voltage);
  sleep_ms(1);
  set_sys_clock_pll(clockSettings.pll, clockSettings.pllDiv1, clockSettings.pllDiv2);

  /* we need one of these. it's the main guy */
  vrEmuTms9918Init();

  /* launch core 1 which handles TMS9918<->CPU and rendering scanlines */
  multicore_launch_core1(proc1Entry);

  /* we could set clock freq here from options */
  readConfig(tms9918->config);

  applyPendingDisplay(tms9918->config);

  updateDispDriver();

  if (tms9918->config[CONF_CLOCK_PRESET_ID] != clockPresetIndex)
  {
    clockPresetIndex = tms9918->config[CONF_CLOCK_PRESET_ID];
    clockSettings = clockPresets[clockPresetIndex];

    vreg_set_voltage(clockSettings.voltage);
    sleep_ms(1);
    set_sys_clock_pll(clockSettings.pll, clockSettings.pllDiv1, clockSettings.pllDiv2);
  }

#ifndef PICO9918_NO_CLOCKS
  // set up the GROMCLK and CPUCLK outputs (frequencies depend on the VDP device)
  Pico9918HardwareVersion hwVersion = currentHwVersion();
  uint8_t vdpDevice = tms9918->config[CONF_VDP_DEVICE];
  const VdpClockConfig *clkCfg = &vdpClockConfigs[vdpDevice];

  uint gromClkGpio = (hwVersion == HWVer_0_3) ? GPIO_GROMCL_V03 : GPIO_GROMCL;
  uint cpuClkGpio  = (hwVersion == HWVer_0_3) ? GPIO_CPUCL_V03  : GPIO_CPUCL;

  initClockOrPullLow(gromClkGpio, tmsGromClkSm, clkCfg->pin37freq);
  initClockOrPullLow(cpuClkGpio, tmsCpuClkSm, clkCfg->pin38freq);
#endif

  dma_channel_config cfg = dma_channel_get_default_config(dma32);
  channel_config_set_read_increment(&cfg, false);
  channel_config_set_write_increment(&cfg, true);
  channel_config_set_transfer_data_size(&cfg, DMA_SIZE_32);
  dma_channel_set_config(dma32, &cfg, false);
  dma_channel_set_read_addr(dma32, &bg, false);

#if PALCONV
  uint palConvProgram = pio_add_program(PAL_PIO, &palconv_program);

  pio_sm_config palconvPioConfig = palconv_program_get_default_config(palConvProgram);

  sm_config_set_in_shift(&palconvPioConfig, false, true, 24);  // L shift
  sm_config_set_out_shift(&palconvPioConfig, true, false, 12);  // R shift
  pio_sm_init(PAL_PIO, palconvSm, palConvProgram, &palconvPioConfig);

  cfg = dma_channel_get_default_config(dmapalOut);
  channel_config_set_read_increment(&cfg, true);
  channel_config_set_write_increment(&cfg, false);
  channel_config_set_transfer_data_size(&cfg, DMA_SIZE_16);
  channel_config_set_dreq(&cfg, pio_get_dreq(PAL_PIO, palconvSm, true)); 
  dma_channel_set_read_addr(dmapalOut, tms9918->vram.map.pram, false);
  dma_channel_set_write_addr(dmapalOut, &PAL_PIO->txf[palconvSm], false);
  dma_channel_set_trans_count(dmapalOut, 64, false);
  dma_channel_set_config(dmapalOut, &cfg, false);

  cfg = dma_channel_get_default_config(dmapalIn);
  channel_config_set_read_increment(&cfg, false);
  channel_config_set_write_increment(&cfg, true);
  channel_config_set_transfer_data_size(&cfg, DMA_SIZE_32);
  channel_config_set_dreq(&cfg, pio_get_dreq(PAL_PIO, palconvSm, false)); 

  dma_channel_set_read_addr(dmapalIn, &PAL_PIO->rxf[palconvSm], false);
  dma_channel_set_write_addr(dmapalIn, pram, false);
  dma_channel_set_trans_count(dmapalIn, 64, false);
  dma_channel_set_config(dmapalIn, &cfg, false);

  pio_sm_set_enabled(PAL_PIO, palconvSm, true); 
#endif

  tms9918->palDirty = 1;

  /* then set up VGA output */
  VgaInitParams params = { 0 };
#if PICO9918_ENABLE_SCART
  // CONF_DISP_DRIVER: 0=VGA, 1=NTSC, 2=PAL (resolved by updateDispDriver)
  if (tms9918->config[CONF_DISP_DRIVER] == 0)
  {
    params.params = vgaGetParams(VGA_640_480_60HZ);
  }
  else
  {
    params.params = vgaGetParams(tms9918->config[CONF_SCART_MODE]
      ? RGBS_NTSC_720_480i_60HZ : RGBS_PAL_720_576i_50HZ);
  }
#else
  params.params = vgaGetParams(DISPLAY_MODE);
#endif
  /* set vga scanline callback to generate tms9918 scanlines */
  params.scanlineFn = tmsScanline;
  params.endOfFrameFn = tmsEndOfFrame;
  params.endOfScanlineFn = tmsEndOfScanline;
  params.porchFn = tmsPorch;
  params.triggerScanline = UINT32_MAX;  // will be set dynamically once vBorder/vPixels are known

  const char *version = PICO9918_VERSION;

  vgaInit(params);

  initTemperature();

  initDiagnostics();

  /* signal proc1 that we're ready to start the display */
  multicore_fifo_push_blocking(0);

  /* initialize the GPU */
  gpuInit();

  /* pass control of core0 over to the TMS9900 GPU */
  gpuLoop();

  return 0;
}

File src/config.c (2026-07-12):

/*
 * Project: pico9918
 *
 * Copyright (c) 2024 Troy Schrapel
 *
 * This code is licensed under the MIT license
 *
 * https://github.com/visrealm/pico9918
 *
 */

#include "impl/vrEmuTms9918Priv.h"

#include "gpio.h"
#include "vga.h"
#include "config.h"

#include "hardware/flash.h"
#include "hardware/gpio.h"

#include "pico/time.h"

#include <string.h>

#if PICO_RP2040
  #define PICO_MODEL 1
#elif PICO_RP2350
  #define PICO_MODEL 2
#endif

static Pico9918HardwareVersion hwVersion = HWVer_1_x;
static bool hwVersionDetected = false;

/*
 * detect the hardware version (v0.3 vs v0.4+)
 */
static Pico9918HardwareVersion detectHardwareVersion()
{
  Pico9918HardwareVersion version = HWVer_1_x;

#if PICO_RP2350
  version = HWVer_2_x;
#elif PICO_RP2040
  // check if RESET pin is being driven externally (on v0.4+, it is, on v0.3 it isn't since it's CPUCL)
  gpio_pull_down(GPIO_RESET);
  sleep_ms(1);
  if (!gpio_get(GPIO_RESET)) // following pull... ok
  {
    gpio_pull_up(GPIO_RESET);
    sleep_ms(1);
    if (gpio_get(GPIO_RESET)) // still following pull... must be v0.3
    {
      version = HWVer_0_3;
    }
  }
#endif

  return version;
}

/*
 * current (detected) hardware version. detects (with a one-time GPIO_RESET
 * side effect) on first call and caches the result.
 */
Pico9918HardwareVersion currentHwVersion()
{
  if (!hwVersionDetected)
  {
    hwVersion = detectHardwareVersion();
    hwVersionDetected = true;
  }
  return hwVersion;
}

static bool scartConnected = false;

/*
 * detect a SCART dongle by checking if the two sync pins are bridged.
 * The SCART dongle connects hsync (GPIO 0) and vsync (GPIO 1) via 1k resistor.
 * Drive one high, pull-down the other and read it. Must be called before vgaInit().
 */
bool detectScartDongle()
{
#if PICO9918_ENABLE_SCART
  const uint syncMask = 0x03 << VGA_SYNC_PINS_START;  // GPIO 0 and 1
  const uint driveMask = 0x01 << VGA_SYNC_PINS_START; // GPIO 0

  gpio_init_mask(syncMask);
  gpio_set_drive_strength(VGA_SYNC_PINS_START, GPIO_DRIVE_STRENGTH_12MA);
  gpio_set_dir_masked(syncMask, driveMask);  // GPIO 0 output, GPIO 1 input
  gpio_pull_down(VGA_SYNC_PINS_START + 1);

  gpio_set_mask(driveMask);
  sleep_ms(1);
  scartConnected = gpio_get(VGA_SYNC_PINS_START + 1);

  gpio_clr_mask(driveMask);
  gpio_set_drive_strength(VGA_SYNC_PINS_START, GPIO_DRIVE_STRENGTH_4MA);
  gpio_disable_pulls(VGA_SYNC_PINS_START + 1);
  gpio_set_dir_masked(syncMask, 0);  // both inputs
  // PIO will re-claim these pins during vgaInit()
#endif
  return scartConnected;
}

/*
 * true if a SCART dongle was detected at boot
 */
bool isScartConnected()
{
  return scartConnected;
}

/*
 * update CONF_DISP_DRIVER from CONF_DISP_DRIVER_PREF + dongle detection
 *   pref: 0=AUTO, 1=VGA, 2=SCART  ->  driver: 0=VGA, 1=NTSC, 2=PAL
 */
void updateDispDriver()
{
  uint8_t pref = tms9918->config[CONF_DISP_DRIVER_PREF];
  bool useScart = (pref == 2) || (pref == 0 && isScartConnected());
  tms9918->config[CONF_DISP_DRIVER] = useScart
    ? (2 - tms9918->config[CONF_SCART_MODE]) : 0;
}

/*
 * apply current configuration to the VDP
 */
void applyConfig()
{
  vgaCurrentParams()->scanlines = tms9918->config[CONF_CRT_SCANLINES];

  if (tms9918->config[CONF_CRT_SCANLINES])
    TMS_REGISTER(tms9918, 50) |= 0x04;
  else
    TMS_REGISTER(tms9918, 50) &= ~0x04;

  TMS_REGISTER(tms9918, 30) = 1 << (tms9918->config[CONF_SCANLINE_SPRITES] + 2);

  // apply default palette
  for (int i = 0; i < 16; ++i)
  {
    uint16_t rgb = (tms9918->config[CONF_PALETTE_IDX_0 + (i * 2)] << 8) |
                    tms9918->config[CONF_PALETTE_IDX_0 + (i * 2) + 1];
    tms9918->vram.map.pram[i] = __builtin_bswap16(rgb);
  }
  
  tms9918->config[CONF_DIAG] = tms9918->config[CONF_DIAG_ADDRESS] ||
                               tms9918->config[CONF_DIAG_PALETTE] ||
                               tms9918->config[CONF_DIAG_PERFORMANCE] ||
                               tms9918->config[CONF_DIAG_REGISTERS];
}

#define CONFIG_FLASH_OFFSET  (0x200000 - 0x1000) // in the top 4kB of a 2MB flash
#define CONFIG_FLASH_ADDR    (uint8_t*)(XIP_BASE + CONFIG_FLASH_OFFSET)

// 4 KB sector immediately below the main config block
#define PENDING_FLASH_OFFSET (CONFIG_FLASH_OFFSET - 0x1000)
#define PENDING_FLASH_ADDR   (uint8_t*)(XIP_BASE + PENDING_FLASH_OFFSET)

static uint8_t pendingBannerState = PENDING_BANNER_NONE;
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

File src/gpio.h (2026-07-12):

/*
 * Project: pico9918
 *
 * Copyright (c) 2024 Troy Schrapel
 *
 * This code is licensed under the MIT license
 *
 * https://github.com/visrealm/pico9918
 *
 */

#pragma once

 /*
  * Pin mapping
  *
  * Pico Pin  | GPIO (v0.3) | GPIO (v0.4+) | Name      | TMS9918A Pin
  * ----------+-------------+--------------+-----------+-------------
  *     19    |     14      |     14       |  CD7      |  24
  *     20    |     15      |     15       |  CD6      |  23
  *     21    |     16      |     16       |  CD5      |  22
  *     22    |     17      |     17       |  CD4      |  21
  *     24    |     18      |     18       |  CD3      |  20
  *     25    |     19      |     19       |  CD2      |  19
  *     26    |     20      |     20       |  CD1      |  18
  *     27    |     21      |     21       |  CD0      |  17
  *     29    |     22      |     22       |  /INT     |  16
  *     30    |     RUN     |     23       |  RST      |  34
  *     31    |     26      |     26       |  /CSR     |  15
  *     32    |     27      |     27       |  /CSW     |  14
  *     34    |     28      |     28       |  MODE     |  13
  *     --    |     --      |     29       |  MODE 1   |  --
  *     35    |     29      |     25       |  GROMCLK  |  37
  *     37    |     23      |     24       |  CPUCLK   |  38
  *
  *
  * Note: Due to GROMCLK and CPUCLK using GPIO23 and GPIO29
  *       a genuine Raspberry Pi Pico can't be used.
  *       v0.3 of the PCB is designed for the DWEII?
  *       RP2040 USB-C module which exposes these additional
  *       GPIOs. A future pico9918 revision (v0.4+) will do without
  *       an external RP2040 board and use the RP2040 directly.
  * 
  * Note: Hardware v0.3 has different GPIO mappings for GROMCL and CPUCL
  *       Hardware v0.3 doesn't have a soft reset GPIO either
  * 
  * Purchase links for v0.3 Pi Pico module:
  *       https://www.amazon.com/RP2040-Board-Type-C-Raspberry-Micropython/dp/B0CG9BY48X
  *       https://www.aliexpress.com/item/1005007066733934.html
  */

 #pragma once

 #include "tms9918.pio.h"

// Base pin defaults below may be overridden at build time via the CMake config
// file (pico9918_config.cmake) which passes -DPICO9918_GPIO_* defines.
#ifndef PICO9918_GPIO_CD7
#define PICO9918_GPIO_CD7 14
#endif
#define GPIO_CD7 PICO9918_GPIO_CD7

#define GPIO_CSR tmsRead_CSR_PIN  // defined in tms9918.pio.h
#define GPIO_CSW tmsWrite_CSW_PIN // defined in tms9918.pio.h

#ifndef PICO9918_GPIO_MODE
#define PICO9918_GPIO_MODE 28
#endif
#define GPIO_MODE PICO9918_GPIO_MODE

#ifndef PICO9918_GPIO_MODE1
#define PICO9918_GPIO_MODE1 29
#endif
#define GPIO_MODE1 PICO9918_GPIO_MODE1

#ifndef PICO9918_GPIO_INT
#define PICO9918_GPIO_INT 22
#endif
#define GPIO_INT PICO9918_GPIO_INT

#ifndef PICO9918_GPIO_RESET
#define PICO9918_GPIO_RESET 23
#endif
#define GPIO_RESET PICO9918_GPIO_RESET

// default mappings (v0.4+)
#ifndef PICO9918_GPIO_GROMCL
#define PICO9918_GPIO_GROMCL 25
#endif
#define GPIO_GROMCL PICO9918_GPIO_GROMCL

#ifndef PICO9918_GPIO_CPUCL
#define PICO9918_GPIO_CPUCL 24
#endif
#define GPIO_CPUCL PICO9918_GPIO_CPUCL

// v0.3-specific pins mappings
#ifndef PICO9918_GPIO_GROMCL_V03
#define PICO9918_GPIO_GROMCL_V03 29
#endif
#define GPIO_GROMCL_V03 PICO9918_GPIO_GROMCL_V03

#ifndef PICO9918_GPIO_CPUCL_V03
#define PICO9918_GPIO_CPUCL_V03 23
#endif
#define GPIO_CPUCL_V03 PICO9918_GPIO_CPUCL_V03

// gpio masks
#define GPIO_CD_MASK (0xff << GPIO_CD7)
#define GPIO_CSR_MASK (0x01 << GPIO_CSR)
#define GPIO_CSW_MASK (0x01 << GPIO_CSW)
#define GPIO_MODE_MASK (0x01 << GPIO_MODE)
#define GPIO_MODE1_MASK (0x01 << GPIO_MODE1)
#define GPIO_INT_MASK (0x01 << GPIO_INT)
#define GPIO_RESET_MASK (0x01 << GPIO_RESET)

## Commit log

2024-04-24 Added initial pcb
2024-05-21 more error than trial
    [main.c, test.c, vga.c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]
2024-05-21 it works! just need to implement interrupts and maybe reset
    [main.c, test.c]
2024-05-21 initial interrupts
2024-05-22 testing on real hbc-56 mostly works. perhaps reading is broken?
    [main.c, test.c]
2024-05-23 read works now, but first boot has glitches.
    [main.c, test.c]
2024-06-08 Initial release for v0.2 hardware (with reversed CD0-CD7)
    [bom_v0_3.xlsx]
2024-06-08 Pico module notes
2024-06-08 Removed unused tms9918 code from pico-56
2024-06-21 Fixes for PCB v0.3
    [main.c]
2024-06-23 Fixed interrupt race condition v0.3
    [main.c]
2024-06-24 Fixed potential sync isues
    [main.c]
2024-06-25 Added v0.3 gerber
    [pico9918_v0_3_bom.xlsx, pico9918_v0_3_picknplace.csv]
2024-06-25 PCB v0.3 release
2024-07-11 more binary size reduction, int sync fixes
    [main.c]
2024-07-12 Fixed status/interrupt timing issues
    [main.c, vga.c]
2024-07-12 added pcb version #defines
2024-07-21 Enable write pio interrupt earlier
2024-07-24 vga modes hardcoded virtual pixels multiplier fix
    [main.c]
2024-09-01 Fixed reversed CD0-CD7 in comments, renamed GPIO_CD0 to GPIO_CD7. Issue #12
    [main.c]
2024-09-02 Update README.md
    Added supported devices and purchasing options
2024-09-09 reset interrupt on... reset
    [main.c]
2024-09-10 change when scanline register is updated to fix plasma demo
    [main.c]
2024-09-10 Added NABU to supported devices
2024-09-11 fixed text80 rendering when background was transparent
    [main.c]
2024-09-14 Fixed palette issues related to tms9900 big-endianness vs arm little-endianness
    [main.c]
2024-09-15 Updated supported devices list
2024-09-18 Updated supported devices
2024-09-18 fixed color conversion comment
    [main.c]
2024-09-19 dma for background color. added end of frame callback
2024-09-20 interrupts and 30row bug fixes
    [main.c, vga.c]
2024-09-21 interrupt changes
2024-09-21 fixed 80 column mode
    [main.c, vga.c]
2024-09-22 JasonACT: Added GPU DMA using the RP2040 MPU
2024-09-22 pulled dma task out
2024-09-23 Switch over to new VSCode Raspberry Pi Pico Extension
2024-09-24 added option for frame/scanline timing diagnostics, moved more options to CMakeFiles.txt, output filename based on options, improved 80col render speed, reduced clock freq to 302MHz at stock voltage.
2024-09-29 re-enabled custom board file. higher clock rate, minor fixes
    [main.c, vga.c]
2024-09-30 Jason's interrupt handling improvements
2024-10-06 Jason: Added temperature diagnostics and porch callback fo rscanline number
2024-10-09 Updated to Pico SDK 2.0.0. Added binary info, removed TMS PIO clock divider
2024-10-13 Jason's fixes for scanline number continuing through 215 before jumping to 255 for the remainder of the frame
    [main.c]
2024-10-17 fixes for rp2350 support
    [main.c]
2024-11-03 Added gerbers for pico9918 v0.4, v1.0 and v1.1
    [pico9918_v0_4_bom.csv, pico9918_v1_0_bom.csv, pico9918_v1_1_bom.xls]
2024-11-15 conftool loading current values
2024-11-17 Fixed grom/cpu clocks when higher clock speed used. Fixed register reset and max scanline sprites.
    [main.c]
2024-11-18 configtool: device info (among other things)
2024-11-19 bank switching tests
2024-11-20 updated v0.3 board drawings to match gerber
2024-11-20 pcb readme
2024-11-22 added v0.3 VGA dongle gerber
2024-11-25 Supported devices
2024-12-08 set flash spi clock dynamically. auto-detect v0.3 hardware
2024-12-22 Added TI-99/4A no-cut mod files
    [pico9918-nocut-ti99-beige-top.stl, pico9918-nocut-ti99-black-top.stl, pico9918-nocut-ti99-bottom.stl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]
2024-12-30 Added ti99 nocut v1.3 with combined JST and FFC connectors
    [bom-pico9918-nocut-ti994a-v1-3.csv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]
2024-12-30 nocut: Removed separate v1.2 PCBs. Added v1.3 pcb, smt bom and cpl files
2025-01-03 Fixed no-cut STL link
2025-01-08 Added no-cut riser assembly jig stl
    [pico9918-nocut-ti99-pcb-spacer-jig.stl]
2025-02-01 no-cut riser: larger cut-out for resistor
    [pico9918-nocut-ti99-pcb-spacer.stl]
2025-03-02 Fixed startup interrupt state
    [config.c, main.c]
2025-03-02 Fixed tms write pio timing - get mode on active edge and data on inactive edge (CreatiVision)
    [main.c]
2025-03-02 updates for 0.4.4: fixed tms write pio timing issue. default to 4 scanline sprites
    [main.c]
2025-04-06 Update no-cut README.md
2025-04-20 Update VGA PIO and DMA to grab two pixels at a time
2025-07-02 Increase gpio drive current on rgb outputs
2025-08-09 apply pico sdk patch
2025-08-09 removed hardcoded pico sdk tag
2025-08-09 force pico9918 board
2025-08-09 board path
2025-08-09 pico sdk
2025-09-10 Fixed Buck Rogers SGM - Read PIO performance
    [main.c]
2025-09-14 macos arm toolchain
2025-09-14 patch pico sdk using cmake
2025-09-14 cmake patch pico sdk
2025-09-14 pico sdk cmake patching
2025-09-14 pico sdk target extension
2025-10-13 reset automatic diagnostics overlays once comms established
    [main.c]
2025-12-14 flush before enabline pio interrupts and after disabling
2025-12-14 back to default rgb gpio max drive current
2025-12-16 attempted interrupt race condition fixes
    [main.c]
2026-01-29 Added SVI-728
    Updated README to include project description, build status, supported devices, hardware variants, configurator details, and licensing information.
2026-02-12 RP2350A temperature probe
2026-02-12 pal cache every frame
2026-02-13 Moved DMA done status update to after the DMA is done
2026-03-08 FFC cable readme
2026-03-08 added MDE1 and solder jumper doc
2026-03-17 Explicit rn package
    [pico9918_v0_3_bom.xlsx]
2026-03-21 Update interrupt timing to be based on scanline output rather than scanline generation
2026-03-27 fixed rp2350a vs b adc pin logic
    [temperature.c]
2026-03-27 pico9918pro board update
2026-04-02 Added v1.3, v2.0, vga and hdmi schematics and gerbers
    [pico9918_hdmi_v1_1_bom.csv, pico9918_hdmi_v1_1_picknplace.csv, pico9918_v1_1_picnplace.csv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]
2026-04-02 Additional pcb details
2026-04-03 reduced end of scanline messages to 1 per frame
2026-04-05 more scart fixes. added virtual black border
    [main.c, vga.c]
2026-04-06 Revert "Merge branch 'main' of github.com:visrealm/pico9918"
    This reverts commit dd2c1b7fb202a35f52631274c8a36d52492863fd, reversing
    changes made to a0ad28c72aa2e2ebe05b0d906e33a36d5d2faccf.
    [config.c, main.c, vga.c]
2026-04-10 Added CreatiVision and NABU no cut mod details
    [pico9918-nocut-creativision-vga-rca-cover.stl, pico9918-nocut-creativision-vga.stl, pico9918-nocut-nabu-hdmi-usb-boot.stl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]
2026-04-12 Added config option for device type affecting clock outputs
2026-04-12 Web configurator option for device type
2026-04-18 Squashed commit of the following:
    commit 1ccffde2f100cdfd7a8b2a639aaca6bfc5f0cc96
    Author: visrealm <code@visualrealmsoftware.com>
    Date: Sun Apr 12 16:38:48 2026 +0930
    Added output to diagnostics. fixed scart frame time counting both fields
    commit 997d3d835d9f1ca143a4645b4979893b5c370f79
    Author: visrealm <code@visualrealmsoftware.com>
    Date: Thu Apr 9 22:01:37 2026 +0930
    scart
    commit cdcbe9e1adcb529ed3ac63ad82d8b8048d7a40b6
    Author: visrealm <code@visualrealmsoftware.com>
    Date: Thu Apr 9 19:03:13 2026 +0930
    removed scart border hack - replaced with adjusted porches
    commit 78ad19c2f30ed99a0720e052c7035b52d5e74ed0
    Author: visrealm <code@visualrealmsoftware.com>
    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
    [config.c, main.c]
2026-04-18 Added GPU frame counter for performance testing
2026-04-18 re-added temperature calc
2026-04-20 Added SCART dongle docs
    [pico9918_scart_v1_3_bom.csv, pico9918_scart_v1_3_picknplace.csv]
2026-04-21 Additional supported devices
    Added project description, contents, and various sections to README.
2026-07-11 Fix config corruption loop from display-change confirmation flow
    [config.c]
2026-07-11 Replace em-dashes with ASCII hyphens in comments and docs
    [vga.c]
2026-07-12 Additional build configurability via optional pico9918_config.cmake file. Should resolve the intent of Issue #28
    [config.c, gpio.h, main.c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]
2026-08-06 Sample MODE at the CSW falling edge rather than 32ns after it
    The write PIO delayed 8 cycles before capturing MODE. At the default
    252MHz clock that is 31.7ns after CSW falls, outside the TMS9918A
    th(WL-A) address hold window of 30ns. The delay bought no debounce in
    return - unlike the rising-edge path it never re-tested CSW - so it
    only spent hold margin.
    Sampling immediately puts it at 4ns. MODE and /CSW share one 74LVC245
    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
2026-08-08 Handle status reads via vrEmuTms9918StatusWasRead so palette mode resets
    [main.c]
2026-08-09 Push the MODE the read state machine acted on instead of re-sampling the pin
2026-08-09 Move clock PIOs to pio0 and pin the host interface to a fixed PIO rate
    [main.c]
2026-08-09 Reject glitches on the CSW falling edge before accepting a write cycle
    [main.c]
2026-08-09 M33 GPU: collapse the run9900 frame and cache the dispatch table base in R10
2026-11-07 Pin the Linux CI runner to ubuntu-24.04 since SDK 2.1.1 pioasm fails under GCC 15
